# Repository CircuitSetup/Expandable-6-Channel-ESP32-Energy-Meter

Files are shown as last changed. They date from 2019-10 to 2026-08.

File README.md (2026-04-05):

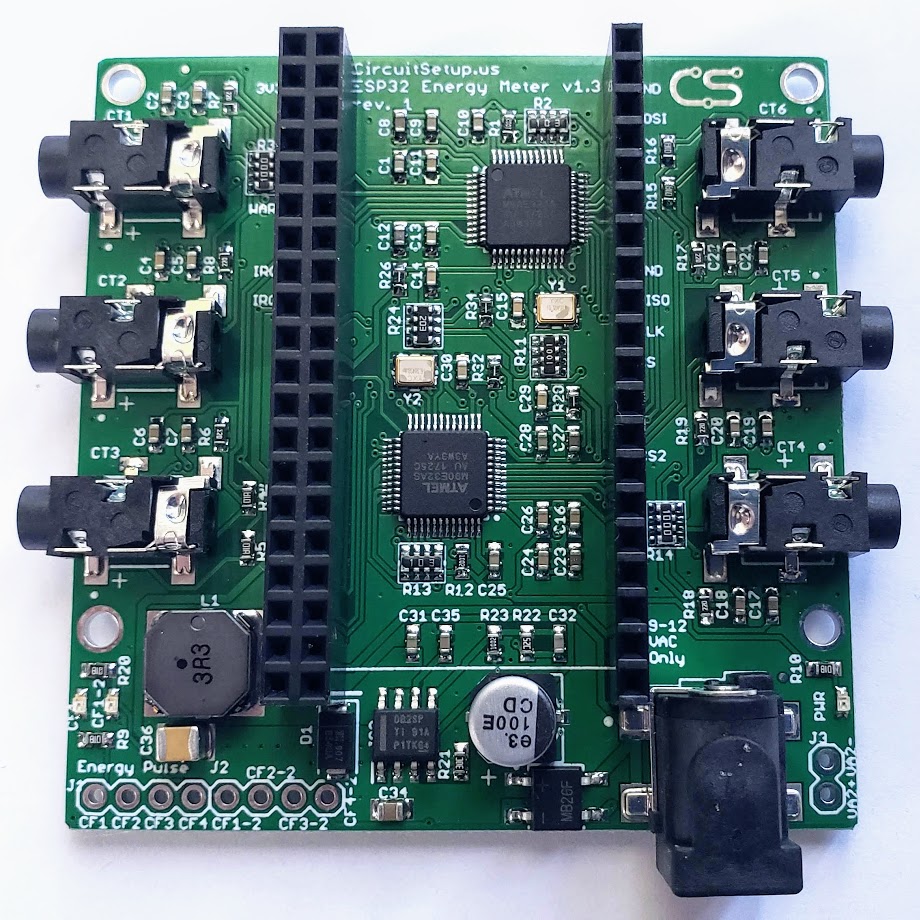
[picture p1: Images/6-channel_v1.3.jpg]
Expandable 6 Channel ESP32 Energy Meter v1.3 Main Board


# CircuitSetup Expandable 6 Channel ESP32 Energy Meter

The CircuitSetup Expandable 6 Channel ESP32 Energy Meter is a real-time power and energy monitor built around two ATM90E32AS metering ICs. The main board measures six current transformer channels and one voltage reference by default, and you can stack up to six add-on boards for a total of 42 current channels. It is a good fit for whole-home monitoring, subpanels, solar, large branch circuits, and multi-voltage or 3-phase projects.

The first AC-AC adapter powers the main board and provides the primary voltage reference. A second voltage can be measured on the main board, and stacked systems can monitor additional voltage references when the hardware is configured for it.

## Table of Contents

- [Quick Start: ESPHome via ESP Web Installer](#quick-start-esphome-via-esp-web-installer)
- [What You Will Need](#what-you-will-need)
- [Setting Up the Meter](#setting-up-the-meter)
- [Software Options](#software-options)
- [FAQ](#faq)
- [More Resources](#more-resources)

## Typical Uses

- North American split-phase 120V/240V 60Hz service: mains, solar, subpanels, and individual circuits
- Single-phase 230V/240V 50Hz or 60Hz systems with a suitable 9VAC or 12VAC AC-AC adapter
- 3-phase systems when each measured phase has the correct voltage reference

## Features

- 6 current channels on the main board
- Expandable to 42 current channels and up to 8 voltage references with add-on boards
- Built around two ATM90E32AS energy metering ICs
- Calculates active power, reactive power, apparent power, power factor, frequency, and temperature
- 16-bit measurement resolution
- 22 ohm burden resistors on each current channel
- Built-in buck converter to power the board and supported ESP32 dev boards
- SPI interface to the ESP32
- Energy pulse outputs, IRQ outputs, warning output, and zero-crossing signals are available on the board
- Typical metering IC accuracy is 0.1 percent with a 6000:1 dynamic range
- Current gain selection is available up to 4x

## Quick Start: ESPHome via ESP Web Installer

The fastest way to get the meter running is to flash ESPHome directly from the [CircuitSetup ESP Web Installer](https://circuitsetup.github.io/ESPWebInstaller/), connect it to your network, then adopt the device into Home Assistant.

### Flash Now With the Web Installer

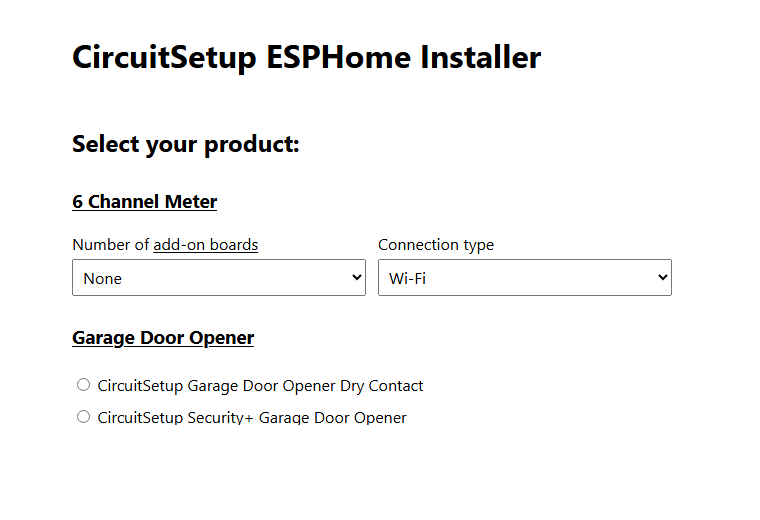
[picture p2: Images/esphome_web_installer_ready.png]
CircuitSetup ESPHome Installer options


1. Open the [CircuitSetup ESP Web Installer](https://circuitsetup.github.io/ESPWebInstaller/)
2. Under `6 Channel Meter`, choose:
   - the number of add-on boards
   - the connection type: `Wi-Fi`, `Ethernet (Lilygo)`, or `Ethernet (Waveshare)`
3. Choose the firmware version
4. Connect the ESP32 to your computer with a USB data cable
5. Click `Connect`, choose the correct serial port, and start the flash
6. If the board does not enter the bootloader automatically, hold the right or `IO0` button while the installer starts
7. If you flashed a Wi-Fi build, provision Wi-Fi after the flash
8. Once the device is online, adjust names, calibration values, and extra sensors as needed

The current Wi-Fi configs in this repo already include `captive_portal`, `esp32_improv`, and `improv_serial`, so the device can be provisioned before it is ever adopted into Home Assistant.

### Adopt Into Home Assistant/ESPHome Device Builder

If you want UI-based management, dashboard imports, OTA updates from Home Assistant, to change default meter/CT names, and do any other YAML editing, install ESPHome Device Builder after the first flash.

1. Open `Settings > Add-ons > Add-on Store`
2. Search for `ESPHome Device Builder`
3. Install it, then click `Start`
4. Click `Open Web UI`

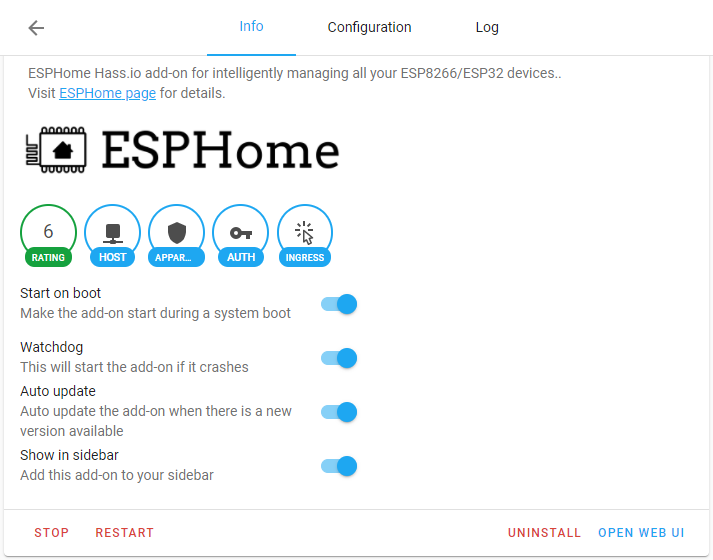
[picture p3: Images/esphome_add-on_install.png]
ESPHome add-on install


The device should then appear in ESPHome Device Builder and in Home Assistant under `Settings > Devices & services`.

For package layout, local copies, calibration files, CS-pin changes, and advanced YAML examples, see [Software/ESPHome/](Software/ESPHome/).

## What You Will Need

### Current Transformers

You can use any mix of supported CTs as long as the secondary output does not exceed 720mV RMS or 33mA. CircuitSetup CTs with mA output work directly with the board and do not require cutting the burden resistor jumpers on the back.

- [SCT-006 20A/25mA Micro CT](https://circuitsetup.us/product/20a-25ma-micro-current-transformer-yhdc-sct-006-6mm/) - 6mm opening, 3.5mm plug
- [SCT-010 80A/26.6mA Mini CT](https://circuitsetup.us/product/80a-26-6ma-mini-current-transformer-yhdc-sct-010-10mm/) - 10mm opening, 3.5mm plug
- [SCT-013-000 100A/50mA CT](https://circuitsetup.us/product/100a-50ma-current-transformer-yhdc-sct-013/) - 13mm opening, 3.5mm plug
- [SCT-016 120A/40mA CT](https://circuitsetup.us/product/120a-40ma-current-transformer-yhdc-sct-016-with-3-5mm-jack-16mm-opening/) - 16mm opening, 3.5mm plug
- [SCT-024 200A/50mA CT](https://circuitsetup.us/product/200a-50ma-current-transformer-yhdc-sct-024-24mm/) - 24mm opening, 3.5mm plug
- Magnelab SCT-0750-100 and similar voltage-output CTs can also be used, but channels using CTs with built-in burden resistors require the matching jumper trace on the back of the board to be cut

### AC-AC Transformer

The meter requires an AC output transformer, not a DC wall adapter.

- North America: [Jameco Reliapro 120V to 9VAC](https://circuitsetup.us/product/jameco-ac-to-ac-wall-adapter-transformer-9-volt-1000ma-black-straight-2-5mm-female-plug/) or a similar 9VAC or 12VAC adapter with a 2.5mm center pin
- Europe and other 230V regions: use a native 230V to 9VAC or 12VAC AC-AC adapter rated for at least 500mA. [OpenEnergyMonitor keeps a useful list here](https://learn.openenergymonitor.org/electricity-monitoring/voltage-sensing/different-acac-power-adapters)

### ESP32

Supported and documented controller options:

- [NodeMCU 32s](https://circuitsetup.us/product/nodemcu-32s-esp32-esp-wroom-32-development-board/)
- Espressif ESP32-DevKitC-32E
- Espressif ESP32-DevKitC-VIE
- Boards with the same 19-pin-per-side pinout as the boards above
- Ethernet options for ESPHome only: [CircuitSetup ESP32-S3 Ethernet Adapter](https://circuitsetup.us/product/6-channel-energy-meter-ethernet-adapter/), [LilyGO T-ETH-Lite ESP32-S3](https://www.lilygo.cc/products/t-eth-lite?variant=43120880779445), or [Waveshare ESP32-S3 ETH](https://www.waveshare.com/esp32-s3-eth.htm?sku=28972)

Boards with different pin maps are not drop-in compatible just because they are "ESP32" boards. For example, ESP32-C6 dev boards use different pins and are not part of the documented support path for this repo.
If you are comparing boards visually, the documented dev boards are usually 19 pins per side, with `3V3` at the upper-left corner and `CLK` at the lower-right corner when installed correctly.

### Software

- [ESPHome](https://esphome.io/components/sensor/atm90e32/) and [Home Assistant](https://www.home-assistant.io/integrations/esphome/) - recommended for most new installs
- [EmonESP](Software/EmonESP/readme.md) and [EmonCMS](https://emoncms.org/) - good if you want EmonCMS or MQTT without Home Assistant
- [CircuitPython library](https://github.com/BitKnitting/CircuitSetup_CircuitPython)
- [MicroPython library](https://github.com/BitKnitting/CircuitSetup_micropython)

## Setting Up the Meter

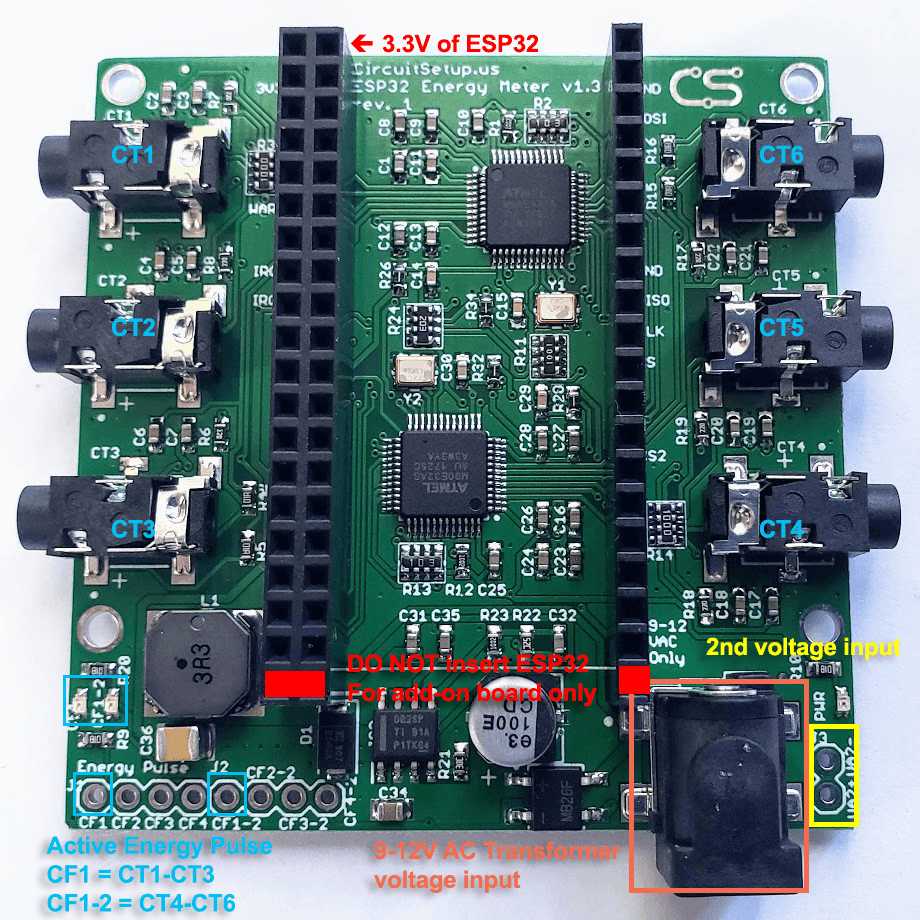
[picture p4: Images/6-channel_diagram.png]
Expandable 6 Channel ESP32 Energy Meter Diagram

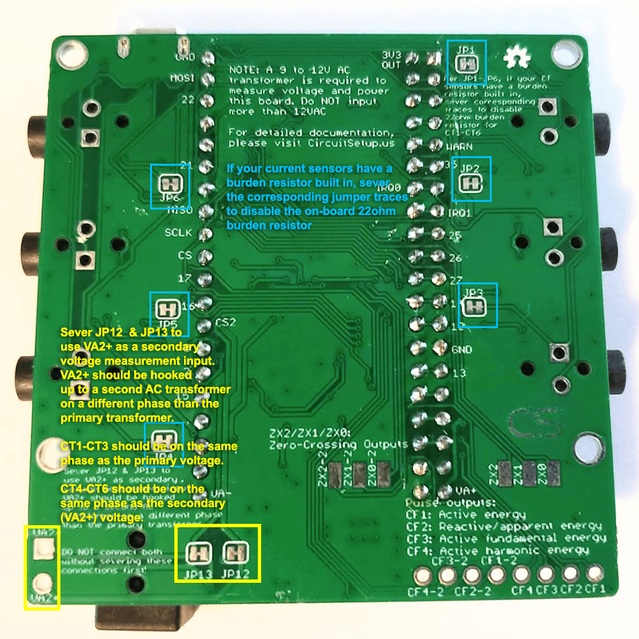
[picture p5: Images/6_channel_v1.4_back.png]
Expandable 6 Channel ESP32 Energy Meter Back Diagram


### Plugging In the ESP32

The board is designed so the ESP32 dev board plugs directly into the meter.

Always insert the ESP32 with `3V3` in the upper-left corner of the meter. The lower pins are used to pass the voltage reference to add-on boards. Plugging the ESP32 into the lower row will likely short the board.

### Main Board SPI and Chip-Select Pins

The meter communicates with the ESP32 over SPI.

Main board SPI pins:

- `CLK` - GPIO18
- `MISO` - GPIO19
- `MOSI` - GPIO23
- `CS1` - GPIO5 for CT1-CT3 and Voltage 1
- `CS2` - GPIO4 for CT4-CT6 and Voltage 2

The 6-channel version of EmonESP in this repo is already set up with the main board pin defaults. Current ESPHome configs for the main board and add-on boards are in [Software/ESPHome](Software/ESPHome).

### Add-On Boards

Each add-on board adds six more CT channels. Up to six add-on boards can be stacked on the main board.

Each add-on board has two CS jumper banks:

- `CS` for CT1-CT3 on that add-on board
- `CS2` for CT4-CT6 on that add-on board

Only choose one pin per bank. The default jumper positions used by the installer and repo configs are:

| Add-on board | `CS` for CT1-CT3 | `CS2` for CT4-CT6 |
| --- | --- | --- |
| 1st add-on | GPIO0 | GPIO16 |
| 2nd add-on | GPIO27 | GPIO17 |
| 3rd add-on | GPIO2 | GPIO21 |
| 4th add-on | GPIO13 | GPIO22 |
| 5th add-on | GPIO14 | GPIO25 |
| 6th add-on | GPIO15 | GPIO26 |

GPIO2 can interfere with programming on some ESP32 boards. If you temporarily cannot flash the ESP32 while that jumper is connected, disconnect that add-on board or move the jumper while programming, then restore the expected setting.

If you change jumper positions from the defaults, update the matching `cs_pin` values in your ESPHome config. See [Software/ESPHome/README.md](Software/ESPHome/README.md) for examples.

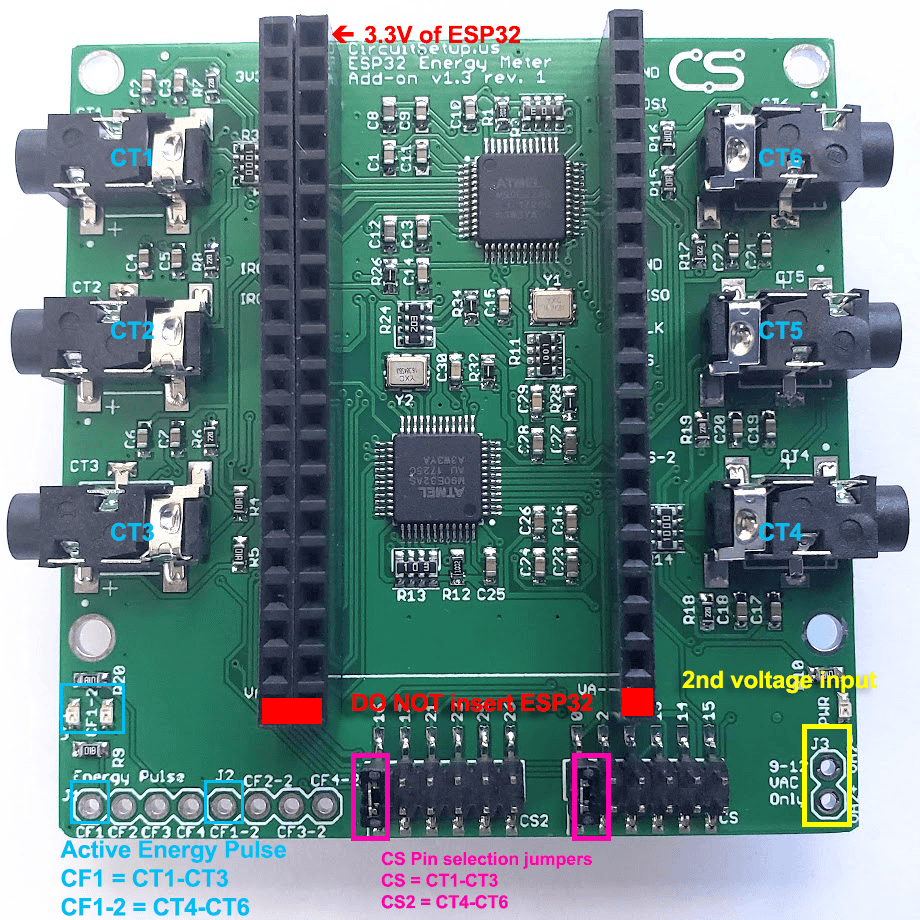
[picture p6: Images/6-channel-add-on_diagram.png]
Expandable 6 Channel ESP32 Energy Meter Add-on Diagram


### CT Compatibility, Burden Resistors, and `JP1-JP6`

Each current channel on the board has an onboard burden resistor. That is correct for CircuitSetup CTs with mA output.

Only cut the matching rear jumper trace for a CT channel if that CT already has its own burden resistor, which is usually the case for voltage-output CTs such as 1V-output models.

In practice:

- CircuitSetup SCT-006, SCT-010, SCT-013-000, SCT-016, and SCT-024 CTs do not require cutting `JP1-JP6`
- 1V-output CTs such as SCT-013-030 or SCT-013-050 do require cutting the matching jumper trace for the channel they are connected to
- If you are mixing CT types, only cut the jumper traces for the specific channels using CTs with built-in burden resistors

### Common Calibration Starting Values

Each current channel can use its own calibration value. In the current ESPHome configs that means setting `current_cal_ct1`, `current_cal_ct2`, and so on for the main board, plus the add-on board calibration variables where needed.

Common starting values:

| Sensor | Calibration value |
| --- | --- |
| SCT-006 20A/25mA | `11143` |
| SCT-013-030 30A/1V | `8650` |
| SCT-013-050 50A/1V | `15420` |
| SCT-010 50A/16.6mA | `41334` |
| SCT-010 80A/26.6mA | `41660` |
| SCT-013-000 100A/50mA | `27518` |
| SCT-016 120A/40mA | `41787` |
| SCT-024 200A/100mA | `27518` |
| SCT-024 200A/50mA | `55036` |
| Jameco 9VAC transformer | `7305` |

These are good starting points, not guaranteed final values. If you want tighter accuracy, use the ESPHome semi-automatic calibration workflow described below.

### Measuring More Than 65A on One Channel

The ATM90E32 current register tops out at `65.535A` before scaling. If you expect to measure more than that on one channel, divide the CT calibration value and multiply the reported current and power in software. Current examples are already documented in [Software/ESPHome/README.md](Software/ESPHome/README.md) and shown in [Software/ESPHome/6chan_energy_meter_main_board.yaml](Software/ESPHome/6chan_energy_meter_main_board.yaml).

For 200A service this usually means you are monitoring a larger CT but scaling it in software so the meter stays within range.

### Power Calculations and Board Revisions

The board uses voltage references to calculate power, power factor, and the other metering values.

- v1.1 used one voltage channel per ATM90E32 by default, so some power calculations had to be done in software unless registers were remapped
- v1.2 and v1.3 added `JP8-JP11` so voltage channels could be tied together. Most v1.3 boards shipped with those connections already joined
- v1.4 and later removed `JP8-JP11` and route those voltage channels internally on the PCB

### Measuring Dual-Pole 240V Circuits on Split-Phase Service

For split-phase systems, a 240V load has two hot legs. There are three practical ways to measure it:

1. Measure one hot leg with one CT and double the current and power in software. This uses the fewest channels but is the least accurate.
2. Measure each hot leg with its own CT. This is the most flexible option.
3. If the wiring layout allows it and the CT opening is large enough, pass both hot legs through a single CT in opposite directions.

If a CT is not in phase with its voltage reference, current and power will read negative. On split-phase systems that usually means the CT is flipped around the wrong conductor.

### Measuring a Second Voltage

The `VA2` pads next to the power jack on the main board, and the `VA2` pads on add-on boards, let you measure a second voltage reference.

To do that:

1. Cut `JP12` and `JP13` on v1.3 and newer boards, or `JP7` on older revisions
2. Use a second AC-AC transformer, ideally the same model as the primary one
3. Connect that second transformer to the opposite phase you want to reference
4. Add a suitable connector or pigtail to the `VA2+` and `VA2-` pads

When those voltage jumpers are cut:

- CT1-CT3 stay referenced to the primary voltage
- CT4-CT6 use the `VA2` voltage reference

That means CT4-CT6 should measure circuits on the same phase as `VA2`, or the CT direction must be reversed so the current is in phase with the voltage reference.

On add-on boards, the primary voltage normally comes from the main board. If you wire a separate `VA2` voltage reference on an add-on board, that secondary voltage is used for CT4-CT6 on that add-on board.

### Measuring 3-Phase Power

For accurate 3-phase power metering you need a matching voltage reference for each measured phase.

The cleanest 3-phase setup is:

- one main board, v1.4 or newer
- one add-on board
- three AC-AC transformers, one per phase
- headers or connectors installed on the `VA2` pads as needed
- `JP12` and `JP13` cut on the boards where separate voltage references are being used

The first transformer connected to the main board also powers the electronics and ESP32, so it should provide at least 500mA.

With that hardware:

- main board CT1-CT3 can reference phase 1
- main board CT4-CT6 can reference phase 2
- add-on board CT1-CT6 can reference phase 3, depending on how you feed voltage to that board

An alternate 3-phase approach is to use two add-on boards and feed a separate transformer into each add-on board. In that setup, the bottom `VA-` and `VA+` feed from the main board is no longer used for those add-ons, and you wire the new transformer to the `VA2` pads on each add-on instead.

If a CT is tied to a different phase than its voltage reference, active power and power factor will be wrong even if current itself looks reasonable.

## Software Options

### ESPHome and Home Assistant

ESPHome is still the recommended software path. If you just want to get firmware onto the meter, use the quick-start section above. The rest of this section covers what the maintained ESPHome configs already include after the device is flashed.

Useful references:

- [Getting Started with ESPHome and Home Assistant](https://esphome.io/guides/getting_started_hassio/)
- [ESPHome ATM90E32 docs](https://esphome.io/components/sensor/atm90e32/)

### What the Default ESPHome Config Already Includes

The current repo configs are built for the current ESPHome workflow, not the older legacy setup:

- `dashboard_import` so the device can be adopted into ESPHome Device Builder
- `name_add_mac_suffix: true` so multiple identical meters do not collide on the network
- `ota: - platform: esphome` for current OTA updates
- `captive_portal`, `esp32_improv`, and `improv_serial` on Wi-Fi builds for provisioning
- `time: - platform: homeassistant` in the shared packages used by the standard configs

After the first flash:

- Wi-Fi builds can be provisioned from the browser, via Improv, or through the fallback captive portal if the device is not yet on your network
- Ethernet builds come up on your wired network once flashed and connected
- The device should appear in ESPHome Device Builder and in Home Assistant under `Settings > Devices & services`
- You can edit the imported YAML inside ESPHome Device Builder, or copy the files locally from [Software/ESPHome](Software/ESPHome) if you prefer to manage everything yourself

If you want the maintained package-based configs, start from the files in [Software/ESPHome](Software/ESPHome). If you want more control, use [Software/ESPHome/README.md](Software/ESPHome/README.md) as the advanced reference for package layout, calibration files, CS-pin changes, and example configs.

### ESPHome Calibration

Default calibration values are usually good enough to get started, but calibration is strongly recommended if you are using custom CTs, a different AC-AC transformer, longer CT leads, or if you want especially accurate readings.

On the main board, calibration is done through two separate ATM90E32 chips, not one 6-channel block. `main_meter_id1` / `Meter 1-3` handles CTs `1-3`, and `main_meter_id2` / `Meter 4-6` handles CTs `4-6`. Each `Run ... Calibration` button in Home Assistant acts on only one of those chips, so calibrate CTs `1-3` and CTs `4-6` separately.

In the CircuitSetup YAML, the normal starting points are `current_cal_ct1` through `current_cal_ct6`, plus `voltage_cal1` and `voltage_cal2` in the top-level config file you flashed or imported from [Software/ESPHome](Software/ESPHome). Under the hood, those map to ESPHome's `gain_ct` and `gain_voltage` values for each ATM90E32 phase. [Software/ESPHome/calibration/6chan_main_calibration.yaml](Software/ESPHome/calibration/6chan_main_calibration.yaml) adds the Home Assistant calibration buttons and the runtime reference number entities. [Software/ESPHome/calibration/6chan_main_offset_calibrations.yaml](Software/ESPHome/calibration/6chan_main_offset_calibrations.yaml) is where copied offset values can be persisted in YAML.

To use the semi-automatic calibration workflow, make sure `offset_calibration` and `gain_calibration` are set to `"true"` and that the calibration package is included. After the meter is adopted into Home Assistant, open the meter device page. There you will see:

- `${main_meter_name1} Ref V 1` and `CT1 Ref Current` through `CT3 Ref Current` for the first ATM90E32
- `${main_meter_name2} Ref V 2` and `CT4 Ref Current` through `CT6 Ref Current` for the second ATM90E32
- `Run ... Offset Cal`, `Run ... Power Offset Cal`, `Run ... Gain Cal`, and matching `Clear ...` buttons for each chip

If you renamed the meter groups in YAML, the button labels will follow those names instead of the default `Meter 1-3` and `Meter 4-6`.

In practice:

- gain calibration fixes scaling when the meter reads high or low under a known load
- offset calibration fixes false zero-level readings when current or voltage should be at or very near zero
- power-offset calibration fixes false power readings when voltage is present but CT current is zero

Recommended workflow:

1. Start with the closest known values for your CTs and AC transformer by setting `current_cal_ct1` through `current_cal_ct6` and `voltage_cal1`/`voltage_cal2` to the nearest matching starting values.
2. Open the meter device page in Home Assistant and choose which ATM90E32 you are calibrating: `Meter 1-3` for CTs `1-3`, or `Meter 4-6` for CTs `4-6`. For that chip, phase A/B/C in the ESPHome logs correspond to CT1/CT2/CT3 or CT4/CT5/CT6 respectively.
3. For gain calibration, restore the meter to normal wiring, apply a stable known load, and use a trusted reference meter or clamp meter to get the real voltage and current. Enter that chip's real voltage into its `Ref V` field. For the CircuitSetup 6-channel meter, that reference voltage is used across that chip's phases. Then enter the real current into the matching `CTx Ref Current` field for each CT you want to calibrate.
4. Press that chip's `Run ... Gain Cal` button. ESPHome then logs a calibration table showing phase A/B/C, measured voltage, measured current, reference voltage, reference current, and the old-to-new `V_gain` and `I_gain` values for that chip. If a reference voltage or reference current is left at `0`, ESPHome skips recalculating that part and logs a warning instead.
5. Open the ESPHome logs and copy the reported values back into YAML. In the standard workflow that means opening `LOGS` in ESPHome Device Builder for the device, but serial logs or `esphome logs` work too. For `Meter 1-3`, map the logged gain results back to `voltage_cal1` and `current_cal_ct1` through `current_cal_ct3`. For `Meter 4-6`, map them back to `voltage_cal2` and `current_cal_ct4` through `current_cal_ct6`.
6. Only run offset calibration if idle baselines are not clean. For this step, the ATM90E32 button code and docs both expect current and voltage inputs to be at `0`, so the practical approach is USB power only with the AC transformer and CTs disconnected. Press the matching `Run ... Offset Cal` button for the chip you want to clean up. The logs will show a table of `offset_voltage` and `offset_current` for phases A/B/C on that chip.
7. Only run power-offset calibration if power still shows a small non-zero value with voltage present but CT current at zero. For this step, the voltage reference should be connected but CT current should be `0`. Press that chip's `Run ... Power Offset Cal` button. The logs will show `offset_active_power` and `offset_reactive_power` for phases A/B/C on that chip.
8. If you want offset values persisted in config, copy them into [Software/ESPHome/calibration/6chan_main_offset_calibrations.yaml](Software/ESPHome/calibration/6chan_main_offset_calibrations.yaml). ESPHome's button logs refer to `gain_ct`, `gain_voltage`, `offset_voltage`, `offset_current`, `offset_active_power`, and `offset_reactive_power` under each `phase_x`; in this repo those results map back to the `current_cal_ctX` and `voltage_cal1/2` substitutions plus the offset include file.
9. After those values are saved in YAML, press the matching `Clear ...` buttons for that same chip so the temporary calibration values stored in flash no longer override your YAML. The component stores gain, offset, and power-offset calibration values in memory and applies them immediately, so clearing them is the step that hands control back to the YAML values.

What the logs will show:

- gain calibration logs a table with `V_meas (V)`, `I_meas (A)`, `V_ref`, `I_ref`, `V_gain (old→new)`, and `I_gain (old→new)` for phases A/B/C of the selected chip
- offset calibration logs a table of `offset_voltage` and `offset_current` for phases A/B/C of the selected chip
- power-offset calibration logs a table of `offset_active_power` and `offset_reactive_power` for phases A/B/C of the selected chip
- the button press itself also logs guidance such as `Use gain_ct: & gain_voltage:` or `Use offset_voltage: & offset_current:` and reminds you about the required wiring conditions for offset and power-offset calibration

The key output from semi-automatic calibration is written to the ESPHome logs through `logger`, not into the Home Assistant entity state itself. The normal CircuitSetup workflow is: run the correct chip's calibration button from the Home Assistant device page, watch the output in ESPHome Device Builder `LOGS`, copy the values into YAML, clear the stored chip calibration for that same button group, then reboot or reload and verify against your reference meter.

Useful references:

- [ESPHome ATM90E32 calibration docs](https://esphome.io/components/sensor/atm90e32/#calibration)
- [Software/ESPHome/README.md](Software/ESPHome/README.md)

### Home Assistant Energy Dashboard

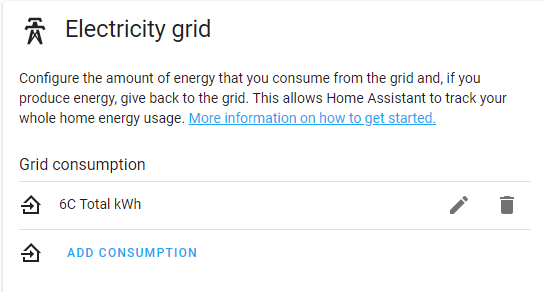
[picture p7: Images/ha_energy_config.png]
Home Assistant Energy Config


The current repo configs already use the right Home Assistant time source and current energy-sensor metadata. If you are building your own sensors, use the same pattern as the current configs:

```yaml
sensor:
  - platform: total_daily_energy
    name: ${friendly_name} Total kWh
    power_id: totalWattsMain
    filters:
      - multiply: 0.001
    unit_of_measurement: kWh
    device_class: energy
    state_class: total_increasing
```

If you are using the standard package configs in this repo, `time: - platform: homeassistant` is already included and does not need to be added again.

Helpful example configs:

- Main board only: [Software/ESPHome/6chan_energy_meter_main_board.yaml](Software/ESPHome/6chan_energy_meter_main_board.yaml)
- Solar plus house example: [Software/ESPHome/examples/6chan_energy_meter_house_solar_ha_kwh.yaml](Software/ESPHome/examples/6chan_energy_meter_house_solar_ha_kwh.yaml)
- 3-phase example: [Software/ESPHome/examples/6chan_energy_meter_3-phase_ethernet.yaml](Software/ESPHome/examples/6chan_energy_meter_3-phase_ethernet.yaml)

In Home Assistant:

1. Open `Settings > Energy`
2. Add your total import sensor under the electricity grid section
3. Add return-to-grid and solar production sensors if you are tracking export or generation
4. Add per-circuit energy sensors if you want individual device or branch circuit tracking

### Optional: InfluxDB and Grafana

If you want long-term storage outside the default Home Assistant recorder, the easiest path is to expose the meter data to Home Assistant first and then use the Home Assistant InfluxDB integration.

- [Home Assistant InfluxDB integration](https://www.home-assistant.io/integrations/influxdb/)

### EmonESP and EmonCMS

EmonESP is still a good option if your main goal is sending data to a local EmonCMS install, [emoncms.org](https://emoncms.org/), or MQTT without making Home Assistant the center of the system.

The 6-channel EmonESP files in this repo already include the correct pin defaults for the main board and support calibration changes from the web UI.

Key points:

- You must use an ESP32
- You can build it with Arduino IDE or PlatformIO
- It requires the [CircuitSetup ATM90E32 Arduino library](https://github.com/CircuitSetup/ATM90E32)
- The 6-channel-specific notes are in [Software/EmonESP/readme.md](Software/EmonESP/readme.md)
- The broader EmonESP setup flow is documented here: [Split Single Phase EmonESP setup](https://github.com/CircuitSetup/Split-Single-Phase-Energy-Meter/tree/master/Software/EmonESP)

If you need separate voltage calibration for a specific add-on-board voltage channel in EmonESP, note the local EmonESP readme: by default the add-on voltage channel uses the main board calibration unless you define a separate variable in `energy_meter.cpp`.

### CircuitPython and MicroPython

If you want to build your own application stack instead of using ESPHome or EmonESP, these community libraries are available:

- [CircuitSetup CircuitPython library](https://github.com/BitKnitting/CircuitSetup_CircuitPython)
- [CircuitSetup MicroPython library](https://github.com/BitKnitting/CircuitSetup_micropython)

## FAQ

**Q: One CT is reading low, or not reading at all. What should I check first?**

**A:** First make sure the CT plug is fully seated. The jacks can be tight, and the connector often needs to be pushed in until it clicks. If one channel still reads low after that, swap CTs between channels to find out whether the issue follows the CT or stays with the board jack.

**Q: Does the 6-channel meter work outside North America?**

**A:** Yes. Set the line frequency for your system and use the correct AC-AC transformer for your mains voltage. For 230V or 240V systems, use a native 230V to 9VAC or 12VAC adapter when possible instead of a step-down transformer plus a US wall adapter.

**Q: Can I use a 230V to 120V step-down transformer with a US 9VAC adapter?**

**A:** It can work, but it is not the preferred setup. A native 230V to 9VAC or 12VAC AC-AC adapter is simpler, cleaner, and usually the better long-term choice. If you do use a different adapter, plan to calibrate the voltage.

**Q: I am getting a negative value on one current channel. What is happening?**

**A:** The CT is usually backwards on the conductor. Turn the CT around. If every CT is negative, the AC transformer phase is probably reversed.

**Q: I see a small negative value at no load, but positive values under load. Is that normal?**

**A:** That is usually offset error, not a wiring failure. Run the voltage and current offset calibration in ESPHome if you want the cleanest fix. If you just need to clamp small negative values to zero in a template, that is also possible, but offset calibration is the better solution.

**Q: Can I extend the CT wires?**

**A:** Yes. A short 3.5mm extension cable or a clean custom extension usually works fine. After adding a longer run, recalibrate if you want the best accuracy.

**Q: Can I use other CTs with this meter?**

**A:** Usually yes, as long as the CT secondary output stays within the supported range. The important limits are the CT output, not the brand name. If the CT has a built-in burden resistor or a voltage output such as 1V, cut the matching jumper trace on the board for that channel.

**Q: Can I use SCT-024 200A CTs on the 6-channel meter?**

**A:** Yes, but you still need to respect the meter input range. With the newer 200A/50mA SCT-024, the practical maximum current you should measure directly without additional scaling is about 132A on one channel. If you need to monitor more than that, use the software scaling approach described above.

**Q: How do I know whether to cut `JP1-JP6`?**

**A:** Leave the jumper trace intact for mA-output CTs such as CircuitSetup SCT-006, SCT-010, SCT-013-000, SCT-016, and SCT-024. Cut the matching jumper trace only for channels using CTs with built-in burden resistors, which usually means voltage-output CTs such as 1V models.

**Q: Do CTs need mono 3.5mm plugs, or will stereo plugs work?**

**A:** The board uses the CT signal on the tip and sleeve. A CT with a stereo 3.5mm plug usually works fine as long as the CT output is wired correctly and the electrical output itself is compatible. The plug style matters less than the CT secondary type and wiring.

**Q: Can I mix different CT types on one meter?**

**A:** Yes. That is a common setup. Give each current channel the correct calibration value for the CT on that channel. Do not assume the same calibration applies to every CT just because they are on the same board.

**Q: My add-on board shows `NA`, or I see `connection to ATM90E32 failed`. What should I check?**

**A:** Start with the basics:

- confirm you flashed the firmware for the correct add-on count
- confirm the add-on board jumper positions match the expected CS pair for that stack position
- confirm the add-on board is fully seated
- if you changed jumper positions, confirm the matching `cs_pin` values were also changed in ESPHome

If the main board works by itself and both boards stop reporting as soon as the add-on is installed, the jumper selection or physical seating is usually the first thing to verify.

**Q: Which ESP32 dev boards are supported?**

**A:** Use a NodeMCU 32s, an ESP32-DevKitC-32E, an ESP32-DevKitC-VIE, or another board with the same pinout. Ethernet is supported with the documented LilyGO or Waveshare ESP32-S3 options plus the proper adapter and matching YAML. Boards with different pin maps, including ESP32-C6 dev boards, are not documented drop-in replacements for this repo.

**Q: Can I connect the meter to Ethernet?**

**A:** Yes, with the documented ESPHome Ethernet options. Start with:

- [Software/ESPHome/6chan_energy_meter_main_ethernet.yaml](Software/ESPHome/6chan_energy_meter_main_ethernet.yaml)
- [Software/ESPHome/6chan_energy_meter_main_ethernet_waveshare.yaml](Software/ESPHome/6chan_energy_meter_main_ethernet_waveshare.yaml)

Use the matching firmware in the web installer for `Ethernet (Lilygo)` or `Ethernet (Waveshare)`.

**Q: How do I set up solar and return-to-grid tracking?**

**A:** Use separate power calculations for house import, solar generation, and return-to-grid export. The best starting point is the maintained example here:

- [Software/ESPHome/examples/6chan_energy_meter_house_solar_ha_kwh.yaml](Software/ESPHome/examples/6chan_energy_meter_house_solar_ha_kwh.yaml)

**Q: How can I do calculations across two different meters in Home Assistant?**

**A:** Create a template helper or template sensor in Home Assistant and do the math there. Use each meter's total power or energy sensor as inputs, then expose the calculated sensor back to the Energy dashboard if needed.

**Q: My older ESPHome config no longer compiles after updating ESPHome. What is the easiest fix?**

**A:** The repo has moved forward with the current ESPHome workflow, including `esp-idf`, `dashboard_import`, current OTA syntax, and the maintained package structure in [Software/ESPHome](Software/ESPHome). The fastest path is usually to start from the current repo config or reflash with the [CircuitSetup ESP Web Installer](https://circuitsetup.github.io/ESPWebInstaller/) and then merge your custom names and calibration values back in.

## More Resources

- [CircuitSetup ESP Web Installer](https://circuitsetup.github.io/ESPWebInstaller/)
- [ESPHome ATM90E32 docs](https://esphome.io/components/sensor/atm90e32/)
- [Getting Started with ESPHome and Home Assistant](https://esphome.io/guides/getting_started_hassio/)
- [Home Assistant ESPHome integration](https://www.home-assistant.io/integrations/esphome/)
- [Home Assistant Energy docs](https://www.home-assistant.io/docs/energy/)
- [Software/ESPHome/README.md](Software/ESPHome/README.md)
- [Software/EmonESP/readme.md](Software/EmonESP/readme.md)
- [Digiblur video on calibration and ESPHome setup](https://www.youtube.com/watch?v=BOgy6QbfeZk)
- [DIY Home Power and Solar Energy Dashboard with Home Assistant and ESPHome](https://www.youtube.com/watch?v=n2XZzciz0s4)
- [TH3D video with add-on board setup](https://www.youtube.com/watch?v=zfB4znO6_Z0)

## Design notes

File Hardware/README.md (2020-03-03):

## Expandable 6 Channel Energy Meter Change Log
**3/2/2020 - v1.4 rev1**
- Changed micro-hdmi connector to through-hole
- Changed spacing on VA2+/VA2- (voltage 2 connection) to 3.5mm to allow for standard screw connectors

**12/16/2019 – v1.4**
- Added optional micro-hdmi connection to connect the current transformer remote board. This allows for all 6 current transformer connections to connect to a remote pcb, which then connects to the main board via 1 micro-hdmi cable. Instead of 6 wires coming out of the meter, there can now be 1.
- Added current transformer remote pcb
- Removed JP8-JP11 and connected all voltage channels together for each ATM90E32

**10/15/2019 – v1.3 rev1**
- Added voltage divider on ground for voltage channel 2
- Added JP12 & JP13 to disconnect voltage channel 1 from 2

**10/1/2019 – v1.3**
- Added voltage divider on ground for voltage channel 1
- Added 20k pullup for voltage channel 1
- Changed all voltage dividers to 20k and 1k so voltage input from a 12v AC transformer is around 650mV - this allows more voltage in than previous versions, lowering the voltage calibration
- Removed C37

**8/1/2019 – v1.2**
- Added C37 to connect neutral and DC ground
- Added solder jumpers JP8JP12 to connect all voltage channel inputs together

**6/1/2019 – v1.1**
- Initial public release

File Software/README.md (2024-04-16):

### Software
The following are various implementations that can be used with the 6 Channel Energy Meter. Instructions for [setting up software for the meter is located here](https://github.com/CircuitSetup/Expandable-6-Channel-ESP32-Energy-Meter#setting-up-software).
- ESPHome - Example configuration files
- EmonCMS - Device config files (these are now included with the device module for EmonCMS)
- EmonESP - ESP software that runs on the meter's ESP32, and sends data to EmonCMS or via MQTT
- Grafana - Dashboard examples

### Libraries
These are used to communicate directly with the ATM90E32 IC's used with the 6 channel meter. If you want to build your own software, you will need one of these.
- [Arduino/ESP32](https://github.com/CircuitSetup/ATM90E32)
- [CircuitPython](https://github.com/BitKnitting/CircuitSetup_CircuitPython)
- [MicroPython](https://github.com/BitKnitting/CircuitSetup_micropython)

### User Created Projects
- [CS/ESPHome](https://github.com/sillygoose/cs_esphome) - Python data collection utility. Sensor data is sourced using the ESPHome API and stored in an InfluxDB database. Grafana dashboard included.
- [ESPSense](https://github.com/cbpowell/ESPSense) - Can be used to send 6 Channel Energy Meter data via ESPHome to your Sense Home Energy Monitor software
- [Raspberry Pi to MQTT](https://github.com/tsaitsai/circuitsetup_energy_to_mqtt) - Hook up a 6 channel meter to a Raspberry Pi (in place of an ESP32) and send data over MQTT
- [6 Channel Energy Meter with a wired ethernet connection (WT32-ETH01)](https://community.home-assistant.io/t/wt32-eth01-with-esphome-driving-circuitsetup-expandable-6-channel-esp32-energy-meter-main-board/709027) - Wiring and ESPHome config for using the 6 channel meter with ethernet instead of WiFi.

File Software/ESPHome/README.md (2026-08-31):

# ESPHome Configuration for Expandable 6-Channel ESP32 Energy Meter

This folder contains [ESPHome](https://esphome.io) configuration files used to monitor power and energy via the CircuitSetup Expandable 6-Channel Energy Meter. These configurations support flexible deployments - with or without add-on boards - as well as Wi-Fi or Ethernet connections. Many files use `!include` statements to modularize calibration, sensor definitions, power quality metrics, and device status.

---

## Compiled Firmware

[See here to flash your ESP32](https://circuitsetup.github.io/ESPWebInstaller/)

---

## 📁 Base Config Files

| File | Description |
|---|---|
| `6chan_common.yaml` | Base shared configuration: sets platform (`esp32`), SPI, includes time and API components. Meant to be included in Wi-Fi-based setups. |
| `6chan_common_ethernet.yaml` | Same as `6chan_common.yaml`, but for the [Lilygo T-ETH-Lite ESP32S3](https://lilygo.cc/products/t-eth-lite) and the [CircuitSetup 6 Channel Energy Meter Ethernet Adapter](https://circuitsetup.us/product/6-channel-energy-meter-to-lilygo-t-eth-lite-esp32s3-ethernet-adapter/) . |
| `6chan_common_ethernet_waveshare.yaml` | Ethernet base config for the Waveshare ESP32-S3-ETH and CircuitSetup Ethernet WS adapter. |
| `6chan_energy_meter_main_board.yaml` | Full configuration for monitoring only the main board's 6 channels via Wi-Fi. |
| `6chan_energy_meter_main_ethernet.yaml` | Ethernet-based variant of `6chan_energy_meter_main_board.yaml` (Lilygo adapter). |
| `6chan_energy_meter_main_ethernet_waveshare.yaml` | Ethernet-based variant of `6chan_energy_meter_main_board.yaml` (Waveshare adapter). |
| `6chan_energy_meter_1-addon.yaml` | Main board + 1 add-on board (12 channels) over Wi-Fi. |
| `6chan_energy_meter_1-addon_ethernet.yaml` | Main board + 1 add-on board (12 channels) over Ethernet (Lilygo adapter). |
| `6chan_energy_meter_1-addon_ethernet_waveshare.yaml` | Main board + 1 add-on board (12 channels) over Ethernet (Waveshare adapter). |
| `6chan_energy_meter_2-addons.yaml` | Main board + 2 add-on boards (18 channels) over Wi-Fi. |
| `6chan_energy_meter_2-addons_ethernet.yaml` | Main board + 2 add-on boards (18 channels) over Ethernet (Lilygo adapter). |
| `6chan_energy_meter_2-addons_ethernet_waveshare.yaml` | Main board + 2 add-on boards (18 channels) over Ethernet (Waveshare adapter). |
| `6chan_energy_meter_3-addons.yaml` | Main board + 3 add-on boards (24 channels) over Wi-Fi. |
| `6chan_energy_meter_3-addons_2-voltages.yaml` | Main board + 3 add-on boards (24 channels) with second-voltage monitoring enabled. |
| `6chan_energy_meter_3-addons_ethernet.yaml` | Main board + 3 add-on boards (24 channels) over Ethernet (Lilygo adapter). |
| `6chan_energy_meter_3-addons_ethernet_waveshare.yaml` | Main board + 3 add-on boards (24 channels) over Ethernet (Waveshare adapter). |
| `6chan_energy_meter_4-addons.yaml` | Main board + 4 add-on boards (30 channels) over Wi-Fi. |
| `6chan_energy_meter_4-addons_ethernet.yaml` | Main board + 4 add-on boards (30 channels) over Ethernet (Lilygo adapter). |
| `6chan_energy_meter_4-addons_ethernet_waveshare.yaml` | Main board + 4 add-on boards (30 channels) over Ethernet (Waveshare adapter). |
| `6chan_energy_meter_5-addons.yaml` | Main board + 5 add-on boards (36 channels) over Wi-Fi. |
| `6chan_energy_meter_5-addons_ethernet.yaml` | Main board + 5 add-on boards (36 channels) over Ethernet (Lilygo adapter). |
| `6chan_energy_meter_5-addons_ethernet_waveshare.yaml` | Main board + 5 add-on boards (36 channels) over Ethernet (Waveshare adapter). |
| `6chan_energy_meter_6-addons.yaml` | Main board + 6 add-on boards (42 channels) over Wi-Fi. |
| `6chan_energy_meter_6-addons_ethernet.yaml` | Main board + 6 add-on boards (42 channels) over Ethernet (Lilygo adapter). |
| `6chan_energy_meter_6-addons_ethernet_waveshare.yaml` | Main board + 6 add-on boards (42 channels) over Ethernet (Waveshare adapter). |

---

## Helper configuration contract

Official top-level meter configurations publish `csemh_config_contract: "2"`.
Generic add-on totals use stable IDs `totalAmps`, `totalWatts`, and
`totalEnergyDaily`. Main-only configurations retain `totalAmpsMain` and
`totalWattsMain`, plus `totalEnergyDaily`. Status text entities are
diagnostic and disabled by default so the helper can manage their visibility
consistently.

Manually composed ESPHome configurations may retain or include the full
power-quality set, including harmonic power and peak current. CircuitSetup
Energy Meter Helper intentionally omits harmonic power and peak current from
its managed configuration.

---

## 📂 calibration/

When these files are included, and calibration is enabled, semi-automatic calibration can be done for each current and voltage channel by providing a current and voltage reference. Calculated values for offset and gain stored in memory take priority over config values.
To save calculated calibration values, copy them from the ESPHome logs to your config then use the clear buttons to clear the calibration values from memory

[See details on semi-automatic calibrations here](https://esphome.io/components/sensor/atm90e32.html#calibration)

| File | Description |
|---|---|
| `6chan_xxxx_calibration.yaml` | Enables calibration buttons for gain, power offset, current/voltage offset, and clear buttons for each |
| `6chan_xxxx_offset_calibrations.yaml` | Offset calibration values fine tuned via the output of the semi-automatic calibrations. Values should be copied in from the meter's ESPHome log |

---

## 📂 meter_sensors/

Default current, power (watts), and voltage sensor entities per meter board
[More details on each sensor here](https://esphome.io/components/sensor/atm90e32.html#configuration-variables)

---

## 📂 status_fields/

These fields display the status of each CT, or phase, with a short text description. [See more details here](https://esphome.io/components/sensor/atm90e32.html#text-sensor)

---

## 📂 power_quality/

Contains power quality values that are available for each phase, and can be enabled per meter board. Enabling these on every current channel is possible, but will produce a lot of data and sensors that are likely not needed. They include reactive_power, apparent_power, harmonic_power, power_factor, phase_angle, peak_current
[More details on each sensor here](https://esphome.io/components/sensor/atm90e32.html#configuration-variables)

---

## 📂 examples/

Pre-configured use cases to jumpstart your setup.

| File | Description |
|---|---|
| `6chan_energy_meter_3-phase_ethernet.yaml` | Configuration for 3-phase measurement with Ethernet. Uses main board + 1 add-on. |
| `6chan_energy_meter_6-addons_ethernet.yaml` | Max configuration: main board + 6 add-ons over Ethernet (42 channels). |
| `6chan_energy_meter_house_solar_ha_kwh.yaml` | Real-world example measuring house + solar circuits. |
| `6chan_main_calibration_beta.yaml` | Beta calibration test — for experimentation only, not recommended for production. |

---

## Measuring More Than 65A on a Current Channel
The max value for current that the meter can output is 65.535. If you expect to measure current over 65A, divide `current_cal_ctx` by 2 (120A CT) or 4 (200A CT) and multiply the current and power values by 2 or 4, uncommenting the below and changing the `id` and `phase_x` accordingly.

Under `sensor:` add:
```
- id: !extend ${main_meter_id1} # CTs 1-3 
  phase_a: # CT1
    current:
      filters:
        - multiply: 2
    power:
      filters:
        - multiply: 2
```
---

## Measuring Solar Return to Grid Power
The meter reads negative watts on mains as power that is being sent back to the grid. In other words, this is excess power that you are not using. To read this properly you can add templates to your config that look like this. These sensors can then be mapped to Home Assistant's Energy Dashboard. This assumes 2 CTs measuring mains are on CT1 (`ct1Watts`) and CT2 (`ct2Watts`)

```
#Total House Watts
- platform: template
  name: Total House Watts
  id: totalHouseWatts
  lambda: return id(ct1Watts).state + id(ct2Watts).state ;
  accuracy_decimals: 2
  unit_of_measurement: W
  device_class: power
  state_class: measurement
  update_interval: ${update_time}

#Total House Return to Grid Watts
  - platform: template
    name: Total House Return To Grid Watts
    id: returnToGridWatts
    lambda: |-
      if (id(totalHouseWatts).state > 0) {
        return 0;
      } else {
        return abs(id(totalHouseWatts).state) ;
      }
    accuracy_decimals: 2
    unit_of_measurement: W
    device_class: power
    state_class: measurement
    update_interval: ${update_time}
    
#House kWh Return to Grid
  - platform: total_daily_energy
    name: House Return To Grid kWh
    power_id: returnToGridWatts
    filters:
      - multiply: 0.001
    unit_of_measurement: kWh
    device_class: energy
    state_class: total_increasing
    
 #Total House Watts Usage
  - platform: template
    name: Total House Positive Watts
    id: totalHousePositiveWatts
    lambda: |-
      if (id(totalHouseWatts).state < 0) {
        return 0;
      } else {
        return id(totalHouseWatts).state ;
      }
    accuracy_decimals: 2
    unit_of_measurement: W
    device_class: power
    state_class: measurement
    update_interval: ${update_time}
    
#House positive kWh
  - platform: total_daily_energy
    name: House kWh
    power_id: totalHousePositiveWatts
    filters:
      - multiply: 0.001
    unit_of_measurement: kWh
    device_class: energy
    state_class: total_increasing
```
---

## Monitoring More Than 1 Voltage
By default, all voltage channels are connected, and set up to monitor a single phase. [See here on what needs to be done with hardware if monitoring more than 1 voltage.](https://github.com/CircuitSetup/Expandable-6-Channel-ESP32-Energy-Meter/tree/master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)

In the config, under `sensor:` add:
```
- id: !extend ${main_meter_id2}
  phase_a:
    voltage:
       name: Voltage 2
       id: ic2Volts
       accuracy_decimals: 1
  frequency:
    name: Frequency 2
```
---

## Excluding/Removing Sensors
If you, for example, want to see power quality sensors on only 2 out of the 4 CT channels of the main board, you could add something like this in your base config file. This is assuming you are including `Software/ESPHome/power_quality/6chan_main_power_quality.yaml` and you want to exclude power quality sensors for the last 4 CTs:

Under `sensor:` add:
```
- id: !extend ${main_meter_id1}
  phase_c: # CT3
    reactive_power: !remove
    apparent_power: !remove
    harmonic_power: !remove
    power_factor: !remove
    phase_angle: !remove
    peak_current: !remove

- id: !extend ${main_meter_id2}
  phase_a: # CT4
    reactive_power: !remove
    apparent_power: !remove
    harmonic_power: !remove
    power_factor: !remove
    phase_angle: !remove
    peak_current: !remove
  phase_b: #CT5
    reactive_power: !remove
    apparent_power: !remove
    harmonic_power: !remove
    power_factor: !remove
    phase_angle: !remove
    peak_current: !remove
  phase_c: #CT6
    reactive_power: !remove
    apparent_power: !remove
    harmonic_power: !remove
    power_factor: !remove
    phase_angle: !remove
    peak_current: !remove
```
---

## Changing Default CS Pins
If you've changed the jumpers on add-on board(s) from the default, they can be changed by adding the following to your main config under ```sensor:```:
```
- id: !extend ${addon1_id1} #1st add-on, CTs 1-3
  cs_pin: 16 #change to match physical jumper position

- id: !extend ${addon2_id2} #2nd add-on, CTs 4-6
  cs_pin: 27
```
---

## Including Files Locally
You can copy config files to your local directories and change the `packages:` part of your config to something like this:
```
packages:
  common: !include Software/ESPHome/6chan_common.yaml
  main: !include Software/ESPHome/meter_sensors/6chan_main_sensor.yaml
  main_status: !include Software/ESPHome/status_fields/6chan_main_status.yaml
  main_cal: !include Software/ESPHome/calibration/6chan_main_calibration.yaml
```
---

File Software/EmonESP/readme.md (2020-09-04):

### EmonESP

EmonESP sends energy meter data to [EmonCMS](https://emoncms.org/), or MQTT. This version has configuration settings for the 6 channel meter, and includes calibration settings that are able to be changed via the web interface. 

Some notes: 
- You must use an ESP32
- To compile, you must have the [ATM90E32 Arduino library](https://github.com/CircuitSetup/Split-Single-Phase-Energy-Meter/tree/master/Software/libraries/ATM90E32) in your Arduino libraries folder.
- If you need to calibrate a specific voltage channel on an add-on board, by default the values from the main board calibration are used, so they would need to have a seperate variable defined, and set manually in energy_meter.cpp

For details on setup, please see the [readme under the Split Single Phase Energy Meter.](https://github.com/CircuitSetup/Split-Single-Phase-Energy-Meter/tree/master/Software/EmonESP)

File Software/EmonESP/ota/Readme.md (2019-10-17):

This php script has been lifted from [@squix78's project](https://github.com/squix78/esp8266-ci-ota), see [blog post](http://blog.squix.org/2016/06/esp8266-continuous-delivery-pipeline-push-to-production.html). Thanks a lot to Daniel Eichhorn for developing the ESP OTA CONTINUOUS DELIVERY workflow.

From @squi78's blog:

> ## The PHP script

> It would have been nice if the production ESPs could have contacted the Github API directly. But there are two issues that made be use the intermediate PHP script:

> - The ESPhttpUpdate currently cannot follow redirects. This is important since github hosts the release artefacts on Amazon AWS. But in the API JSON > object the address points to github, so the http client has to follow a redirect to download the artefact.
> - Github uses https for its API and will redirect you to it if you are trying plain HTTP. This means that you would have to know the SSL fingerprints > of the github API server and the AWS hosting instance since this is required by the ESPs secure client interface. After all the ESPs don’t have a chain > of trusted certificates stored somewhere. While the fingerprint of the github API might be stable, the redirection on Amazon AWS might not always use > the same certificate.
>
> So what does the script do?
>
> It connects to the github API and fetches a JSON object describing the latest release. I’m currently only interested in the tag name and the firmware > download URL. The ESPs will send their firmware tag version with the update request and if the latest tag on Github and the one from the request are > identical nothing will happen. But if they are different the script will fetch the binary from github (with a hidden redirection to Amazon) and proxy > it to the ESP’s requesting it.

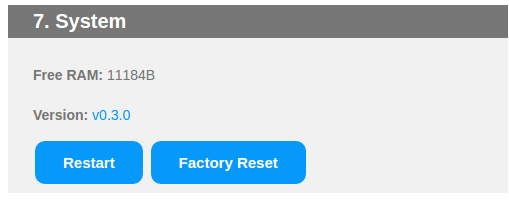
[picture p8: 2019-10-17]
Software/EmonESP/docs/system.png

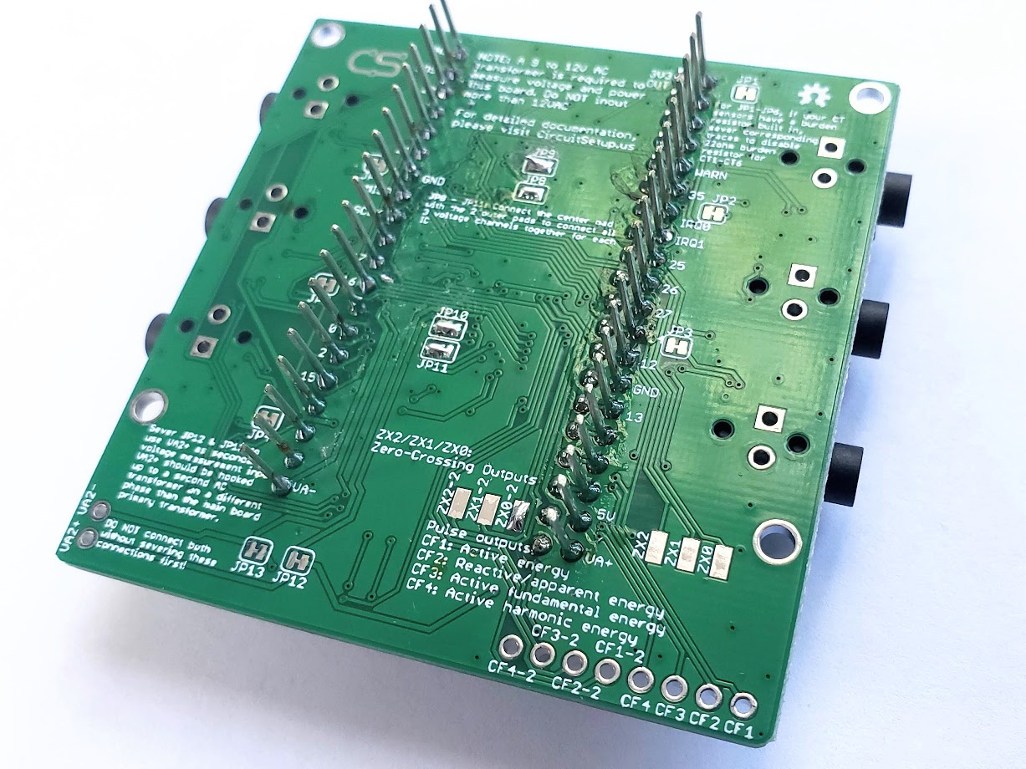
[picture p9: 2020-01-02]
Images/6-channel-add-on_v1.3_back.jpg

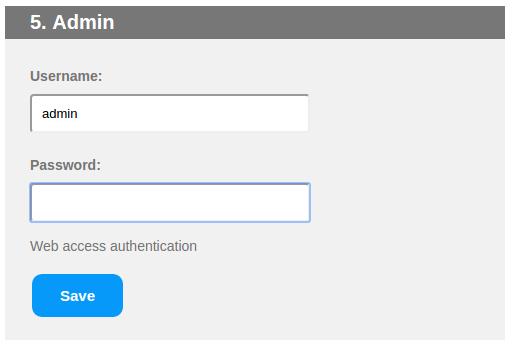
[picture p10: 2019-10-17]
Software/EmonESP/docs/admin.png

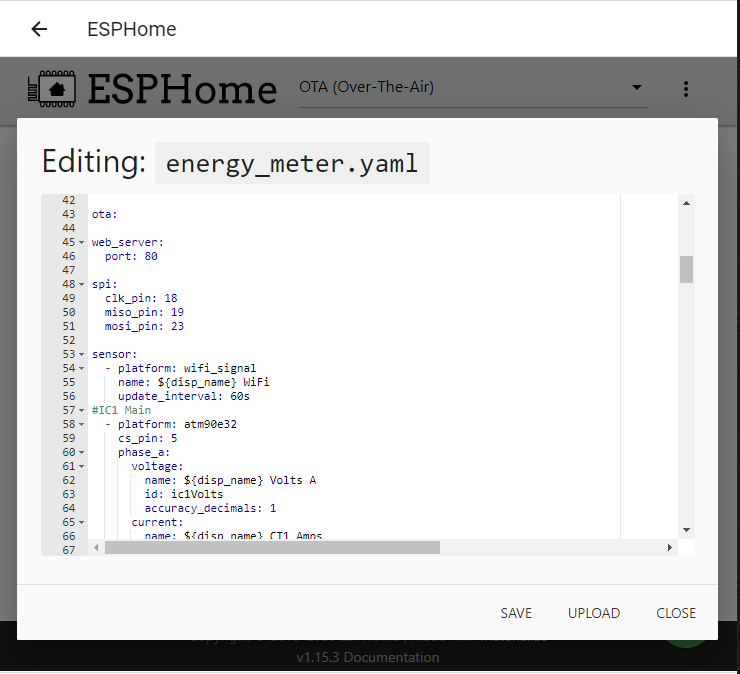
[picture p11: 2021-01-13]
Images/esphome_yaml_edit.PNG

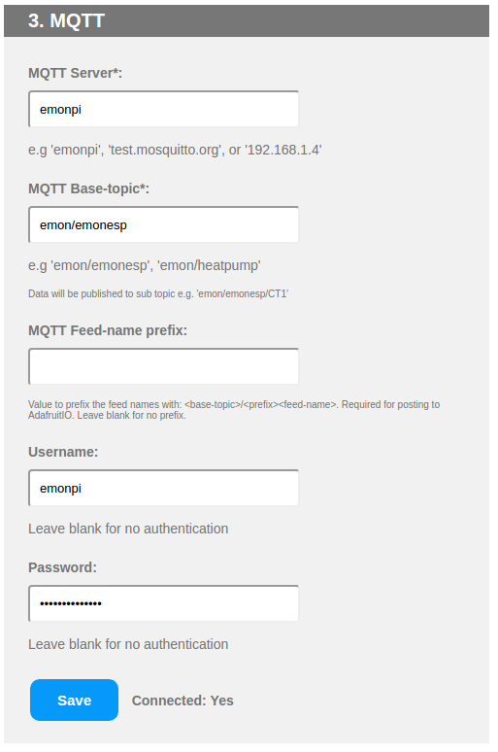
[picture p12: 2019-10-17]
Software/EmonESP/docs/mqtt.png

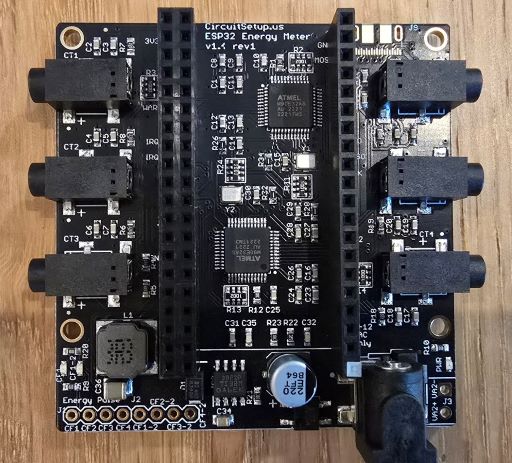
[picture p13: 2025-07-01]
Images/atm90e32-cs-6chan-full.jpg

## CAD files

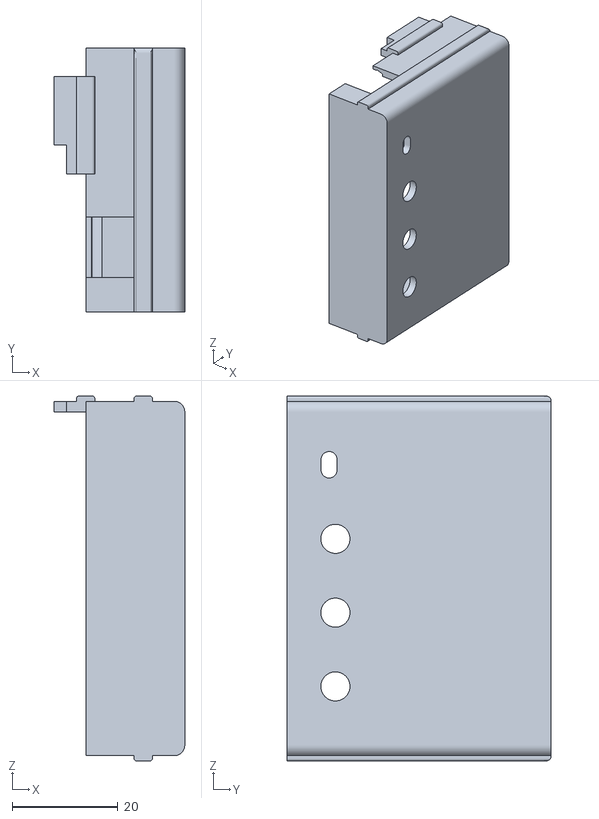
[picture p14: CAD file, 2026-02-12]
Hardware/Ethernet Adapter Cases/6channel_energy_meter_2piece_case_main_ethernet_ws_small_half.stl
24.7 x 50.0 x 69.0

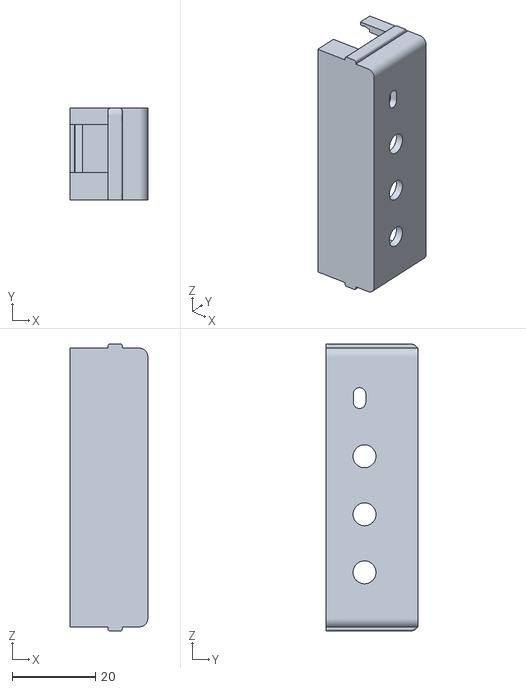
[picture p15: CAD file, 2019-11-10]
Hardware/6channel_energy_meter_2piece_case_main_board_small_half.stl
18.6 x 22.0 x 69.0

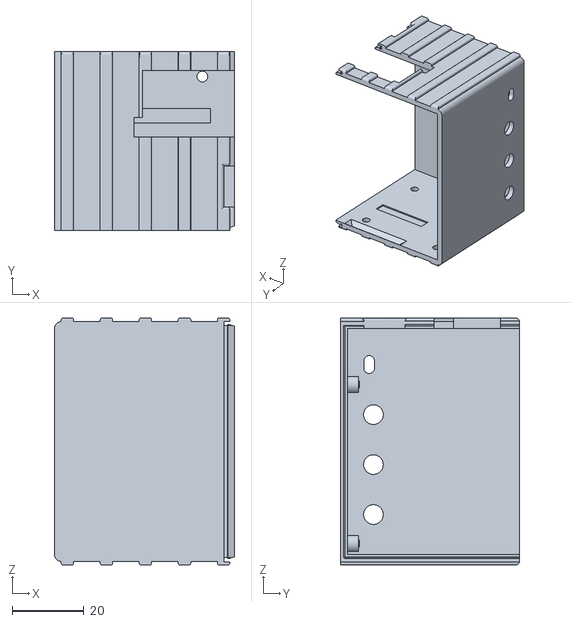
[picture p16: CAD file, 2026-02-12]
Hardware/Ethernet Adapter Cases/6channel_energy_meter_2piece_case_main_ethernet_ws_large_half.stl
50.3 x 50.0 x 69.0

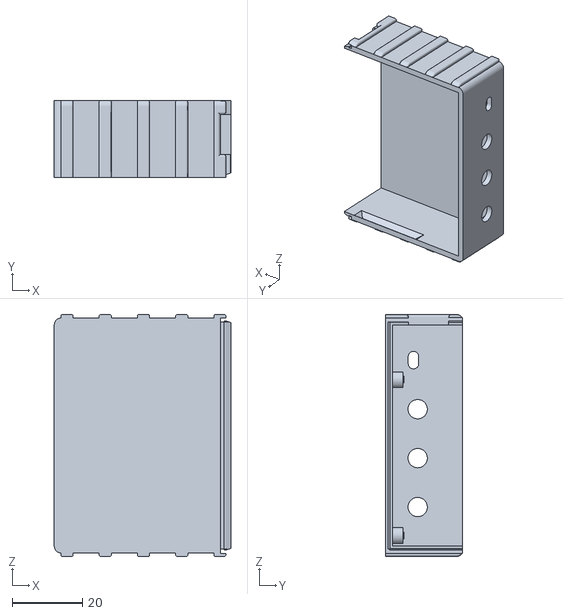
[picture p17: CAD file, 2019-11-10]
Hardware/6channel_energy_meter_2piece_case_main_board_large_half.stl
50.3 x 22.0 x 69.0

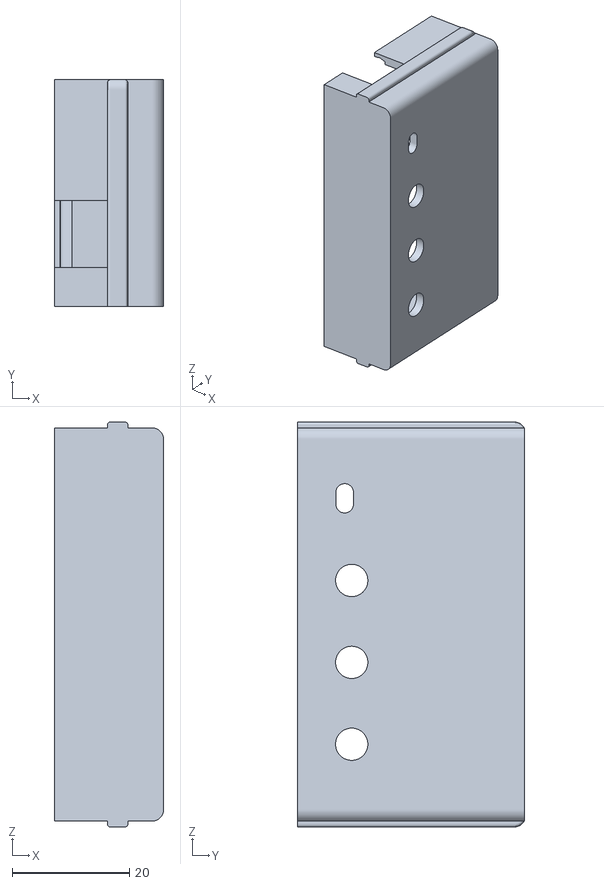
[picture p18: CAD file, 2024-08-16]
Hardware/Ethernet Adapter Cases/6channel_energy_meter_2piece_case_main_ethernet_small_half.stl
18.7 x 38.6 x 69.0

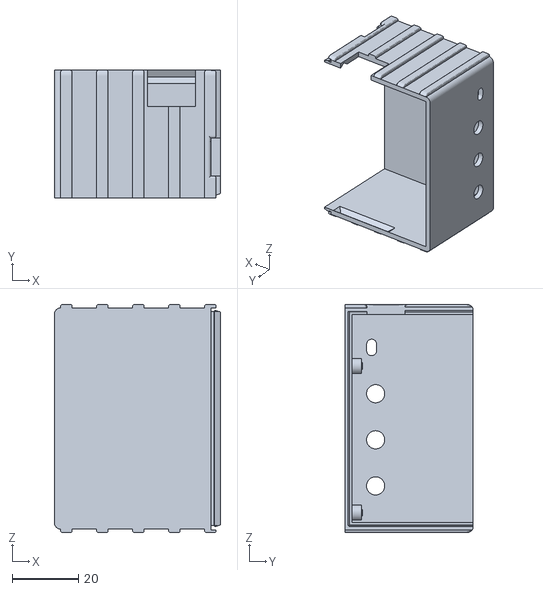
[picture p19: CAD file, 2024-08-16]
Hardware/Ethernet Adapter Cases/6channel_energy_meter_2piece_case_main_ethernet_large_half.stl
50.3 x 38.6 x 69.0

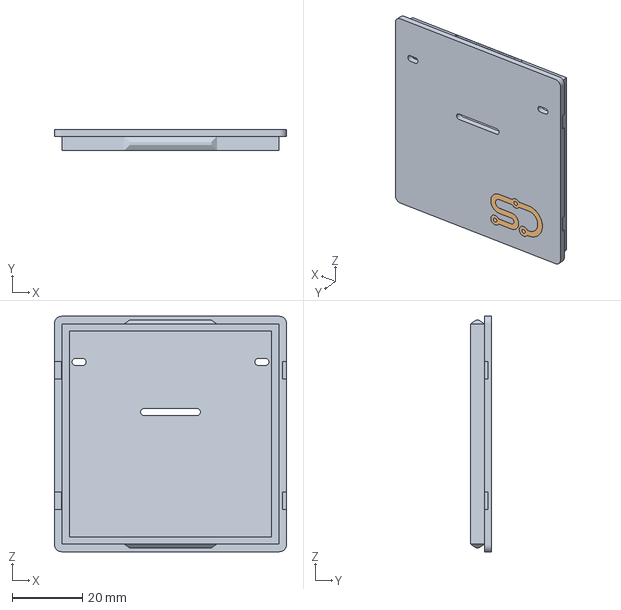
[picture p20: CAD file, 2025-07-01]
Hardware/Cover_solid_logo.3mf
66.0 x 6.00 x 67.0 mm

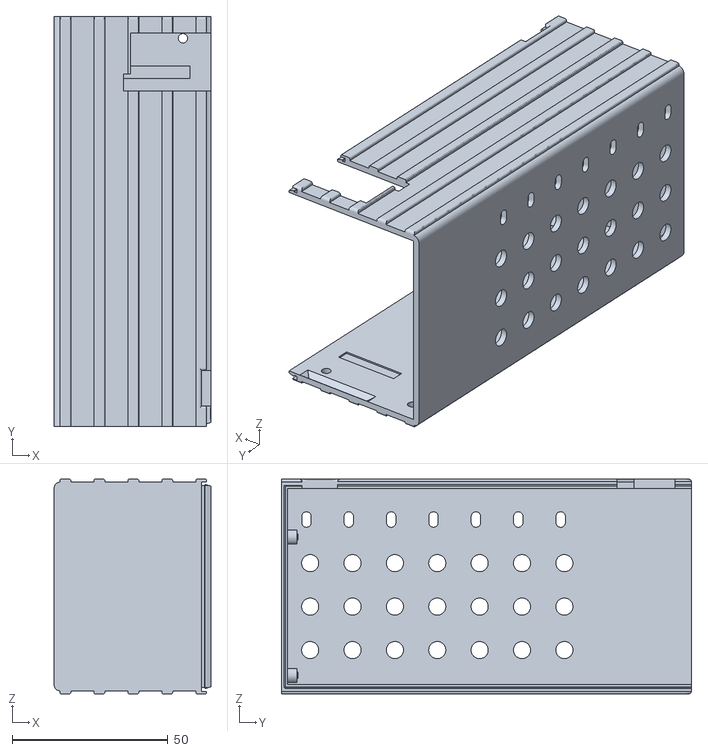
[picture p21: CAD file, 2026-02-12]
Hardware/Ethernet Adapter Cases/6channel_energy_meter_2piece_case_6-addon_ethernet_ws_large_half.stl
50.3 x 131.6 x 69.0

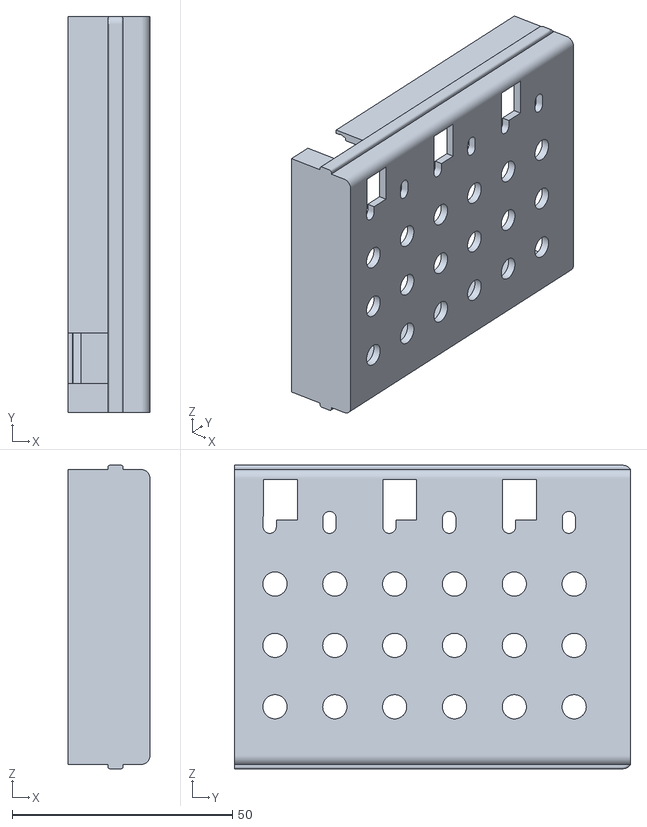
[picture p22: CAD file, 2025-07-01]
Hardware/6channel_energy_meter_2piece_case_5-addon_small_half_3-phase_voltage.stl
18.6 x 90.0 x 69.0

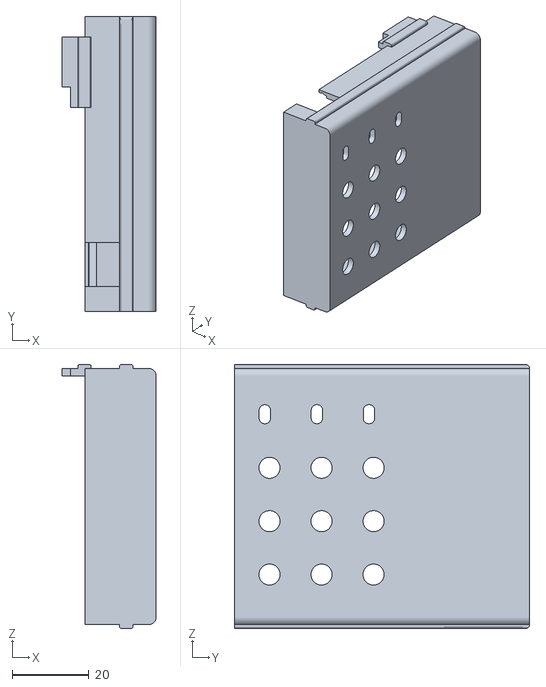
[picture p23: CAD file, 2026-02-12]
Hardware/Ethernet Adapter Cases/6channel_energy_meter_2piece_case_2-addon_ethernet_ws_small_half.stl
24.7 x 77.2 x 69.0

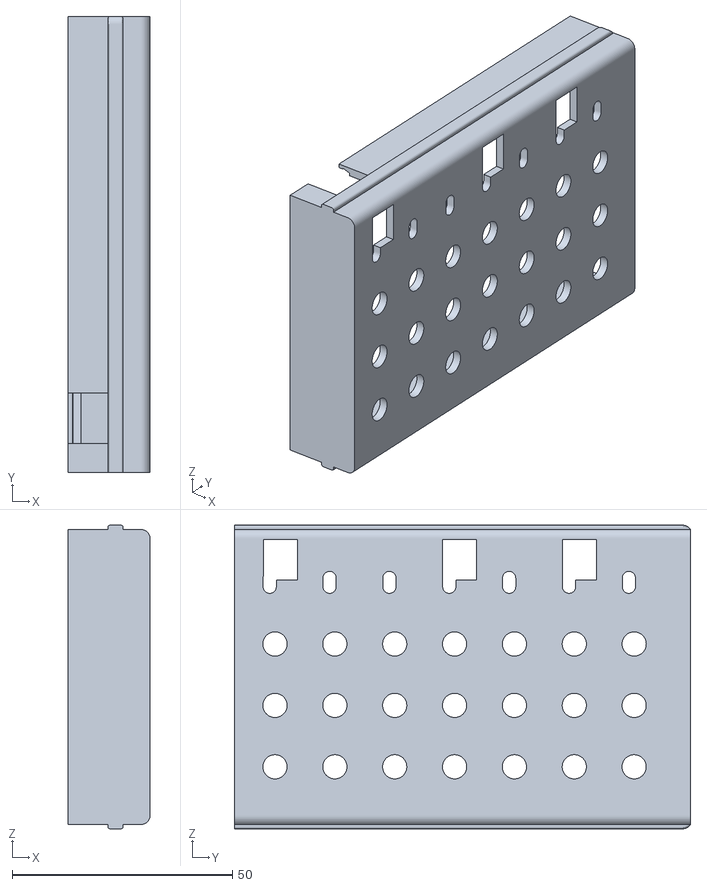
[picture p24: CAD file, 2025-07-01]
Hardware/6channel_energy_meter_2piece_case_6-addon_small_half_3-phase_voltage.stl
18.6 x 103.6 x 69.0

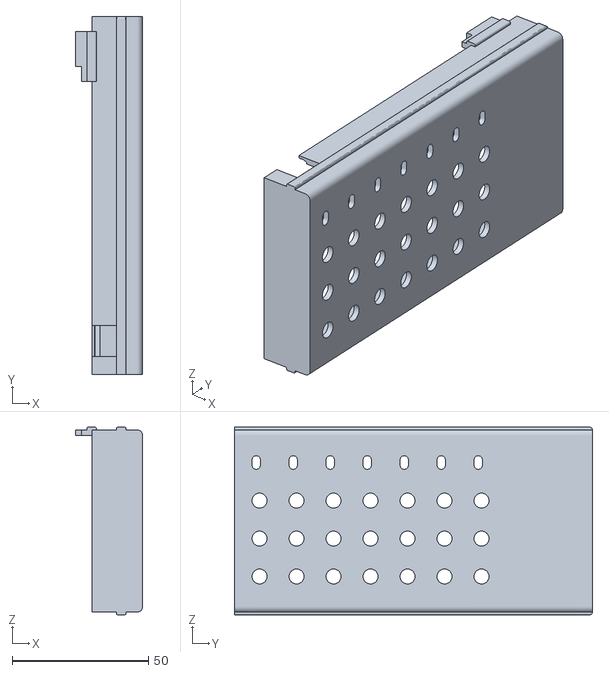
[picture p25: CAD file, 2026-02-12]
Hardware/Ethernet Adapter Cases/6channel_energy_meter_2piece_case_6-addon_ethernet_ws_small_half.stl
24.7 x 131.6 x 69.0

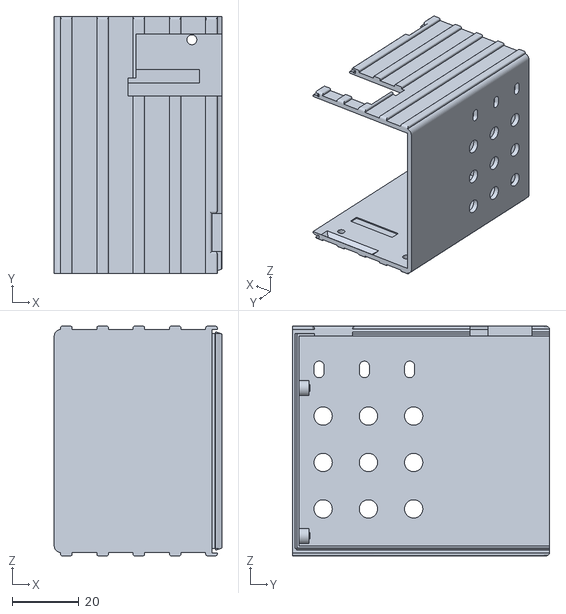
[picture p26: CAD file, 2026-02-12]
Hardware/Ethernet Adapter Cases/6channel_energy_meter_2piece_case_2-addon_ethernet_ws_large_half.stl
50.3 x 77.2 x 69.0

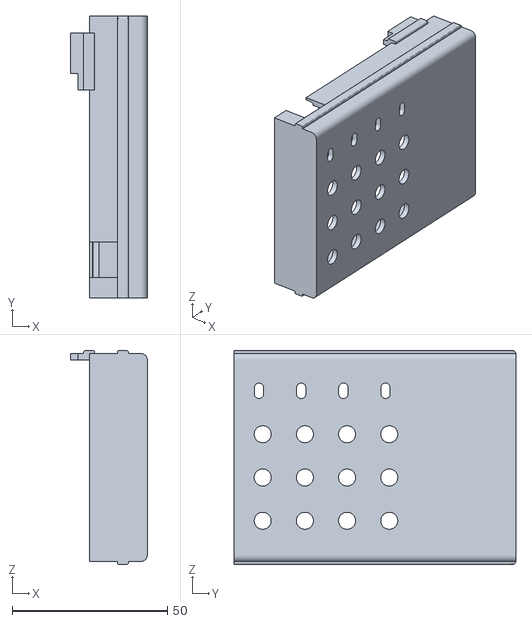
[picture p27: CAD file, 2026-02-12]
Hardware/Ethernet Adapter Cases/6channel_energy_meter_2piece_case_3-addon_ethernet_ws_small_half.stl
24.7 x 90.8 x 69.0

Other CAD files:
Hardware/6channel_energy_meter_2piece_case_4-addon_small_half.stl
Hardware/Ethernet Adapter Cases/6channel_energy_meter_2piece_case_4-addon_ethernet_ws_small_half.stl
Hardware/6channel_energy_meter_2piece_case_cover.stl
Hardware/Ethernet Adapter Cases/6channel_energy_meter_2piece_case_4-addon_ethernet_ws_large_half.stl
Hardware/6channel_case.stl
Hardware/6channel_case_lid.stl
Hardware/6channel_energy_meter_2piece_case_1-addon_small_half.stl
Hardware/6channel_energy_meter_2piece_case_2-addon_small_half.stl
Hardware/6channel_energy_meter_2piece_case_3-addon_small_half.stl
Hardware/6channel_energy_meter_2piece_case_5-addon_small_half.stl
Hardware/6channel_energy_meter_2piece_case_6-addon_small_half.stl
Hardware/6channel_energy_meter_2piece_case_6-addon_small_half_screw-connector.stl
Hardware/6channel_energy_meter_2piece_case_main_large_half_screw-connector.stl
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

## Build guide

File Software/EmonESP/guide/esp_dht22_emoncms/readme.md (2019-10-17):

# ESP DHT22 to Emoncms Example

An example made using the [Adafruit Huzzah](https://www.adafruit.com/product/2471) board with ESP-12 module and the DHT22 temperature humidity sensor.

This code example, when loaded onto the ESP will continuously upload temperature and humidity data onto [emoncms.org](https://emoncms.org)

[CP2102 USB to UART adapter](https://shop.openenergymonitor.com/programmers) was used as power supply and to program the ESP. 
PlatformIO or Arduino IDE can be used to compile and upload code. See [PlatformIO compile and upload guide](https://guide.openenergymonitor.org/technical/compiling)

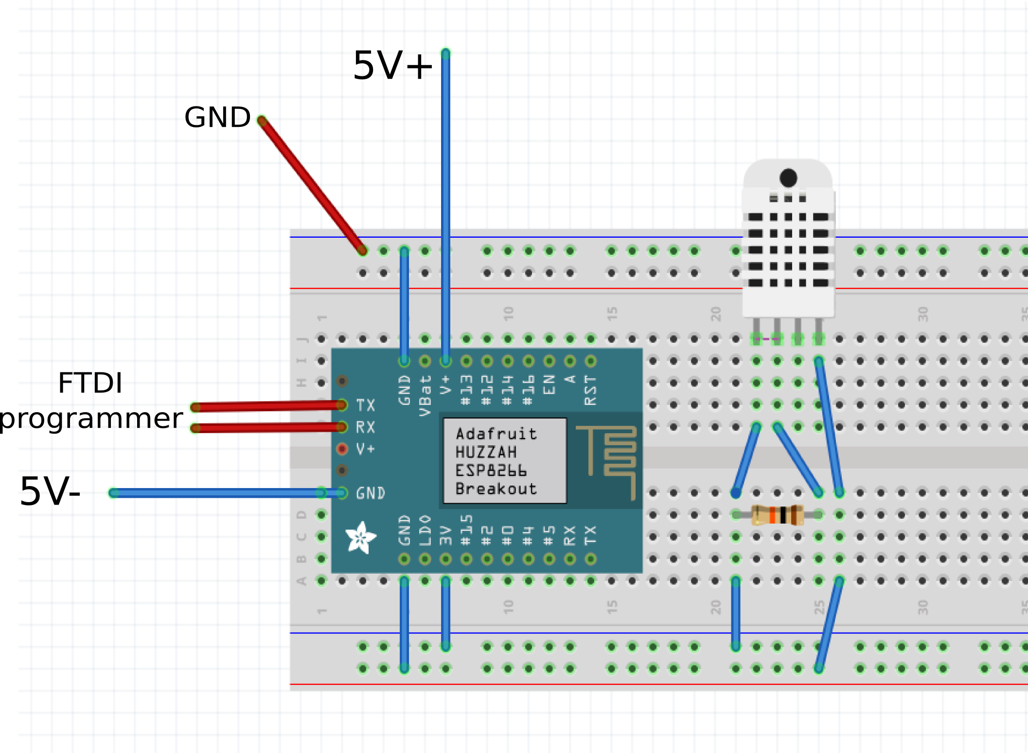
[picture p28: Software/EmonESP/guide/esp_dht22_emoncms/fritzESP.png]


Thanks to @myrddinmuse for puting together this example.

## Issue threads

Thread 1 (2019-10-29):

Missing a ;

TundraAP, 2019-10-29:
I just compiled the 6 channel and in the Energy_Meter.cpp, line 347 is missing a semicolon.  Line 347 should be like this:

totalCurrent += AddOn1_totalCurrent;

CircuitSetup, 2019-10-29:
Fixed, thanks!

Closed 2019-10-29.

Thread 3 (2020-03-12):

Can't calibrate - won't read 0 amps

BarrettLowe, 2020-03-12:
I'm either missing something in the documentation or something is going on with my board. After I get my calibration tuned in on a 60w light bulb, the amperage is wrong when turning the bulb off. With no current flowing, it reads about 0.2 amps. Turning the light on again yields (accurately) 0.44(ish) amps. Completely unplugging the CT clamp from the board yields 0.2 amps as well.

 I have v1.3 of the 6 channel hardware and haven't altered it in any way. Looks like JP8-11 are not connected. I'm using esphome like so:
```
- platform: atm90e32
    cs_pin: 5
    phase_a:
      voltage:
        name: "Volts A"
        id: "ic1Volts"
        accuracy_decimals: 1
      current:
        name: "CT1 Amps"
        id: "ct1Amps"
        accuracy_decimals: 3
# Voltage using a 12VAC power transformer
      gain_voltage: 7063
# Current calibration using a 100A/50ma SCT-013-000
      gain_ct: 18874
    phase_b:
      current:
        name: "CT2 Amps"
        id: "ct2Amps"
# If the wattage is backwards due to the phase 180 degrees from the clamp direction
#        filters:
#          - multiply: -1.0
      gain_ct: 18874
    frequency:
      name: "Freq"
    line_frequency: 60Hz
    gain_pga: 1X
    update_interval: ${update_time}
```

Any idea what I'm doing wrong here?

CircuitSetup, 2020-03-12:
One thing I see wrong is that phase_b needs a "gain_voltage: 7063", like with phase_a. But that shouldn't affect the current reading, only the power calculation.

Can you confirm the same thing happens on other current channels or is it just one? If only one check the solder joints for that connector and surrounding caps/resistors. It's possible there is a cold joint. I usually only see this when the gain is turned up.

BarrettLowe, 2020-03-13:
Looks like 1 of the power monitoring ICs is working fine. CT1-3 all have this issue while 4-6 do not. Didn't see any cold joints but I ran around both ICs just cleaning things up and putting a little pressure down. Seems to have fixed it for now!

Closed 2020-03-13.

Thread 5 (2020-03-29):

Feature requests: EmonESP

presslab-us, 2020-03-29:
Not sure the best place to document this so I put it here.

I'd like to request a few features for the EmonESP software.  I have been using the ESPHome software because I require the configuration options but I have these issues:
* I am quickly running into stack overflow issues and I already need to limit the number of things I report.
* I don't like the necessity of recompiling for every change.
* It's very cumbersome handling the data in Home Assistant.  With Emoncms it is easier to manage this kind of data.

Mainly I would like more flexibility in the configuration of EmonESP:
* Allow for setting the calibration constant individually for each input on each add-on board
* Allow for configuring an arbitrary multiplier for each current and power report
* Allow for easily setting the ADC PGA for each input (split the bits of the register for ease of use)
* Report power and power factor (in addition to current) for each input

Thanks for reading!

presslab-us, 2020-04-06:
I have implemented these features here:
https://github.com/presslab-us/Expandable-6-Channel-ESP32-Energy-Meter/tree/config

CircuitSetup, 2020-04-06:
@presslab-us thanks so much for doing this. If you want, you can put together a pull request so I can merge the changes/features.

presslab-us, 2020-04-06:
Thanks.  Yes I can do a pull request once I get some time on it.
I have this new code installed on two units.  One of them has been working fine and the other crashes after some time.  I'd like to figure out this issue first.

CircuitSetup, 2020-04-07:
Humm, is the esp32 different between the 2 or is one using MQTT where the other is not? You may want to monitor the available memory as well.

presslab-us, 2020-04-07:
They both connect to Emoncms and MQTT.  The one that is failing has 3 add-on boards, the working one only has the main board.  The free memory is pretty much the same on both and does not look to decrease over time.

I think I saw this same problem with ESPHome as sometimes the values would not update for a bit.  Perhaps the difference with EmonESP is that it does not enable the watchdog timer.  ESPHome would just mask the problem by rebooting.  I'm not sure the validity of that theory yet.

presslab-us, 2020-04-07:
Before going to bed I plugged in a USB power adapter (in combination with the AC wall transformer).  It was still working this morning.  I then unplugged the USB power adapter and it crashed within 20 minutes.

I will keep looking at it to see what I can figure out.

CircuitSetup, 2020-04-07:
To rule out some things, are you using the latest versions of the async libraries to compile? There was a bug that was recently fixed that would cause connections to not be properly closed. This would happen after visiting the web interface or if it was left open.

Also, do you have the latest esp32-arduino?

CircuitSetup, 2020-04-07:
Also, thanks so much for refactoring all of the redundant code! My approach that lacked arrays was a bit rushed.

presslab-us, 2020-04-07:
My AsyncTCP library is version 1.1.1, the latest from GitHub.
My esp32-arduino is version 1.0.4, it looks like that is the latest released version.  It came from here: https://dl.espressif.com/dl/package_esp32_index.json

I have made a few changes to the power supply.  I am going to run it overnight to see how it goes.

presslab-us, 2020-04-08:
It didn't lock up last night, so that is good.  But the `psent` value is resetting to zero, I assume that's because the unit has reset.  If you can think of anything in the software that would reset the unit (or reset `psent`) let me know.
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

CircuitSetup, 2020-04-08:
Humm, that line will only execute if it fails to send data to emoncms >30 times while connected to wifi. Maybe it is connected to wifi, but is being blocked, or for some reason emoncms is becoming unavailable to the esp32. Is there any reason that would happen? Firewall?

presslab-us, 2020-04-08:
With that line disabled it's not rebooted (or locked up) once so far, but we'll see.  It's currently at `Successful messages: 13543/13584 99.69817432273263%`.  I don't know if all the lost ones happened at once or what.  There is no firewall between the units and the server.

Honestly I don't mind so much if that causes a reboot.  I just want to be sure the locking up is fixed, and that the reboots aren't related to the locking up problem, or a software bug.

I believe the locking up problem was caused by insufficient capacitance on the supply input.  Would you like me to create a separate issue for that?

CircuitSetup, 2020-04-08:
I'll have to take a closer look at that line, and why it may be executing.

Can you take note whether you visited the web interface or not after a reboot, and if that correlates to it locking up again or not.

Also, there may be something I haven't discovered yet with the async libraries and the MQTT library. Previously there was a bug where it would block everything for 14 min if it lost a connection to MQTT. That was fixed, but it could still block wifi functionality for 5 seconds at a time if MQTT is lost. It should really be changed to an async MQTT library to prevent this.

Yes, put anything you found with capacitance in a new issue, since that's hardware related.

presslab-us, 2020-04-08:
In my plot above when the unit reset `psent` went to zero.  You can see it had rebooted a couple times during the night and I did not access the web page between reboots (I was sleeping).

I have not seen any lock ups since modifying the power supply, only reboots now.

It sounds like reboots might have been a problem before my modifications?  Do you think what I am seeing may not be related to the changes I have made?  If so maybe another issue should be created for the reboots.

presslab-us, 2020-04-12:
I have captured a serial log when the reboot happened.  Looks like it is crashing in `get_http()`.  I've put in additional logging to try and narrow it down.
```
.
Plain old HTTP
Guru Meditation Error: Core  1 panic'ed (InstrFetchProhibited). Exception was unhandled.
Core 1 register dump:
PC      : 0xc000610e  PS      : 0x00060d30  A0      : 0x800e6e3a  A1      : 0x3ffb1dd0
A2      : 0x3ffc1c48  A3      : 0xc000610e  A4      : 0x000004c0  A5      : 0x0e6350da
A6      : 0x07fd6bdc  A7      : 0x07fd6bdc  A8      : 0x8018617a  A9      : 0x3ffd9f2b
A10     : 0x3ffd7d9c  A11     : 0x0e6350da  A12     : 0x3ffc2758  A13     : 0x0e6350da
A14     : 0x3ffb88d0  A15     : 0x3ffb88d0  SAR     : 0x00000008  EXCCAUSE: 0x00000014
EXCVADDR: 0xc000610c  LBEG    : 0x4000c46c  LEND    : 0x4000c477  LCOUNT  : 0x00000000

Backtrace: 0x4000610e:0x3ffb1dd0 0x400e6e37:0x3ffb1df0 0x400e6ea9:0x3ffb1e10 0x400e7ff1:0x3ffb1e30 0x400d4141:0x3ffb1e70 0x400d34a5:0x3ffb1ed0 0x400d4b86:0x3ffb1f60 0x400ea895:0x3ffb1fb0 0x40088$

Rebooting...
ets Jun  8 2016 00:22:57

rst:0xc (SW_CPU_RESET),boot:0x17 (SPI_FAST_FLASH_BOOT)
```

CircuitSetup, 2020-04-12:
Humm, I'm not sure what would be causing a panic related to http_get. Definitely let me know what you find.

Previously I had assumed that the memory leaks were causing all the issues, but they may have only been a part of it.

presslab-us, 2020-04-12:
I'm getting closer as I narrow it down.  Right now I suspect it is an issue of memory fragmentation with the use of `String`.
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
CircuitSetup, 2020-04-17:
Thanks for the update! That's interesting! I didn't realize that use of HTTPClient was deprecated.  Any idea why that would cause a crash here but not in the meter with less current channels? Maybe because of the amount of data being transferred?

presslab-us, 2020-04-17:
The way that `begin()` was being called was deprecated, and this seemed to contribute to the crash.  The code in the backtrace would only be reached if there was some conflict running in the deprecated mode.  Not all of `HTTPClient` was deprecated, I could have just used the new `begin()` call (which actually uses `WifiClient`).  But to keep the code common with the HTTPS code I just switched everything to `WiFiClient`.

I don't know what the exact problem with deprecated `HTTPClient` is, but it was always crashing in that same place.  I suspect if I let the 6 channel meter run for longer it too would eventually crash.

The 24 channel meter is still working (with the updated code), over 22 hours so far.
`Successful messages: 79867/79868 99.99874793409124%`

presslab-us, 2020-04-27:
There have been no crashes at all using `WiFiClient` instead of `HTTPClient`.

I've been working on the task watchdog timer.  Since I have enabled it, I have found numerous places where the default timeouts violate the 5 second watchdog.  This 5 second timeout is in the IDF sdkconfig, so it's pretty hard to change especially when using the Arduino toolchain.

It's obvious that most of the Arduino libraries are not designed to work with a watchdog.  But I feel a watchdog is really a necessity with any embedded product, and also if the watchdog were enabled I feel the unit would not have locked up with the power glitch.  Not that a watchdog is a proper solution, but rebooting is better than locking up.

CircuitSetup, 2020-04-27:
That's great! Thanks so much for testing and figuring this out. I never would have seen that wificlient should have been used there.

What have you found that is triggering the watchdog? It definitely makes sense to use, but I also want to prevent it from getting triggered when something else can be changed or fall back to another state.

If you feel like this is stable enough, create a PR and I'll merge it in.

CircuitSetup, 2020-04-27:
Nevermind, I see you made some changes to the http timeout and MQTT timeout/error handling.

Btw, I was looking into changing the MQTT library to something that supports async. Otherwise if it cant connect to MQTT, everything else is blocked while it tries to reconnect.

presslab-us, 2020-04-27:
It seems stable so far, I was thinking to let it run for a week to see how it goes.

There are still some watchdog "boobytraps", like in WiFiClient (which is used by both the HTTP get and MQTT) it has a transmit timeout of 10 seconds.  So that will trip the watchdog if it happens to connect but later cannot transmit.  This timeout can be changed by editing `WiFiClient.cpp` but that's hacky, there really should be a method to configure this.  But for the time being I guess a reboot due to a timeout is better than a potential lock up.

Async MQTT would be good.  I've been playing around with another branch that encodes the MQTT as JSON for sending to Telegraf, InfluxDB, and Grafana.  It might make more sense to send directly to InfluxDB, not sure.

CircuitSetup, 2020-04-30:
Thanks for explaining - that makes sense. It's strange that there isn't a function to change the watchdog timeout.

The method for sending to InfluxDB and others probably depends more on how the user has things set up. I've seen a couple users modify the existing or write their own code to send directly to mySQL too. It may actually be better as a separate option from MQTT in the config.

presslab-us, 2020-05-01:
I tried changing the timeout to no avail.  I read about, and can see, the hard coded timeout in the `sdkconfig` file.  My guess is that it's hard coded so some runaway code can't accidentally change it while running.

I needed to do some preprocessing of the sensors (summing phases) before sending to InfluxDB.  While I did get math operations to work in InfluxDB, it slowed it to a crawl.  I have a small Python script that does this instead, so MQTT is actually better for that.

That's one area Iotawatt does pretty well.

CircuitSetup, 2020-05-06:
This was all merged in PR #10 Thanks for contributing - awesome work!

Closed 2020-05-06.

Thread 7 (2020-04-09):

Power supply glitch

presslab-us, 2020-04-09:
I have two energy meters, one with no add-on boards and one with 3 add-on boards.  On the unit with 3 add-on boards the unit has been locking up and would require a power cycle to work again.  The other unit has not locked up.  I suspected the difference was the current draw from one vs the other.

In diagnosing this issue I have been looking at the power supplies as a source of the problem.  I have captured the signals with my scope as shown below.  Yellow is the 3.3V at C36 (AC coupled).  Red is the rectified incoming voltage at C33.  Blue is the un-rectified voltage at J4.  The lower yellow trace is a zoom of the glitch event.

It can be seen that the 3.3V supply has a glitch due to the voltage at C33 dropping too far.  This seems to happen during a period of high current draw (likely WiFi transmission).  The incoming voltage in blue seems fine so I don't believe it is a line voltage problem.

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

I have added an additional 100uF to C33 and I have not observed a lock up after that.  To be clear the captured waveforms are with an unmodified unit.

I know board space is limited but I'm actually not even sure an additional 100uF is sufficient.  The industry accepted standard for hold up time is one cycle, or 16.7 ms at 60 Hz (even worse at 50 Hz).  If the input power lost a cycle (e.g. switching to battery backup) while the WiFi were transmitting, I would guess 200uF is not sufficient for this scenario.  In addition, it is possible to add 3 more add-on boards, further increasing the current draw and the need for more capacitance.

I hope my comments do not come across as overly critical.  Thanks for your time!

CircuitSetup, 2020-04-09:
Thanks so much for detailing this. I had observed a dip in my own testing, but it wasnt causing a problem. I may have overlooked testing with as many add-ons as you have while transmitting data over wifi.

Have you tried putting the cap in parallel with C36? It may be more efficient this way (and you wouldnt need a higher voltage cap like C33).

presslab-us, 2020-04-09:
I have not tried that, but in terms of energy content I think it would be a wash.  The higher voltage cap would have less capacitance but it would be offset by the lower current drawn from it because of the buck converter.  The disadvantage of putting more capacitance in parallel with C36 is that the 3.3V supply would still fall out of regulation, whereas with C33 the 3.3V would remain stable.

CircuitSetup, 2020-04-09:
Right, that makes sense. I'll have to do some more testing of this.

Just thinking about it a bit - it would be a lot easier to add an additional cap on the 3.3v line on each add-on board. This way total capacitance would increase as more add-ons/load is added.

I'll also test using a 220uf or 300uf cap in place of the 100uf c33. 2 seperate caps may perform better as you have it though.

CircuitSetup, 2020-04-30:
Is this still causing your esp32 to reset, or was that resolved with the other code changes?

presslab-us, 2020-05-01:
This problem was causing a lock up and not a reset.  I have not seen one lock up since adding additional capacitance.  Before, it would usually lock up after only a few hours.

CircuitSetup, 2020-05-04:
Sorry, I meant to say lock up. Did you happen to capture the interval at which the glitch was happening? I'm trying to figure out if this was the wifi transmitting (or maybe even SPI communicating), and if the brownout detector was triggered or not. I can't seem to reproduce the same conditions.

I've previously observed that the esp32 will eat more power in AP mode (if it doesn't connect to the main AP after so many tries, it'll go into AP mode), which is another factor in power consumption.

presslab-us, 2020-05-04:
The interval wasn't necessarily consistent.  I think it happened when a few things lined up.  I could see my scope trigger (at the minimum) maybe every 30 minutes or so.

Looking at the voltage noise on the 3.3V supply and the rate that the bus capacitor is falling, it looks like this occurs during high current demand.  The thing I can think of that draws the highest current is the WiFi transmitter.

Maybe you have a bit higher line voltage, or lower transformer ratio?

CircuitSetup, 2020-09-03:
FYI, I believe this issue is solved with the addition of a 100uf cap on the 3.3V line going into the add-on boards.

Closed 2020-09-03.

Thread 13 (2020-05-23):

Case mounting tabs and CT numbers

presslab-us, 2020-05-23:
I wanted to use the Orbit 57095 Timer Cabinet to house the energy meter: https://www.orbitonline.com/product/gray-outdoor-timer-cabinet/

The provided 3D printed case didn't really have mounting like I wanted it, so I have modified the STL files to add mounting tabs that line up with existing holes in that cabinet.  This cabinet will fit up to the 24-input (3 addon board) energy meter.

The second change was adding numbers to the sides of the case so it can be quickly seen what the CT input number is.

Ideally these changes would be in the source CAD file, and not just the STLs, so if this improvement is desired that would be the proper place to make these changes.  I didn't see the CAD files available on GitHub.

Here's the OpenSCAD remix and STLs for a 6-input and 24-input version: [case_mod.zip](https://github.com/CircuitSetup/Expandable-6-Channel-ESP32-Energy-Meter/files/4672481/case_mod.zip)

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

CircuitSetup, 2020-05-27:
Thanks for sharing your case! I'll have the tabs in the master. Also, very clean install!

Closed 2021-03-22.

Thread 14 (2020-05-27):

How to properly connect current transformers to each input

manutenfruits, 2020-05-27:
Hi, I want to use the 6 channel meter to measure the following:

 - Input of the house, split phase (2x clamps)
 - Washer/Dryer breaker, split phase (2x clamps)
 - breaker #3 (1 clamp)
 - breaker #4 (1 clamp)

I started by connecting it as follows:

- Chip 1:
    - Phase A: whole house phase 1
    - Phase B: whole house phase 2 (inverted clamp).
    - Phase C: breaker #3
- Chip 2:
    - Phase A: washer/dryer phase 1
    - Phase B: washer/dryer phase 2 (inverted clamp).
    - Phase C: breaker #4

I get proper readings for the whole house and for the washer/dryer, but I get 0A for the two separate breakers. I want to understand what I'm doing wrong before I open the electric panel again.

Is the third measurement on each chip supposed to be in the same phase as the other two? I took it off the panel and tried each input separately with a resistive load and it reads correctly on every port/input, and power is always a positive number.

CircuitSetup, 2020-05-27:
What software are you using? If ESPHome, can you post your config?

manutenfruits, 2020-05-27:
For more context, I ended up opening the panel again and reversed those CT clamps that read negative, even if it didn't make much sense to me. I started pointing the arrow towards the load on those clamps that were on the same phase, and reversed in those that were on the other phase, but I think I had to make some adjustments. When I was done, I was getting readings on the last two breakers (both on phase C of their respective chips), but after less than an hour they went to zero (and I had already closed the panel).

Here's the relevant part of the config:
```

spi:
  clk_pin: 18
  miso_pin: 19
  mosi_pin: 23
sensor:
  - platform: atm90e32
    cs_pin: 5
    phase_a: # Black Input
      voltage:
        name: "Voltage A"
        id: voltage_a
      current:
        name: "Current A"
        id: current_a
      power:
        name: "Active Power A"
        id: active_power_phase_a
      reactive_power:
        name: "Reactive Power A"
      power_factor:
        name: "Power Factor A"
      gain_voltage: 7314
      gain_ct: 21111
    phase_b: # Washer/Dryer black
      voltage:
        name: "Voltage Washer/Dryer A"
      current:
        name: "Current Washer/Dryer A"
        id: active_power_washer_a
      power:
        name: "Active Power Washer/Dryer A"
      gain_voltage: 7362
    phase_c: # NID
      voltage:
        name: "Voltage NID"
      current:
        name: "Current NID"
      power:
        name: "Active Power NID"
      gain_voltage: 7314
      gain_ct: 21111
    frequency:
      name: "Line 1 Frequency"
    line_frequency: 60Hz
    gain_pga: 2X
    chip_temperature:
      name: "Temperature"
    update_interval: 5s
  - platform: atm90e32
    cs_pin: 4
    phase_a: # Red Input
      voltage:
        name: "Voltage B"
        id: voltage_b
      current:
        name: "Current B"
        id: current_b
      power:
        name: "Active Power B"
        id: active_power_phase_b
      reactive_power:
        name: "Reactive Power B"
      power_factor:
        name: "Power Factor B"
      gain_voltage: 7314
      gain_ct: 21111
    phase_b: # Washer/Dryer red
      voltage:
        name: "Voltage Washer/Dryer B"
      current:
        name: "Current Washer/Dryer B"
        id: active_power_washer_b
      power:
        name: "Active Power Washer/Dryer B"
      gain_voltage: 7362
    phase_c: # Aux/Kitchen GFCI
      voltage:
        name: "Voltage Kitchen GFCI"
      current:
        name: "Current Kitchen GFCI"
      power:
        name: "Active Power Kitchen GFCI"
      gain_voltage: 7362
    frequency:
      name: "Line 2 Frequency"
    line_frequency: 60Hz
    gain_pga: 2X
    update_interval: 5s
```

CircuitSetup, 2020-05-27:
Your config looks okay (btw, you probably only need one voltage reported - otherwise you're just reporting the same number over and over, and using up ESP32 memory)

It sounds like the physical connection isn't being made very well with the CTs on 3 and 4 (phase c IC1, and phase a IC2). Can you take a close look at the 2 pins on the 3.5mm jacks on the same side as the "+" symbol on the pcb? The opposite pins are not used, other than to hold the jacks on the board. They may be a cold solder joints that I missed in QA.

manutenfruits, 2020-05-28:
I did a pass on the 3.5mm joints when I first got the board because one of them almost came off when I put the jack in, and I checked again and they seem fine. I think it must be something making a weak contact somewhere else, I swapped the phase c jacks for testing and seemed to work so I left it that way.

Closed 2020-05-28.

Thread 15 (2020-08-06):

[power_factor] is an invalid option for [phase_b]. Please check the indentation

elyorkhakimov, 2020-08-06:
I have ran into indentation issue and can't seem to resolve it.
Here is a portion of YAML file I'm trying to run:

```
root@tuyaconvert:/home/user# cat 6chan_energy_meter-add-on_jp8-jp11.yaml
# Example config for when jp8-jp11 are all bridged - this connects all the voltage channels and allows for power to be calculated by the meter directly.
# Boards >= v1.4 jp8-jp11 are removed and have all voltage channels connected
# 1 add-on board

substitutions:
# Change the disp_name to something you want
  disp_name: cs_nrg_mtr
# Interval of how often the power is updated
  update_time: 10s
# Current Transformers:
#  20A/25mA SCT-006: 11143
#  30A/1V SCT-013-030: 8650
#  50A/1V SCT-013-050: 15420
#  80A/26.6mA SCT-010: 41660
#  100A/50ma SCT-013-000: 27518
#  120A/40mA: SCT-016: 41787
#  200A/100mA SCT-024: 27518
  current_cal: '27518'
# Jameco 9VAC Transformer:
#  For meter versions:
#  >= v1.3: 7305
#  <= v1.2: 42620
  voltage_cal: '7305'

esphome:
  name: cs_nrg_mtr
  platform: ESP32
  board: nodemcu-32s

wifi:
  ssid: XXX
  password: XXX
  manual_ip:
    static_ip: 192.168.17.110
    gateway: 192.168.17.1
    subnet: 255.255.255.0
    dns1: 192.168.17.1

mqtt:
  broker: XXX
  username: XXX
  password: XXX

# Enable logging
logger:
  level: INFO
# Enable Home Assistant API
#api:

ota:

web_server:
  port: 80

spi:
  clk_pin: 18
  miso_pin: 19
  mosi_pin: 23

sensor:
  - platform: wifi_signal
    name: ${disp_name} WiFi
    update_interval: 60s
#IC1 Main
  - platform: atm90e32
    cs_pin: 5
    phase_a:
      voltage:
        name: ${disp_name} Volts A
        id: ic1Volts
        accuracy_decimals: 2
      current:
        name: ${disp_name} CT1 Amps
        id: ct1Amps
# The max value for current that the meter can output is 65.535. If you expect to measure current over 65A,
# divide the gain_ct by 2 (120A CT) or 4 (200A CT) and multiply the current and power values by 2 or 4 by uncommenting the filter below
#        filters:
#          - multiply: 2
      power:
        name: ${disp_name} CT1 Watts
        id: ct1Watts
#        filters:
#          - multiply: 2
      gain_voltage: ${voltage_cal}
      gain_ct: ${current_cal}
    phase_b:
      current:
        name: ${disp_name} CT2 Amps
        id: ct2Amps
      power_factor:
        name: somename
      power:
        name: ${disp_name} CT2 Watts
        id: ct2Watts
      gain_voltage: ${voltage_cal}
      gain_ct: ${current_cal}
    phase_c:
      current:
        name: ${disp_name} CT3 Amps
        id: ct3Amps
      power:
        name: ${disp_name} CT3 Watts
        id: ct3Watts
      gain_voltage: ${voltage_cal}
      gain_ct: ${current_cal}
    frequency:
      name: ${disp_name} Freq A
    line_frequency: 60Hz
    gain_pga: 1X
    update_interval: ${update_time}
#IC2 Main
  - platform: atm90e32
    cs_pin: 4
    phase_a:
      voltage:
        name: ${disp_name} Volts B
        id: ic2Volts
        accuracy_decimals: 2
      current:
        name: ${disp_name} CT4 Amps
        id: ct4Amps
      power:
        name: ${disp_name} CT4 Watts
        id: ct4Watts
      gain_voltage: ${voltage_cal}
      gain_ct: ${current_cal}
    phase_b:
      current:
        name: ${disp_name} CT5 Amps
        id: ct5Amps
      power:
        name: ${disp_name} CT5 Watts
        id: ct5Watts
      gain_voltage: ${voltage_cal}
      gain_ct: ${current_cal}
    phase_c:
      current:
        name: ${disp_name} CT6 Amps
        id: ct6Amps
      power:
        name: ${disp_name} CT6 Watts
        id: ct6Watts
      gain_voltage: ${voltage_cal}
      gain_ct: ${current_cal}
    line_frequency: 60Hz
    gain_pga: 1X
    update_interval: ${update_time}

#Total Amps Main
  - platform: template
    name: ${disp_name} Total Amps Main
    id: totalAmpsMain
    lambda: return id(ct1Amps).state + id(ct2Amps).state + id(ct3Amps).state + id(ct4Amps).state + id(ct5Amps).state + id(ct6Amps).state ;
    accuracy_decimals: 2
    unit_of_measurement: A
#    icon: "mdi:flash"
    update_interval: ${update_time}
#Total Amps
  - platform: template
    name: ${disp_name} Total Amps
    id: totalAmps
    lambda: return id(totalAmpsMain).state;
    accuracy_decimals: 2
    unit_of_measurement: A
#    icon: "mdi:flash"
    update_interval: ${update_time}

#Total Watts Main
  - platform: template
    name: ${disp_name} Total Watts Main
    id: totalWattsMain
    lambda: return id(ct1Watts).state + id(ct2Watts).state + id(ct3Watts).state + id(ct4Watts).state + id(ct5Watts).state + id(ct6Watts).state ;
    accuracy_decimals: 1
    unit_of_measurement: W
#    icon: "mdi:flash-circle"
    update_interval: ${update_time}

switch:
  - platform: restart
    name: ${disp_name} Restart
time:
  - platform: sntp
    id: sntp_time
root@tuyaconvert:/home/user#
```

I'm getting this output when trying to run it:

```
root@tuyaconvert:/home/user# esphome 6chan_energy_meter-add-on_jp8-jp11.yaml run
INFO Reading configuration 6chan_energy_meter-add-on_jp8-jp11.yaml...
INFO Detected timezone 'UTC' with UTC offset 0
Failed config

sensor.atm90e32: [source 6chan_energy_meter-add-on_jp8-jp11.yaml:65]
  platform: atm90e32
  cs_pin: 5
  phase_a:
    voltage:
      name: cs_nrg_mtr Volts A
      id: ic1Volts
      accuracy_decimals: 2
    current:
      name: cs_nrg_mtr CT1 Amps
      id: ct1Amps
    power:
      name: cs_nrg_mtr CT1 Watts
      id: ct1Watts
    gain_voltage: 7305
    gain_ct: 27518
  phase_b:  [source 6chan_energy_meter-add-on_jp8-jp11.yaml:87]
    current:
      name: cs_nrg_mtr CT2 Amps
      id: ct2Amps

    [power_factor] is an invalid option for [phase_b]. Please check the indentation.
    power_factor:  [source 6chan_energy_meter-add-on_jp8-jp11.yaml:91]
      name: somename
    power:
      name: cs_nrg_mtr CT2 Watts
      id: ct2Watts
    gain_voltage: 7305
    gain_ct: 27518
  phase_c:
    current:
      name: cs_nrg_mtr CT3 Amps
      id: ct3Amps
    power:
      name: cs_nrg_mtr CT3 Watts
      id: ct3Watts
    gain_voltage: 7305
    gain_ct: 27518
  frequency:
    name: cs_nrg_mtr Freq A
  line_frequency: 60Hz
  gain_pga: 1X
  update_interval: 10s
root@tuyaconvert:/home/user#
```

What am I doing wrong?

elyorkhakimov, 2020-08-06:
Never mind, turns out I needed to run ESPhome dev branch

CircuitSetup, 2020-08-06:
@elyorkhakimov yes, power factor and a couple others are still in the dev build.

Closed 2020-08-06.

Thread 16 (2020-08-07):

Question about data sampling

elyorkhakimov, 2020-08-07:
Hi, I read through Microchip ATM90E32AS datasheet and the respective ESPHome page, but can't seem to understand how this energy meter is sampling data. I am currently running 6 channel meter (v1.4 rev1) with only 4 channels in use (waiting for more CT Clamps for the remaining 2 channels).

Question is really about the values that are send via MQTT.
In yaml file update_interval is set to 10 seconds. Does this mean that meter reports instant value of Voltage, Wattage, Current, Power factor, etc, at a given instant "t", and then after 10 seconds reports the instant value at "t+10sec" ? What about Wh readings?

Or, rather, does the meter sample with a specific sampling rate (what is it?) values for each of the sensors and takes an average of all values over the configured 10 seconds?

If there is a better place to ask these questions, please let me know and I will move this discussion there.

CircuitSetup, 2020-08-08:
That's a good question! The ATM90E32AS can write to registers several times a second. But from what I understand this can only happen if the register is read first. I have to double check this for the energy registers. I know this is the case for the cumulative energy registers (which aren't used in ESPHome anyway).

Either way, with a 10 second interval it would either be taking the energy reading at that moment or it would be reading the value from 10 seconds prior, then allowing a new value to be written. There is probably a way to configure an average in ESPHome if you wanted to do that, but I haven't looked into this yet.

If you want to calculate watt hours, this can be done in ESPHome as well.

elyorkhakimov, 2020-08-08:
Thanks for response! I just did a non-scientific experiment:
- set "update_interval" to 20 seconds
- subscribed to MQTT messages for "totalmain/power" and "totalmain/dailyenergy".

Now the idea is to check each of the values at time t1, then right after the value is reported and within 20 seconds interval turn power up something really power hungry (how about 1.3KW kettle?), and then turn it right off. That means there will be no current going through monitored CT clamp at time t1+20sec.

So, my thought process is - if the reported values average the array of all data points gathered within that 20 second time interval, I should see some non zero values in MQTT messages at time t1+20sec.

And I am glad to report that indeed, daily_energy value appears to show correct data. But power does shows what seems to be the max value in the interval.

elyorkhakimov, 2020-08-08:
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

elyorkhakimov, 2020-08-08:
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

elyorkhakimov, 2020-08-08:
However, after some more experiments, I see that 30 seconds update interval changes the abovementioned behavior. No reported values show any changes. As if nothing happened within that 30 seconds interval

elyorkhakimov, 2020-08-08:
ok, scratch all of the above. After I changed the interval to 30 seconds and then back to 20 seconds or even 10 seconds, the "cumulative" behavior stopped and now all values report immediate values.
This means that if any power load comes one for brief moment during the interval, it will not be accounted for. This is a problem.

elyorkhakimov, 2020-08-08:
Did some more tinkering. Sorry for spamming here.
I don't know why esphome was sending MQTT messages with what seemed to be cumulative Wh reading, but since now that's gone, I set the update interval to 5 seconds, and with the kettle "turned on" can see that the total_daily_energy sensor in ESPHome takes the power sensor reading in watts and integrates this instant reading value over the specified "update_interval" time value (10 seconds in my case). That's good, and I think it provides a reliable energy metering with known error margin.
The source of this error is that in this case we are relying on ESPHome to calculate the Wh energy values based on instant power readings at specified interval.
Rough error margin calculation could be:
 - at 10 seconds update interval, the Wh reading can produce error by as much as 0.2778%  (10s/3600s*100=0.2778)
 - for a 6 channel board with fully loaded 2x100Amp +4x20Amp CT clamps, this could translate to ~5.6KWh of unaccounted energy. (280Amp*120V*0.2778/100 *60min= 5600Wh)
I think this is a good level of precision, especially accounting that most households won't be consuming this much energy. And I also can't think of loads that consume high amounts of energy in such short <10sec bursts.

But I think the used  M90E32AS chip could yield really high precision results.

Based on the section 3.5 in datasheet for M90E32AS (http://ww1.microchip.com/downloads/en/DeviceDoc/Atmel-46003-SE-M90E32AS-Datasheet.pdf), this chip samples values at 1µs, and "accumulates" them. Even on the board itself there are contacts for pulses for each phase and also the blue LED blinks every so often (I actually don't know if it counts only Active energy or total sum of Active+Reactive+Apparent).

```
The energy accumulation runs at 1 MHz clock rate by accumulating the power value calculated by the DSP processor.
The power accumulation process is equivalent to digitally integrating the instantaneous power with a delta-time of about
1us. The accumulated energy is used to calculate the CF pulses and the corresponding internal energy registers.
```

Anyways, I am looking forward to see if it is possible to add per-phase energy sensors exposed in ESPHome, which pull data directly from chip registers at a fixed interval (in my opinion once every 30 or even 60 seconds should be sufficient). This way we won't have to rely on "approximated" math in ESPHome.

elyorkhakimov, 2020-08-09:
After more research, I came to conclusion that the ESPHome reports instantaneous sensor values via MQTT messages.

I see there are registers in esphome/components/atm90e32/atm90e32_reg.h that is forked here: https://github.com/esphome/esphome/compare/dev...CircuitSetup:dev ; but the energy sensors do not seem to be implemented in ESPHome.

```
/* ENERGY REGISTERS */
static const uint16_t ATM90E32_REGISTER_APENERGYT = 0x80;  // Total Forward Active
static const uint16_t ATM90E32_REGISTER_APENERGYA = 0x81;  // A Forward Active
static const uint16_t ATM90E32_REGISTER_APENERGYB = 0x82;  // B Forward Active
static const uint16_t ATM90E32_REGISTER_APENERGYC = 0x83;  // C Forward Active
static const uint16_t ATM90E32_REGISTER_ANENERGYT = 0x84;  // Total Reverse Active
static const uint16_t ATM90E32_REGISTER_ANENERGYA = 0x85;  // A Reverse Active
static const uint16_t ATM90E32_REGISTER_ANENERGYB = 0x86;  // B Reverse Active
static const uint16_t ATM90E32_REGISTER_ANENERGYC = 0x87;  // C Reverse Active
```

@CircuitSetup , how feasible it is to implement the reading from these registers into individual ESPHome sensors we could use in yaml? I recognize the ESP32 might run out of memory, but I wonder if we could sacrifice web server component and only keep `ota` and `mqtt`. Might even sacrifice `ota` in favor of getting energy sensor data from chip, rather than relying on ESPHome to calculate approximated values.

CircuitSetup, 2020-08-09:
Wow, you've done a lot of tinkering! I'm glad you're getting to know the IC!
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
CircuitSetup, 2020-08-11:
Yes, that commit is exactly what I did to add other registers.

For development I would recommend Atom with the platformio plugin installed. You'll want the dev build of ESPHome. Getting it to compile is a bit tricky at first because all of the dependencies have to be loaded.

elyorkhakimov, 2020-08-12:
Thanks!
I tried installing platformio plugin for atom, but that did not seem to work. Then tried VSCode, but when compiling getting lots of errors. Did not spend time troubleshooting it.
In the meantime, forked dev branch and made several changes, but then don't seem to figure out how to upload it with "esphome xx.yaml run" command.  I will troubleshoot more, but in the meantime thought I'd ask if you could try to run it and see if it works for you.
https://github.com/esphome/esphome/compare/dev...elyorkhakimov:energy-add

elyorkhakimov, 2020-08-13:
OK, I think I'm more or less done with the implementation. Folks over at ESPHome Discord helped me ascertain where I made mistakes.

I don't have a bench or some type of high-precision Wh-meter/Joule meter to estimate a Wh reading error, and therefore can't calibrate; but comparing to Kill-A-Watt (only measures to hundredth's of kWh) the reading is spot on. I tested by boiling a whole electric kettle of water several times.
I initially thought to create new unit UNIT_KWATT_HOURS, but then decided to just keep base Wh unit.

What's next? How can I get this into dev branch?
Would someone want to test this code some more?

This is an excerpt from the YAML:

```    phase_c:
      power_factor:
        name: ${disp_name} CT3 Power Factor
        state_topic: ${disp_name}/ct3/power_factor
      current:
        name: ${disp_name} CT3 Amps
        id: ct3Amps
        state_topic: ${disp_name}/ct3/current
      power:
        name: ${disp_name} CT3 Watts
        id: ct3Watts
        state_topic: ${disp_name}/ct3/power
      forward_active_energy:
        name: ${disp_name} CT3 WattHours
        id: ct3FAWatts
        state_topic: ${disp_name}/ct3/forward_active_energy
      reverse_active_energy:
        name: ${disp_name} CT3 WattHours
        id: ct3RAWatts
        state_topic: ${disp_name}/ct3/reverse_active_energy
      gain_voltage: ${voltage_cal}
      gain_ct: ${current_cal}```

Code is in `energy-add` branch: https://github.com/elyorkhakimov/esphome/tree/energy-add

CircuitSetup, 2020-08-16:
Excellent work! From here you can open a pull request with the dev branch of esphome. You'll have to do the same for the documents page, being sure to add examples of the new parameters and how they're used.

elyorkhakimov, 2020-08-29:
I had a chance to run my setup for few weeks now, and without any calibration of CT sensors (YHDC SCT-013 100A/50mA) spliced/extended with DIY unshielded twisted copper wire extension are giving about 1.51% error. For example, Solar inverter says it generated 22.48kWh, and my setup says 22.14, and from few days ago - 24.37 from sensor vs 24.74 from solar inverter. The only adjustment I made was of the `voltage_cal:`, set it to 7280 vs stock 7305, as it seemed that reported voltage was off. Should I do any type of calibration for CTs ?
By the way, IC1 and IC2 are reporting slightly different voltages. What could be a cause of that ?

The DIY cable extensions are made using 2x 16AWG for first CT, and 2x 18AWG for the second CT, both stranded copper TFFN wires from HomeDepot. I locked two wires of 30ft length in drill chuck and then spun it. Really, eyeballed the number of twists. Then wires untwisted a bit, and I believe the effective extension length is about 28ft. I solder-spliced in this extension cable into existing 24AWG cable that was already attached to CT sensor.
I thought the noise would be unacceptable, but, it seems that there are no issues.

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

CircuitSetup, 2020-08-29:
Glad to hear you're getting fairly accurate results, and that the extensions worked!

For the differences in IC1 and IC2, this is likely because of  variance in the resistors. They are 1%. If you need to, you can calibrate each voltage input diffetently.

For the CTs you can also adjust the calibration for a more accurate result. It may be easier to do all of the CTs at once, clamped around the same wire, with the same load.

smurfix, 2021-03-16:
@elyorkhakimov I assume you're no longer working on this?

I'd really like to log "real" energy use instead of instantaneous loads.

Closed 2021-03-22.

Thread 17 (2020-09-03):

Expandable 6 Channel ESP32 Energy Meter Add-on Board

timwing, 2020-09-03:
I got my Expandable 6 Channel ESP32 Energy Meter Main Board up and running well then realized I needed more channels :>) I added the Expandable 6 Channel ESP32 Energy Meter Add-on Board that is providing data on channels 10, 11 & 12 but not giving data on on channels 7, 8 & 9. I am using the supplied "6chan_energy_meter-add-on_jp8-jp11.yaml" and have tried moving my CT's around but still unable to get anything on 7, 8 & 9. What could I be doing wrong?

I am using ESPHome and viewing data via HomeAssistant. Any feedback would be much appreciated.

timwing, 2020-09-03:
@CircuitSetup, That was it! Looks like 5 of the 6 CS (outboard side) pins were not connected at the board. All fixed and working now. Thank you!

Tim

timwing, 2020-09-06:
@CircuitSetup So I am having some additional issues with the boards. I have had two of the 3.5mm jacks come off the board...got all those soldered back on to the main & add-on boards. Then everything was working until a day later when I had the 9-12vac come off the main board. Now that is soldered back on but now I am unable to maintain power to the unit. Works then it shuts off.

CircuitSetup, 2020-09-06:
Hum, this definitely shouldn't have happened. Are both of your boards green?

timwing, 2020-09-06:
Are you referring to the LED or the color of the printed circuit board?

Both of my printed circuit boards are green.

CircuitSetup, 2020-09-06:
Yes, the circuit board. I ask because there is a new batch of black boards that were manufactured out of house.

For the green ones, these were in house. I'm wondering if I overlooked your board in QA. When it shuts off does the green led turn off too, or just the esp32?

timwing, 2020-09-06:
Well now I get no lights on either board or esp32. I do have 11.05vac in the transformer plug.

CircuitSetup, 2020-09-06:
When the transformer plug came off, did it take any trace with it?

If you measure the output (there is a + and - over the output pins) of the black component next to the plug you should get a DC voltage.

Either way, if its dead, ill gladly send you a new main board. Let me know your order number if thats the case.

timwing, 2020-09-06:
I am a little discouraged by the parts connections coming loose. At this point I think replacement would be the best option. Order #200054

CircuitSetup, 2020-09-06:
You got it. I'll send a new main board asap. It'll be black, but is exactly the same as the green.

CircuitSetup, 2020-09-08:
This is in the mail!

Closed 2020-09-08.

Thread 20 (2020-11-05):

Chip selects in the 36 channel example

sillygoose, 2020-11-05:
These don't appear to be right, i get an error on the 35 as
```    ESP32: GPIO35 (34-39) can only be used as an input pin.```

and 27 doesn't appear in the expansion board J4 and J7 schematics pinouts.

```
...
#IC1 AddOn 2
  - platform: atm90e32
    cs_pin: 27  <==== perhaps 2?
...
#IC1 AddOn 3
  - platform: atm90e32
    cs_pin: 35  <==== perhaps 12?
...
```

I ran into some other quirks, not sure if I don't understand something or if my hardware is acting up.  Main board and 3 expansion boards and new ESP32.

First configured with the chip selects for the three boards you sent:
0/16    2/17    12/21

Result:
IO12 did not respond (blank states displayed for the 3 CT inputs on the third expansion board, first atm90e32)

Changed chip selects to:
0/16   2/17    13/21

Result:
IO13 responded but problem moved to IO2 (blank states displayed for the 3 CT inputs on the second expansion board, first atm90e32) -- weird?

Changed chip selects to
0/16   2/17   15/21

Result:
IO15 responded but IO2 did not respond (blank states for the 3 CT inputs on the second expansion board, first atm90e32)

Changed chip selects to
0/16   14/17   15/21

Result:
This set of chip selects works and all states are reported by ESPHome.  I'll live with this for now but sure would like to know if this a software or hardware issue.

CircuitSetup, 2020-11-06:
What version of the add-on boards do you have? The pin assignments changed a bit over time because, like GPIO 35, you can't use it as a CS pin. That was my mistake.

For the current pin assignments, take a look here: https://github.com/CircuitSetup/Expandable-6-Channel-ESP32-Energy-Meter#add-on-boards

sillygoose, 2020-11-07:
I have v1.4 rev 1 boards, at least the ones I have access to.  The last order I got from you is packed away in a case and I prefer not to mess with it.

Looking at the silkscreen for CS chip selects I see, 0, 27, 2? (hidden under header), 13, 14, and 15.  Since the schematic is v1.3 rev 1 perhaps they have changed?  I started with the chip selects in your example before digging into the schematic and trying those values.

CircuitSetup, 2021-02-04:
Sorry I didn't see your last question sooner. Yes, the CS pins changed a bit between 1.3 and 1.4 rev1. See the link above. Let me know if you have any other questions!

Closed 2021-02-04.

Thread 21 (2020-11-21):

Information flipping back and forth for live data

errolsancaktar, 2020-11-21:
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

i'm getting data flapping back and forth for some reason.  The voltage also seems to be way off.  i have it configured for
ct1: Input
CT2: Input
CT3: Solar input
CT4: Solar input
CT5: AC
CT6: Dryer

errolsancaktar, 2020-11-21:
strangely my mqtt is only showing the topic with connected, no sub data.

CircuitSetup, 2020-11-21:
Is this with the latest version available here? If so, can you confirm the calibration values?

errolsancaktar, 2020-11-22:
I pulled from the master branch.  so i should turn the ones that show negative amps around?  also have you seen any other instances of the CT calibration selector not showing up?  (sometimes i see a jquery error in console)
CT1/2 - 120A - 41880
CT3/4 - 100A - 27961
CT5/6 - 50A - 15420

CircuitSetup, 2020-12-08:
Sorry, I overlooked your last response!

Yes, anything showing as negative should be turned around.

It's possible that sometimes the files aren't loading properly for the interface due to connection or memory issues, or there is a bug somewhere. I haven't seen anything, nor have I seen anything reported.

errolsancaktar, 2020-12-08:
i'll swap out the esp32 and flash new to it.  also CT3 and 4 are for the solar panels, should those show negative or positive?

errolsancaktar, 2020-12-09:
Tried new board and also flipped the cts, no change.  Is it possible it's the board?

CircuitSetup, 2020-12-09:
You're still getting negative values even though the CTs were flipped? This would only happen on solar when you are exporting energy that you aren't using. For individual circuits it should never be negative, because either way that circuit is consuming power, whether it be from the grid or from solar.

The only way it could be the board is if the readings are 0 or 65.535. It sounds like the issue is in the software somewhere.  However, I've never seen temp and frequency off like they are in the first post.

Are you able to switch to ESPHome to see if you get similar readings?

errolsancaktar, 2020-12-09:
i'm not sure what you mean by switching to esphome sorry

CircuitSetup, 2020-12-09:
ESPHome is another set of software that will work with the meter. If you don't have Home Assistant running, it is a bit of a pain to set up.

However, I see that the readings for one side of the meter are all 65535, This indicates that something isn't communicating with the ESP32 properly or something is wrong with the meter.  It may be easier to send you a new one to test. Do you have your original order number handy?

errolsancaktar, 2020-12-09:
Is this it? 188072

CircuitSetup, 2020-12-10:
No, but I found your order. I'll get you a new one (v1.4 rev1, black pcb) mailed out today.

CircuitSetup, 2021-02-04:
Closing this since a new meter solved the issue.

Closed 2021-02-04.

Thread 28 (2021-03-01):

Question about Split Phase 220v

blacktirion, 2021-03-01:
Hello,

I didn't see this explicitly spelled out in the Readme.MD / Wiki:

Do I need two clamps to measure a US based 220v circuit? Is there logic in ESPhome to deal with that? I seem to be getting mixed answers on this. If I need two clamps, do I need to do the severing operation to measure two voltages?

presslab-us, 2021-03-07:
If your 240V circuit is single phase (no current on neutral) you can use one sensor.  If it's a split phase circuit (with a neutral) then you will need two sensors.

Some devices (like dryers) can look like single phase but are really split phase.  On older homes the ground connection is used as the neutral.

I believe with ESPHome you can use a multiply filter to multiply the power results by 2 to get the correct result with one sensor.
https://esphome.io/components/sensor/index.html#offset-multiply

Usually the voltages in split phase are close enough that you don't need two voltage measurements.  That's how IoTaWatt works by default.

CaptClaude, 2021-03-08:
95% of all residential distribution in the US & Canada is split-phase 240Vac. From the neutral to each phase, the voltage _should_ be 120V, but that will depend on a lot of factors, most of which you have no control over. For example, I measured my voltages at my panel last week and they were 110-130. For the purposes of monitoring energy usage, most home monitoring systems you can buy simply assume that the line-to-neutral voltage is 120V and don't bother to measure it.  If you want to be super accurate, measure both phases, but the 120V assumption is pretty accurate.
Keeping an eye on your line voltages is only important if you are suspecting that sags or transients are causing problems. And the effort required to do that is beyond what most of us are going to build.
[This is a pretty good introduction to the 120/240v residential distribution at your breaker panel.](https://theengineeringmindset.com/120-240v-split-phase-us-can/)

CircuitSetup, 2021-03-08:
> One more thing: You cannot measure the current flowing to a 240V load (dryer, stovetop, over, A/C, etc) with one current transformer (CT) clamped around both hot wires. You'll read zero because the two phase currents cancel each other magnetically. You do need two clamps (properly called CTs), one for each phase for correct measurements. However, since the voltage is the same on each phase (more or less) then the current flowing in each phase should be the same (if it's not, you have a problem) so it seems to me that measuring one phase and doubling the value would work just fine.

This is true, but if there is enough wire available, and the CT is large enough, you can pass both wires through 1 CT in opposite directions. Do not attempt this if the wire is a heavy gauge. Also, in most cases the load is balanced between both phases from the appliance, but some run electronics on 1 phase only. This likely wouldn't be an issue though since these electronics only use mA at a time.

I [updated the readme to include a section on this.](https://github.com/CircuitSetup/Expandable-6-Channel-ESP32-Energy-Meter#measuring-dual-pole-240v-circuits)

presslab-us, 2021-03-08:
A couple observations from my installation, regarding 240V appliances:

My dryer pulls about 150 watts from one phase only for the drum motor.  Because my home is older this current flows through the ground wire.  I needed to measure the current from both wires for this appliance.

My range, although it does have a dedicated neutral, only draw a few watts from this for the electronics so I ignored it and only measure one wire.

Because I couldn't route the two conductors through one cable clamp, I used an audio "Y" cable to combine two current sensors into one input.  As with two conductors in one clamp, care must be taken to ensure the measurement range of the input is not exceeded.
https://www.monoprice.com/product?p_id=30895

Closed 2021-03-22.

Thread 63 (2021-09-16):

Sensors reading with a very small negative value

profucius, 2021-09-16:
Hello, I am using your 6C main board to read the energy through four different lines in my power box. AC for upstairs, AC for downstairs, washing machine, and dryer. I've got everything configured and working well, except for one issue I cant seem to figure out.

When the appliances are currently "off", the 6C unit is sending a very small negative value in the watts sensor. I would ignore this except it gets amplified up to the kWh reading and therefore the energy cost reading in the Energy dashboard within Home Assistant.

I've triple checked my yaml within ESPHome and everything seems to be correct, it's mostly the same copied from your example file.

**What can I do to make this value absolute?**

I'm using all four "100A/50ma SCT-013-000" clamps. When the appliances turn on, I get a positive watt reading, so the issue is not that the clamps are on backwards (I've double checked that).

### What is interesting is that when one of my AC units is running, all the values are in the positive. Image below:
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

### But when no appliance is running, watt values are slightly negative.
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

CircuitSetup, 2021-09-19:
See this post in the discussion section: https://github.com/CircuitSetup/Expandable-6-Channel-ESP32-Energy-Meter/discussions/59

profucius, 2021-09-20:
Thanks for this link. I ended up resolving the issue using the advice. For anyone else who wants to know how I did it:

Editing the ESPhome yaml for the energy-meter, towards the bottom, below the last `phase_c` section" (specifically, below the last `update_interval` line), I added a new section. Here is a copy of what is in my yaml now, but of course this would need to be edited for your own purposes. The idea being that you rename the `name `and `id` fields to match your own sensor, and then rename the id within the `if (id(xxxxx).state` within `lamba` so that it references your original sensor id.

`
#===================================================================#
### Convert watts to positive numbers (since the meter sometimes reads negatives)

# Dryer Watts Positive
  - platform: template
    name: ${disp_name} Dryer - Watts Positive
    id: DryerWattsPositive
    lambda: |-
      if (id(ct1Watts).state < 0) {
        return 0;
      } else {
        return id(ct1Watts).state ;
      }
    accuracy_decimals: 1
    unit_of_measurement: W
    icon: "mdi:flash-circle"
    update_interval: ${update_time}

# Washer Watts Positive
  - platform: template
    name: ${disp_name} Washer - Watts Positive
    id: WasherWattsPositive
    lambda: |-
      if (id(ct2Watts).state < 0) {
        return 0;
      } else {
        return id(ct2Watts).state ;
      }
    accuracy_decimals: 1
    unit_of_measurement: W
    icon: "mdi:flash-circle"
    update_interval: ${update_time}

# BLANK3 Watts Positive
  - platform: template
    name: ${disp_name} BLANK3 - Watts Positive
    id: ct3WattsPositive
    lambda: |-
      if (id(ct3Watts).state < 0) {
        return 0;
      } else {
        return id(ct3Watts).state ;
      }
    accuracy_decimals: 1
    unit_of_measurement: W
    icon: "mdi:flash-circle"
    update_interval: ${update_time}

# BLANK4 Watts Positive
  - platform: template
    name: ${disp_name} BLANK4 - Watts Positive
    id: ct4WattsPositive
    lambda: |-
      if (id(ct4Watts).state < 0) {
        return 0;
      } else {
        return id(ct4Watts).state ;
      }
    accuracy_decimals: 1
    unit_of_measurement: W
    icon: "mdi:flash-circle"
    update_interval: ${update_time}

# AC Down Watts Positive
  - platform: template
    name: ${disp_name} AC Down - Watts Positive
    id: ACDownWattsPositive
    lambda: |-
      if (id(ct5Watts).state < 0) {
        return 0;
      } else {
        return id(ct5Watts).state ;
      }
    accuracy_decimals: 1
    unit_of_measurement: W
    icon: "mdi:flash-circle"
    update_interval: ${update_time}

# AC Up Watts Positive
  - platform: template
    name: ${disp_name} AC Up - Watts Positive
    id: ACUpWattsPositive
    lambda: |-
      if (id(ct6Watts).state < 0) {
        return 0;
      } else {
        return id(ct6Watts).state ;
      }
    accuracy_decimals: 1
    unit_of_measurement: W
    icon: "mdi:flash-circle"
    update_interval: ${update_time}
`

Closed 2021-09-20.

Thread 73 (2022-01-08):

Can I monitor voltage on both phases of a split-phase 240v residential feed at <= 5s intervals?

CaptClaude, 2022-01-08:
Maybe this answer is buried in the documentation somewhere but I haven't found it (yet).
I am led to this project by my need to monitor my incoming voltage for sags & swells.  I need to accumulate incoming voltage data to present to my utility to demonstrate that there is a loose neutral somewhere upstream of my meter (neighbor sees the same issue).  Once I get that solved, I will be like the rest of your users and monitor my power consumption.
I currently have borrowed Siemens 9630 power meter and record the RMS L-N voltage every 5 sec.  To determine if the issue is load-dependent, I need CTs for the meter but there are no (affordable) split-core ones that can be used with the 9630 and I am not willing to pull the meter & disconnect the mains so I can install (affordable) CTs.
This project looks like what I need (current and future) as long as I can sample/monitor line voltage and log min and max and potentially pull that data with Node-Red or push to InfluxDB and use Grafana. I'd like at least 5s reporting intervals, perhaps faster and I can average those samples elsewhere.
I considered making a voltage monitor with an ESP32 and a bunch of AC-to-RMS chips but you've already done the heavy lifting and I should support that before re-inventing the wheel.
The attached graphic is what I am seeing and it is not healthy for my appliances.
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

CaptClaude, 2022-02-20:
Excellent, thanks.  I will dig deeper into this. It looks like what I want.

Closed 2022-02-20.

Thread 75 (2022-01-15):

Components/Hardware Details

kimza90, 2022-01-15:
hi there,

I need your help!
Which hardware do you have select?
Do you have details or maybe a datasheet/shopping link?
The BOM list is missing up to several components.

best regards
kim

missmah, 2022-01-16:
Indeed, is there slack proper BOM for this project? The Eagle files seem to be missing a lot of important information. Thanks!

CircuitSetup, 2022-01-16:
There is a BOM located here: https://octopart.com/bom-tool/EwHlAzfY

There are some parts that are out of date, however and can be substituted. The burden resistors used lately are 0.1% tolerance.

missmah, 2022-01-16:
Thanks!!!

kimza90, 2022-01-16:
Thank you very much.
do you have BOM for the adon board ??

CircuitSetup, 2022-02-17:
> Thank you very much. do you have BOM for the adon board ??

Sorry I overlooked your reply. The add-on board is the same, but has 2 long 20pin headers, 1 short header, 2 12pin 2 row 2mm connectors w/ 2mm shunts, and no power supply parts (C31-C35, R22, R23, L1, D1, BR1, IC3, DC connector)

kimza90, 2022-02-18:
Thank you for your feedback. can I only use add on board if I do not need volt measurement? add power via usb power to ESP32

CircuitSetup, 2022-02-18:
The add-on board can be powered by the ESP32 usb port, yes. However, the meter's power calculations will not be correct without a voltage reference. This is okay if you only need the current measurement, or you want to calculate power in code.

kimza90, 2022-02-18:
I see that ATM90E32AS-AU-R (IC1 - IC2) has a very long delivery time have you found a replacement that works?

CircuitSetup, 2022-02-18:
> I see that ATM90E32AS-AU-R (IC1 - IC2) has a very long delivery time have you found a replacement that works?
I've run into problems recently getting them. Unfortunately the ATM90E32AS and ATM90E36 are the only ones that can be used. I believe the 36 needs one of the unconnected pins grounded though.

Closed 2022-06-01.

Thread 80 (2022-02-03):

Home Assistant Energy Page

iannecj, 2022-02-03:
This had been reporting on Energy Page completely however now while bars in individual devices are still reporting, the total grid energy graph is not.  When I go to Energy configuration in home assistant I see its complaining:

Last reset missing
The following entities have state class 'measurement' but 'last_reset' is missing:
sensor.pm_main_total_daily_kwh_farmbell

Is there new configuration in ESPhome YAML file?  I don't see this last reset aspect in the docs.

Here is my current YAML for these sensors:

`#kWh Farmbell Daily
  - platform: total_daily_energy
    name: ${disp_name} Total Daily kWh Farmbell
    power_id: totalWatts
    filters:
      - multiply: 0.001
    unit_of_measurement: kWh
    device_class: "energy"
    state_class: "measurement"

#kWh Pool
  - platform: total_daily_energy
    name: ${disp_name} Total Daily kWh Pool
    power_id: totalWattsPool
    filters:
      - multiply: 0.001
    unit_of_measurement: kWh

#kWh Upstairs AC
  - platform: total_daily_energy
    name: ${disp_name} Total Daily kWh Upstairs AC
    power_id: totalWattsUpAC
    filters:
      - multiply: 0.001
    unit_of_measurement: kWh

#kWh Downstairs AC
  - platform: total_daily_energy
    name: ${disp_name} Total Daily kWh Downstairs AC
    power_id: totalWattsDownAC
    filters:
      - multiply: 0.001
    unit_of_measurement: kWh

switch:
  - platform: restart
    name: ${disp_name} Restart
time:
  - platform: sntp
    id: sntp_time `

Meter has been flawless by the way thanks!

Thanks,

Chris

CircuitSetup, 2022-02-03:
[It looks like there was a fix to the default behavior of Total Daily Energy.](https://github.com/esphome/esphome/pull/2163)

Try changing _state_class: measurement_ to _state_class: total_increasing_

CircuitSetup, 2022-02-04:
Yes, I'll definitely change it in the examples. Thanks for bringing this to light!

CircuitSetup, 2022-02-04:
oh, I forgot to ask. Was state_class added automatically (as stated in the forum thread), or is that something you added? I'm trying to figure out if it explicitly needs to be in the config.

iannecj, 2022-02-04:
I had for the main total energy sensor in YAML and I had added it at some point.  I believe from an online example.
device_class: "energy"
state_class: "measurement"

That did not work and it complained of no last reset parameter as we said.

Based on your suggestion I changed to:
    device_class: "energy"
    state_class: "total_increasing"

And it works but it may have also worked if I had just deleted  state_class: "measurement".  Didn't try that.

CircuitSetup, 2022-02-04:
got it! Thanks for your help!

Closed 2022-02-04.

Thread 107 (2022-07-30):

Isn't reading Voltage at all, Frequency varies wildly

peely, 2022-07-30:
EDIT: Answer likely found (Thanks to [digiblurs discord](https://discord.com/channels/530777070435827722/530777070435827724/1002932133549068298)), my power adaptor was AC to DC, I had no idea AC to AC was a thing! After some searching i've found one online and have ordered. Once it arrives, and works, i'll close this issue.

Hi there, my Expandable 6 Channel has just arrived and i'm struggling to get it setup correctly, i'm hoping you can be of help :)

ESPHome flashed, reading coming back into Home Assistant via MQTT, all working. But the readings are wrong. I've used the https://github.com/CircuitSetup/Expandable-6-Channel-ESP32-Energy-Meter/blob/master/Software/ESPHome/6chan_energy_meter_main_board.yaml as my base, and modified with my local values (In the UK, so voltage and frequency are different). Please see this PR for my diff https://github.com/peely/Expandable-6-Channel-ESP32-Energy-Meter/pull/1/files

This is resulting in readings sent over MQTT that have a wildly varing Frequency,
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

And the Voltage reading of near 0 always
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

I'm well aware that this will be a PEBCAK issue, i'm just not sure what config value I can change to fix this :sweat_smile:

I've got a [50A CT Clamp](https://www.amazon.co.uk/gp/product/B07MY3NNFR) on CT1, and I also have a [30A clamp](https://www.amazon.co.uk/gp/product/B07MY361ZW) on CT2, both on the same live test wire at the moment (I wanted to see the effect clamp size had on readings, my screenshots are only of the 50A clamp). I'm not using the power supply suggested, just another 9V power supply I already had, which my volt meter tells me is outputting 9.12V

Is there anymore information I can provide to help the troubleshooting? I was following [this guide](https://www.youtube.com/watch?v=n2XZzciz0s4) linked to by the [Home Assistant Energy page](https://www.home-assistant.io/docs/energy/electricity-grid/). Thank you in advanced.

CircuitSetup, 2022-08-03:
I was going to ask if the transformer was AC/AC, and not AC/DC :)  Common mistake - glad you figured it out!

peely, 2022-08-04:
Yes indeed I did, with help :) And now i've had time to re-test it with the new power transformer and it's working great! Thank you very much. I'll close this issue now.

Closed 2022-08-04.

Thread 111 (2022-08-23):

Communication with ATM90E32 failed

max-rousseau, 2022-08-23:
Hello - I recently picked up a v1.4 rev1 board (the black one). As I was trying, unsuccessfully so, to calculate the right calibration values on a small test circuit I have (just one light bulb) the board eventually started to say that the communication failed with the sensors. I did swap them out as I was trying to figure the right calibration between all 6 plugs, to see if the measurements were the same.

To simplify I now just power it with usb power and have only one sensor in CT1. Still no dice.

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

CircuitSetup, 2022-08-23:
Hi Max - can you provide your config file? Also, what ESP32 are you using?

max-rousseau, 2022-08-23:
Of course, sorry for not including initially. Pretty vanilla. The board I am using now is Esprsesif ESP32-WROOM-32D. I think this one's a bit older I could try with another one but didn't dig deeper on that front given at least initially it was working.

```
substitutions:
  disp_name: 6C
  update_time: 10s
  current_cal: '26275' # gain_ct # old 27961
  voltage_cal: '15970' # gain_voltage # old '15970'

esphome:
  name: Foo

esp32:
  board: esp32dev
  framework:
    type: arduino

logger:
  # level: VERY_VERBOSE

# Enable Home Assistant API
api:
  encryption:
    key: "[redacted]"

ota:
  password: "[redacted]"

wifi:
  ssid: !secret wifi_ssid
  password: !secret wifi_password

  manual_ip:
    static_ip: 192.168.[redacted]
    gateway: 192.168.[redacted]
    subnet: 255.255.255.0

spi:
  clk_pin: 18
  miso_pin: 19
  mosi_pin: 23

sensor:

  - platform: wifi_signal
    name: ${disp_name} WiFi
    update_interval: 60s

  - platform: atm90e32
    cs_pin: 5
    phase_a:
      voltage:
        name: ${disp_name} Volts A
        id: ic1Volts
        accuracy_decimals: 1
      current:
        name: ${disp_name} CT1 Amps
        id: ct1Amps
      power:
        name: ${disp_name} CT1 Watts
        id: ct1Watts
      gain_voltage: ${voltage_cal}
      gain_ct: ${current_cal}

    frequency:
      name: ${disp_name} Freq A
    line_frequency: 60Hz
    gain_pga: 1X
    update_interval: ${update_time}

```

CircuitSetup, 2022-08-23:
Your config looks okay. The only other thing I would check before trying a different ESP32, is trying to connect to the other IC on the meter. Just change `cs_pin: 4`. If that connects, but `cs_pin: 5` does not, then it's an issue with the meter, and I'll send you a new one.

max-rousseau, 2022-08-24:
So I tried another ESP32 (have alot), it was one of the older DEVKITv1 which fits the wider headers. I aligned the 3v headers to the top left corner but I'm pretty sure it ended up cooking the chip (smelled like it).

Surprisingly enough - I put the smaller 32D back in and it detected the one sensor in CT1 but with really funky readings. Upon rebooting it, now it does not show the communication failed error but there are no readings coming through. Only the wifi signal.

CircuitSetup, 2022-08-24:
Okay, that's strange that the ESP32 popped. As long as it has the same number of pins it should have worked. Maybe it was just on its way out?

Also very strange that it connected momentarily with the original. It does have 19 pins per side, correct? (should be 1 row empty on the bottom of the meter)

Did you try with `cs_pin: 4`?

max-rousseau, 2022-08-24:
The one that cooked up was the earlier devkit v1 model with 15 pins on each side, while the 3V pin was aligned with the board, perhaps something else downstream didn't line up great. The current one I have in there that works on and off is a 19 pin each side (32D model)

Tried pin 4 but no dice:
> [12:53:48][C][:129]: ATM90E32:
> [12:53:48][C][atm90e32:130]:   CS Pin: GPIO4
> [12:53:48][E][atm90e32:132]: Communication with ATM90E32 failed!

To be fair however, I did try go back to pin 5 this morning and now that is also communications failed. I literally didn't touch anything on the board besides turning off the power last night and turning the test bench back on today... flaky behavior definitely throwing me off.

max-rousseau, 2022-08-25:
After a few reboots there are some readings coming through but they are pretty wild. The load on the test bench is a standard incandescent 75W bulb

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

CircuitSetup, 2022-10-21:
Was the above without the AC transformer hooked up? When volts are left floating, it can show results like this for power and frequency.

max-rousseau, 2022-10-25:
Yes the device was powered by the AC transformer.

CircuitSetup, 2022-10-25:
Okay, is the ESP32 also being powered by micro USB?

Kt527, 2024-04-20:
I had same issue. Do you solve the problem and how? All the atm90 chip error fail to communicate. I did try usb power or from power adapter.

Closed 2025-01-27.

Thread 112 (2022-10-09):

Communication with ATM90E32 failed Error

haas844, 2022-10-09:
Hi,

I recently tried setting up the 6ch main board (v1.4, rev1) to work with Homeassistant through ESPHome, and keep getting the following error for both cs_pin: 4 and cs_pin: 5:

[E][atm90e32:132]: Communication with ATM90E32 failed!

I am currently using the Jameco 157041 power supply, with a HiLetgo ESP-WROOM-32 board (https://www.amazon.com/gp/product/B0718T232Z).

When I check the logs, I get regular updates on the WiFi status and nothing for the CT sensors. Homeassistant currently shows all the sensors as 'Unknown'.

### Config
```
substitutions:
  disp_name: 6C
  update_time: 10s
  current_cal: '27961'
  voltage_cal: '7305'

esphome:
  name: homeenergymeter

esp32:
  board: esp32dev
  framework:
    type: arduino

logger:

api:
  encryption:
    key: "redacted"

ota:
  password: "redacted"

wifi:
  ssid: !secret wifi_ssid
  password: !secret wifi_password

spi:
  clk_pin: 18
  miso_pin: 19
  mosi_pin: 23

sensor:
  - platform: wifi_signal
    name: ${disp_name} WiFi
    update_interval: 60s

  - platform: atm90e32
    cs_pin: 5
    phase_a:
      voltage:
        name: ${disp_name} Volts A
        id: ic1Volts
        accuracy_decimals: 1
      current:
        name: ${disp_name} CT1 Amps
        id: ct1Amps
      gain_voltage: ${voltage_cal}
      gain_ct: ${current_cal}
    phase_b:
      current:
        name: ${disp_name} CT2 Amps
        id: ct2Amps
      gain_ct: ${current_cal}
    phase_c:
      current:
        name: ${disp_name} CT3 Amps
        id: ct3Amps
      gain_ct: ${current_cal}
    frequency:
      name: ${disp_name} Freq A
    line_frequency: 60Hz
    gain_pga: 1X
    update_interval: ${update_time}

  - platform: atm90e32
    cs_pin: 4
    phase_a:
      voltage:
        name: ${disp_name} Volts B
        id: ic2Volts
        accuracy_decimals: 1
      current:
        name: ${disp_name} CT4 Amps
        id: ct4Amps
      gain_voltage: ${voltage_cal}
      gain_ct: ${current_cal}
    phase_b:
      current:
        name: ${disp_name} CT5 Amps
        id: ct5Amps
      gain_ct: ${current_cal}
    phase_c:
      current:
        name: ${disp_name} CT6 Amps
        id: ct6Amps
      gain_ct: ${current_cal}
    frequency:
      name: ${disp_name} Freq B
    line_frequency: 60Hz
    gain_pga: 1X
    update_interval: ${update_time}

switch:
  - platform: restart
    name: ${disp_name} Restart
```
### Logs
```
INFO Reading configuration /config/esphome/homeenergymeter.yaml...
WARNING GPIO4 is a Strapping PIN and should be avoided.
Attaching external pullup/down resistors to strapping pins can cause unexpected failures.
See https://esphome.io/guides/faq.html#why-am-i-getting-a-warning-about-strapping-pins
INFO Starting log output from homeenergymeter.local using esphome API
INFO Successfully connected to homeenergymeter.local
[13:55:04][I][app:102]: ESPHome version 2022.9.4 compiled on Oct  9 2022, 13:43:41
[13:55:04][C][wifi:502]: WiFi:
[13:55:04][C][wifi:360]:   Local MAC: [redacted]
[13:55:04][C][wifi:361]:   SSID: [redacted]
[13:55:04][C][wifi:362]:   IP Address: [redacted]
[13:55:04][C][wifi:364]:   BSSID: [redacted]
[13:55:04][C][wifi:365]:   Hostname: 'homeenergymeter'
[13:55:04][C][wifi:367]:   Signal strength: -62 dB ▂▄▆█
[13:55:04][C][wifi:371]:   Channel: 6
[13:55:04][C][wifi:372]:   Subnet: 255.255.255.0
[13:55:04][C][wifi:373]:   Gateway: 192.168.1.1
[13:55:04][C][wifi:374]:   DNS1: 8.8.8.8
[13:55:04][C][wifi:375]:   DNS2: 8.8.4.4
[13:55:04][C][logger:275]: Logger:
[13:55:04][C][logger:276]:   Level: DEBUG
[13:55:04][C][logger:277]:   Log Baud Rate: 115200
[13:55:04][C][logger:278]:   Hardware UART: UART0
[13:55:04][C][spi:101]: SPI bus:
[13:55:04][C][spi:102]:   CLK Pin: GPIO18
[13:55:04][C][spi:103]:   MISO Pin: GPIO19
[13:55:04][C][spi:104]:   MOSI Pin: GPIO23
[13:55:04][C][spi:106]:   Using HW SPI: YES
[13:55:04][C][:129]: ATM90E32:
[13:55:04][C][atm90e32:130]:   CS Pin: GPIO5
[13:55:04][E][atm90e32:132]: Communication with ATM90E32 failed!
[13:55:04][C][atm90e32:134]:   Update Interval: 10.0s
[13:55:04][C][atm90e32:135]:   Voltage A '6C Volts A'
[13:55:04][C][atm90e32:135]:     Device Class: 'voltage'
[13:55:04][C][atm90e32:135]:     State Class: 'measurement'
[13:55:04][C][atm90e32:135]:     Unit of Measurement: 'V'
[13:55:04][C][atm90e32:135]:     Accuracy Decimals: 1
[13:55:04][C][atm90e32:136]:   Current A '6C CT1 Amps'
[13:55:04][C][atm90e32:136]:     Device Class: 'current'
[13:55:04][C][atm90e32:136]:     State Class: 'measurement'
[13:55:04][C][atm90e32:136]:     Unit of Measurement: 'A'
[13:55:04][C][atm90e32:136]:     Accuracy Decimals: 2
[13:55:04][C][atm90e32:143]:   Current B '6C CT2 Amps'
[13:55:04][C][atm90e32:143]:     Device Class: 'current'
[13:55:04][C][atm90e32:143]:     State Class: 'measurement'
[13:55:04][C][atm90e32:143]:     Unit of Measurement: 'A'
[13:55:04][C][atm90e32:143]:     Accuracy Decimals: 2
[13:55:04][C][atm90e32:150]:   Current C '6C CT3 Amps'
[13:55:04][C][atm90e32:150]:     Device Class: 'current'
[13:55:04][C][atm90e32:150]:     State Class: 'measurement'
[13:55:04][C][atm90e32:150]:     Unit of Measurement: 'A'
[13:55:04][C][atm90e32:150]:     Accuracy Decimals: 2
[13:55:04][C][atm90e32:156]:   Frequency '6C Freq A'
[13:55:04][C][atm90e32:156]:     State Class: 'measurement'
[13:55:04][C][atm90e32:156]:     Unit of Measurement: 'Hz'
[13:55:04][C][atm90e32:156]:     Accuracy Decimals: 1
[13:55:04][C][atm90e32:156]:     Icon: 'mdi:current-ac'
[13:55:04][C][:129]: ATM90E32:
[13:55:04][C][atm90e32:130]:   CS Pin: GPIO4
[13:55:04][E][atm90e32:132]: Communication with ATM90E32 failed!
[13:55:04][C][atm90e32:134]:   Update Interval: 10.0s
[13:55:04][C][atm90e32:135]:   Voltage A '6C Volts B'
[13:55:04][C][atm90e32:135]:     Device Class: 'voltage'
[13:55:04][C][atm90e32:135]:     State Class: 'measurement'
[13:55:04][C][atm90e32:135]:     Unit of Measurement: 'V'
[13:55:05][C][atm90e32:135]:     Accuracy Decimals: 1
[13:55:05][C][atm90e32:136]:   Current A '6C CT4 Amps'
[13:55:05][C][atm90e32:136]:     Device Class: 'current'
[13:55:05][C][atm90e32:136]:     State Class: 'measurement'
[13:55:05][C][atm90e32:136]:     Unit of Measurement: 'A'
[13:55:05][C][atm90e32:136]:     Accuracy Decimals: 2
[13:55:05][C][atm90e32:143]:   Current B '6C CT5 Amps'
[13:55:05][C][atm90e32:143]:     Device Class: 'current'
[13:55:05][C][atm90e32:143]:     State Class: 'measurement'
[13:55:05][C][atm90e32:143]:     Unit of Measurement: 'A'
[13:55:05][C][atm90e32:143]:     Accuracy Decimals: 2
[13:55:05][C][atm90e32:150]:   Current C '6C CT6 Amps'
[13:55:05][C][atm90e32:150]:     Device Class: 'current'
[13:55:05][C][atm90e32:150]:     State Class: 'measurement'
[13:55:05][C][atm90e32:150]:     Unit of Measurement: 'A'
[13:55:05][C][atm90e32:150]:     Accuracy Decimals: 2
[13:55:05][C][atm90e32:156]:   Frequency '6C Freq B'
[13:55:05][C][atm90e32:156]:     State Class: 'measurement'
[13:55:05][C][atm90e32:156]:     Unit of Measurement: 'Hz'
[13:55:05][C][atm90e32:156]:     Accuracy Decimals: 1
[13:55:05][C][atm90e32:156]:     Icon: 'mdi:current-ac'
[13:55:05][C][restart:022]: Restart Switch '6C Restart'
[13:55:05][C][restart:022]:   Icon: 'mdi:restart'
[13:55:05][C][mdns:100]: mDNS:
[13:55:05][C][mdns:101]:   Hostname: homeenergymeter
[13:55:05][C][ota:089]: Over-The-Air Updates:
[13:55:05][C][ota:090]:   Address: homeenergymeter.local:3232
[13:55:05][C][ota:093]:   Using Password.
[13:55:05][C][api:138]: API Server:
[13:55:05][C][api:139]:   Address: homeenergymeter.local:6053
[13:55:05][C][api:141]:   Using noise encryption: YES
[13:55:05][C][wifi_signal.sensor:009]: WiFi Signal '6C WiFi'
[13:55:05][C][wifi_signal.sensor:009]:   Device Class: 'signal_strength'
[13:55:05][C][wifi_signal.sensor:009]:   State Class: 'measurement'
[13:55:05][C][wifi_signal.sensor:009]:   Unit of Measurement: 'dBm'
[13:55:05][C][wifi_signal.sensor:009]:   Accuracy Decimals: 0
[13:55:09][D][sensor:127]: '6C WiFi': Sending state -61.00000 dBm with 0 decimals of accuracy
[13:56:09][D][sensor:127]: '6C WiFi': Sending state -62.00000 dBm with 0 decimals of accuracy
[13:57:09][D][sensor:127]: '6C WiFi': Sending state -61.00000 dBm with 0 decimals of accuracy
[13:58:09][D][sensor:127]: '6C WiFi': Sending state -61.00000 dBm with 0 decimals of accuracy
[13:59:09][D][sensor:127]: '6C WiFi': Sending state -61.00000 dBm with 0 decimals of accuracy
[14:00:09][D][sensor:127]: '6C WiFi': Sending state -61.00000 dBm with 0 decimals of accuracy
[14:01:09][D][sensor:127]: '6C WiFi': Sending state -61.00000 dBm with 0 decimals of accuracy
[14:02:09][D][sensor:127]: '6C WiFi': Sending state -61.00000 dBm with 0 decimals of accuracy
[14:03:09][D][sensor:127]: '6C WiFi': Sending state -62.00000 dBm with 0 decimals of accuracy
```

CircuitSetup, 2022-10-21:
I"m sorry the meter is giving you issues. Everything looks okay in the logs.

Can you confirm that the ESP32 is being powered by the meter?

haas844, 2022-10-21:
Hi,

I believe it was an issue with the ESP32 I was using, I switched to the following board and everything started working as it should:

KeeYees ESP32S
https://www.amazon.com/gp/aw/d/B07QCP2451

Thanks!

Closed 2022-10-21.

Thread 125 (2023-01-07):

Off topic - estimate time for new stock

ray-matos-mpf, 2023-01-07:
Estimated time for boards to be back in stock?

Azylog, 2023-03-20:
Hello,
Are you still making/selling the 6C energy meter ? I sent an e-mail 2 weeks ago about getting it by myself and got no answer.
News about stock is also pretty old on the shop.
I understand perfectly you don't want/can start new batches as it takes some time to check highly variable stocks and so on.

My main question is : should we get it by our own so you can focus on software/anything else ?

I received 5 assembled PCB from JLCPCB last friday. Just missing the female headers which I soldered myself.
And I just ordered 20 add-ons cards, now JLCPCB is almost out of stock for ATM90E32AS ;-(.

You made a really nice open-hardware stuff, ordering it directly is making me a bit ashamed ...

I'm already thinking of some modifications that could be some fun : add ESP32 directly on the board, remove J16, check if BR1 should really be 2A (hard to find), try to get rid of those stackable headers, etc ...

Thanks,
Julien

CircuitSetup, 2023-03-20:
The 6 channel energy meters will be in stock this Thursday!

@Azylog feel free to make your own! I thought about putting the module directly on the pcb, but this would make everything larger, and would eliminate the stackable feature of the add-on boards. BR1 does not need to be 2A, also.

Azylog, 2023-03-21:
Hey ! Thanks for your answer ! Glad to hear you could had some stock.

You don't necessarily to put a MODULE on the board. As you already provide 3.3V, it could simply be an IC, an 40Mhz XTAL and a few 0603 condensators. The main concern here is probably the antenna.
Wemos have already done most of the work here with ESP32-S2FH4 : https://www.wemos.cc/en/latest/_static/files/sch_s2_mini_v1.0.0.pdf
But I wonder if that could still be routed on a 2 layers PCB ? I'll try in a few weeks and try to share the results. Off course, we should keep the stackable add-on feature by routing power, VA and all SPI pins (MOSI, MISO, CKL and 10xCS if I'm right).

For now, I'll focus on software. For example, I'm trying to define current_cal from a select in esphome.

And finally, about BR1 : LMR14020 is rated for 2A, that's probably why you defined it as 50V/2A. Any idea about the max current used by IC3 with 5 add-on boards ?
I could measure it when I receive my add-on boards but you probably already have done it ?

Thanks !

(and perhaps should I open a new thread, sorry)

holblin, 2023-08-12:
Stocks seems to be still an issue 😕 any way to get a two phases, 30 or 36 channels bundle 😶
I'm doing a panel change and wanted to throw it while the electrician is there!

Azylog, 2023-08-12:
I still have a few boards from my batch as I made more than used actually. I can sell them but only in EU and in euros, this is not my business and I won't struggle with customs. And provide an invoice, of course.

holblin, 2023-08-13:
I'm in US :-/

Closed 2024-07-25.

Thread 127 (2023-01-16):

Power (watts) not calculated for IC2 on addon board

is343, 2023-01-16:
Hello! I just setup my addon board and am running into an issue where the addon board's IC2 is picking up current values but is not calculating any power.
I am measuring 2 voltages with 2 adapters plugged into different phase outlets. I severed the JP13 and JP12 connections on both the mainboard and the addon board.

The instructions don't specifically mention also severing the addon boards so maybe this is where the issue is from? I was speculating to myself that maybe it's an issue of it not getting any voltage so it's calculating based on 0 volts, but I have no idea if that is the case or not.

Both boards are v1.4.

Everything is working fine for CT 1-10. It's only CT 11, 12, and 13 that are doing this.

Any idea what might be going on with this?

Here's a screenshot of what I'm seeing in Home Assistant:
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

I've checked over my yaml a few times now. I don't think I'm missing anything, but here is the the main sensor setup:

```
sensor:
  - platform: wifi_signal
    name: ${disp_name} WiFi
    update_interval: 60s
#IC1 Main
  - platform: atm90e32
    cs_pin: 5
    frequency:
      name: ${disp_name} Frequency
    line_frequency: 60Hz
    gain_pga: 1X
    update_interval: ${update_time}
    chip_temperature:
      name: ${disp_name} Port 1-3 Chip Temp
    # Port 1
    # MAINS INPUT A
    phase_a:
      voltage:
        name: ${disp_name} Volts A
        id: ic1Volts
        accuracy_decimals: 1
      current:
        name: ${disp_name} CT1 Amps
        id: ct1Amps
        accuracy_decimals: 3
# The max value for current that the meter can output is 65.535. If you expect to measure current over 65A,
# divide the gain_ct by 2 (120A CT) or 4 (200A CT) and multiply the current and power values by 2 or 4 by uncommenting the filter below
#        filters:
#          - multiply: 2
      power:
        name: ${disp_name} CT1 Watts
        id: ct1Watts
        accuracy_decimals: 2
#        filters:
#          - multiply: 2
      reactive_power:
        name: ${disp_name} CT1 Reactive Power
        id: ct1ReactivePower
      power_factor:
        name: ${disp_name} CT1 Power Factor
        id: ct1PowerFactor
      gain_voltage: ${voltage_cal}
      gain_ct: ${current_cal_120A}
    # Port 2
    # ELECTRIC RANGE A
    phase_b:
      current:
        name: ${disp_name} CT2 Amps
        id: ct2Amps
        accuracy_decimals: 3
      power:
        name: ${disp_name} CT2 Watts
        id: ct2Watts
        accuracy_decimals: 2
      reactive_power:
        name: ${disp_name} CT2 Reactive Power
        id: ct2ReactivePower
      power_factor:
        name: ${disp_name} CT2 Power Factor
        id: ct2PowerFactor
      gain_voltage: ${voltage_cal}
      gain_ct: ${current_cal_80A}
    # Port 3
    # WATER HEATER A
    phase_c:
      current:
        name: ${disp_name} CT3 Amps
        id: ct3Amps
        accuracy_decimals: 3
      power:
        name: ${disp_name} CT3 Watts
        id: ct3Watts
        accuracy_decimals: 2
      reactive_power:
        name: ${disp_name} CT3 Reactive Power
        id: ct3ReactivePower
      power_factor:
        name: ${disp_name} CT3 Power Factor
        id: ct3PowerFactor
      gain_voltage: ${voltage_cal}
      gain_ct: ${current_cal_80A}

# #IC2 Main
  - platform: atm90e32
    cs_pin: 4
    # frequency:
    #   name: ${disp_name} Port 4-6 Frequency
    line_frequency: 60Hz
    gain_pga: 1X
    update_interval: ${update_time}
    chip_temperature:
      name: ${disp_name} Port 4-6 Chip Temp
    # Port 4
    # MAINS INPUT B
    phase_a:
      voltage:
        name: ${disp_name} Volts B
        id: ic2Volts
        accuracy_decimals: 1
      current:
        name: ${disp_name} CT4 Amps
        id: ct4Amps
        accuracy_decimals: 3
      power:
        name: ${disp_name} CT4 Watts
        id: ct4Watts
      reactive_power:
       name: ${disp_name} CT4 Reactive Power
       id: ct4ReactivePower
      power_factor:
        name: ${disp_name} CT4 Power Factor
        id: ct4PowerFactor
      gain_voltage: ${voltage_cal}
      gain_ct: ${current_cal_120A}
    # Port 5
    # WASHER/DRYER
    phase_b:
      current:
        name: ${disp_name} CT5 Amps
        id: ct5Amps
        accuracy_decimals: 3
      power:
        name: ${disp_name} CT5 Watts
        id: ct5Watts
        accuracy_decimals: 2
      reactive_power:
        name: ${disp_name} CT5 Reactive Power
        id: ct5ReactivePower
      power_factor:
        name: ${disp_name} CT5 Power Factor
        id: ct5PowerFactor
      gain_voltage: ${voltage_cal}
      gain_ct: ${current_cal_80A}
    # Port 6
    # ELECTRIC RANGE B
    phase_c:
      current:
        name: ${disp_name} CT6 Amps
        id: ct6Amps
        accuracy_decimals: 3
      power:
        name: ${disp_name} CT6 Watts
        id: ct6Watts
      reactive_power:
       name: ${disp_name} CT6 Reactive Power
       id: ct6ReactivePower
      power_factor:
        name: ${disp_name} CT6 Power Factor
        id: ct6PowerFactor
      gain_voltage: ${voltage_cal}
      gain_ct: ${current_cal_80A}

#IC1 AddOn 1
  - platform: atm90e32
    cs_pin: 0
    line_frequency: 60Hz
    gain_pga: 1X
    update_interval: ${update_time}
    # frequency:
    #   name: ${disp_name} Port 7-9 Frequency
    chip_temperature:
      name: ${disp_name} Port 7-9 Chip Temp
    #Port 7
    # HVAC UNIT 1 A
    phase_a:
      current:
        name: ${disp_name} CT7 Amps
        id: ct7Amps
        accuracy_decimals: 3
      power:
        name: ${disp_name} CT7 Watts
        id: ct7Watts
        accuracy_decimals: 2
      reactive_power:
        name: ${disp_name} CT7 Reactive Power
        id: ct7ReactivePower
      power_factor:
        name: ${disp_name} CT7 Power Factor
        id: ct7PowerFactor
      gain_voltage: ${voltage_cal}
      gain_ct: ${current_cal_80A}
    # Port 8
    # HVAC UNIT 2 A
    phase_b:
      current:
        name: ${disp_name} CT8 Amps
        id: ct8Amps
        accuracy_decimals: 3
      power:
        name: ${disp_name} CT8 Watts
        id: ct8Watts
        accuracy_decimals: 2
      reactive_power:
        name: ${disp_name} CT8 Reactive Power
        id: ct8ReactivePower
      power_factor:
        name: ${disp_name} CT8 Power Factor
        id: ct8PowerFactor
      gain_voltage: ${voltage_cal}
      gain_ct: ${current_cal_80A}
    # Port 9
    # BEDROOM / OFFICE OUTLETS
    phase_c:
      current:
        name: ${disp_name} CT9 Amps
        id: ct9Amps
        accuracy_decimals: 3
      power:
        name: ${disp_name} CT9 Watts
        id: ct9Watts
      reactive_power:
       name: ${disp_name} CT9 Reactive Power
       id: ct9ReactivePower
      power_factor:
        name: ${disp_name} CT9 Power Factor
        id: ct9PowerFactor
      gain_voltage: ${voltage_cal}
      gain_ct: ${current_cal_80A}

#IC2 AddOn 1
  - platform: atm90e32
    cs_pin: 16
    line_frequency: 60Hz
    gain_pga: 1X
    update_interval: ${update_time}
    # frequency:
    #   name: ${disp_name} Port 10-12 Frequency
    chip_temperature:
      name: ${disp_name} Port 10-12 Chip Temp
    #Port 10
    # WATER HEATER B
    phase_a:
      current:
        name: ${disp_name} CT10 Amps
        id: ct10Amps
        accuracy_decimals: 3
      power:
        name: ${disp_name} CT10 Watts
        id: ct10Watts
        accuracy_decimals: 2
      reactive_power:
        name: ${disp_name} CT10 Reactive Power
        id: ct10ReactivePower
      power_factor:
        name: ${disp_name} CT10 Power Factor
        id: ct10PowerFactor
      gain_voltage: ${voltage_cal}
      gain_ct: ${current_cal_80A}
    # Port 11
    # HVAC UNIT 1 B
    phase_b:
      current:
        name: ${disp_name} CT11 Amps
        id: ct11Amps
        accuracy_decimals: 3
      power:
        name: ${disp_name} CT11 Watts
        id: ct11Watts
        accuracy_decimals: 2
      reactive_power:
        name: ${disp_name} CT11 Reactive Power
        id: ct11ReactivePower
      power_factor:
        name: ${disp_name} CT11 Power Factor
        id: ct11PowerFactor
      gain_voltage: ${voltage_cal}
      gain_ct: ${current_cal_80A}
    # Port 12
    # HVAC UNIT 2 B
    phase_c:
      current:
        name: ${disp_name} CT12 Amps
        id: ct12Amps
        accuracy_decimals: 3
      power:
        name: ${disp_name} CT12 Watts
        id: ct12Watts
      reactive_power:
       name: ${disp_name} CT12 Reactive Power
       id: ct12ReactivePower
      power_factor:
        name: ${disp_name} CT12 Power Factor
        id: ct12PowerFactor
      gain_voltage: ${voltage_cal}
      gain_ct: ${current_cal_80A}
```

CircuitSetup, 2023-02-03:
Sorry I didn't see your issue earlier.

For the add-on board, severing the jumpers will not pass the voltage to the right side of the board (CT4-6). So, if you want to calculate wattage, you'll either need to hook up VA2 on the add-on to the other transformer, or bridge the jumpers again to get voltage from the first transformer hooked up to the jack on the main board.

is343, 2023-02-03:
@CircuitSetup thank you for the reply.

Okay, just to confirm, if I rebridge the jumpers, then IC2 will be using the same voltage from IC1, correct?

So, if I want to keep IC2 using the second voltage, I should also hook the addon board up to the second AC source, just like I did with with the main board.

CircuitSetup, 2023-02-03:
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

Yes, that is correct.

is343, 2023-02-04:
I was able to jump the voltage from the main board to the addon board, and it's now working just fine. Thanks for clearing this up!

Closed 2023-02-04.

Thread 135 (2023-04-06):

6Ch crash on brownout

yn1v, 2023-04-06:
I have consistently having crashes when a brownout occurs. Sometimes the voltage drops to the point where some devices shutdown like TVs or fans with ir remote controls. LED lamps shutdown and then come back. On these occacions the 6 channel board crashes and stops responding. I need to unplug the wall transformer to reboot the board. As the wall transformer provides the input to the voltage sensor makes impractical put a voltage regulator. I was thinking about a high-low voltage cut. The board has emonesp sending data to a emoncms local server. I also have a local server running homeassistant. It may be possible to setup a relay to reset the power when the emonesp stops sending data. Any suggestion?

CircuitSetup, 2023-06-05:
Sorry I did not get back to you sooner.

I would highly recommend using ESPHome if you already have Home Assistant running. It's more integrated and will probably restart properly if there is a brownout.

Closed 2025-01-27.

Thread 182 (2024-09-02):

Never ending calibration for 6channel power meter

gonzoyumo, 2024-09-02:
Hello, 

I finally started the setup of my power metter and I might do something wrong but I can't get it to report accurrate current when testing different loads.

I'm doing the calibration following https://github.com/CircuitSetup/Split-Single-Phase-Energy-Meter#calibration and watched the videos but anytime I'm calibrating my CTs correctly with a given load like a heat gun at low settings (7.6A) when I change that load to something bigger like the heat gun at high setting (10.8A) or the kettle (11.4A) then the measurements are off with what the kill a watt reports (voltage and current).

My setup is as follow:
- A power cord with 2 outlets, one is for the  kill A watt and the rest of the setup, the other for the AC adapter to the powe-metter.
- From the kill a watt, I have a custom made power cord with split conductors (romex 14awg) connected to an outlet on which I plug the heat gun and the kettle
- I'm only testing with 3 CTs for now, two 80A/26.6mA - YHDC SCT-010 (CT1 and CT2) and one 120A/40mA - YHDC SCT-016 (CT3) which are all on the load (black wire).
- The AC adapter I'm using is the Jameco 112336 (9v 1500ma). 

After calibrating for the Kettle:
- Kill-A-Watt: 111V, 11.4A
- Power metter:
  - Volts: 110.87V (gain_voltage: 7609)
  - CT1: 11.370A (gain_ct: 41886)
  - CT2: 11.372A (gain_ct: 42066)
  - CT3: 11.373A (gain_ct: 41711)

Then, switching to the heat gun low setting:

- Kill-A-Watt: 116.2V, 7.66A
- Power metter:
  - Volts: 114.84v (gain_voltage: 7609)
  - CT1: 5.471A
  - CT2: 5.836A
  - CT3: 5.510A 

That's a 2A difference! And of course, if I recalibrate for the heat gun low setting, when I test with high setting or the kettle, then the measurements are off again :/ 

I've tested on IC2 (CT 4, CT5, and CT6) and also by removing the 2 add on boards I have, just in case, but I'm facing the same behavior.

Am I missing something here? Thank you for you assistance.

NB: I tried to open a ticket on https://circuitsetup.us/ but got an error " Block Reason: | A potentially unsafe operation has been detected in your request to this site"

CircuitSetup, 2024-09-09:
I'm sorry the meter is giving you trouble with calibration. Can you post your config file if using ESPHome?

Also, what are you seeing for the power output in both scenarios?

CircuitSetup, 2024-09-10:
Thanks for supplying that data!

I asked about the power output, because I suspected the kill-a-watt wasn't taking power factor into account. I'm guessing the difference you're seeing in the amperage is because of the power factor. Although, for a resistive load, the PF should be at 1 or really close to 1.

Are you in an apartment building or on a power system that is not split single phase?

CircuitSetup, 2024-09-10:
Okay, then your voltage and current should be in phase with each other. To be sure, can you try adding the power_factor parameter to your config? You may also want to take a look at reactive_power
See here for details on adding those parameters: https://esphome.io/components/sensor/atm90e32.html

gonzoyumo, 2024-09-10:
@CircuitSetup I think you've nailed it! I did not even know there was a PF indication on the Kill-A-Watt 🤦

So the fun fact is that when usign the heat gun in `high` mode, PF is 1, but when using in `low` mode, PF drops to `0.68` on the Kill-A-Watt...

The power metter output was indicating a PF of `0.88`. See below:

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

I also tested with a toaster/grill which as a PF of 1 on the kill-a-watt and the power metter output was aligned with the kill-A-Watt on all measurements 👍. I wish I had tested that before :/

Now I have to further understand what this all mean when tracking energy usage of my house 😄

Thanks a lot for your help 🙇

Closed 2024-09-10.

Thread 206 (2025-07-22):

Unable to properly flash ESP32-S3-WROOM-1

alexbreezy92, 2025-07-22:
I've tried the web installer at this link using both CircuitSetup 6 Channel Energy Meter Main on 2025.8.0-dev and 2025.7.2 firmware. I've tried the USB and the COM port for programming. I've held the device is reset while clicking install and then doing the boot button while holding reset then releasing reset then waiting a moment to hit bootloader then releasing the boot button. Your installer calls it an unsupported device at that point. I've flashed the firmware successfully with both the python esp flasher that is capable of driving reset and boot through software. I've also flashed successfully with https://web.esphome.io/. Both python and esphome will not allow me to configure wifi. The logs are spamming this print out...

[06:10:46]invalid header: 0xffffffff
[06:10:46]invalid header: 0xffffffff
[06:10:46]Build:Mar 27 2021
[06:10:46]rst:0x7 (TG0WDT_SYS_RST),boot:0x8 (SPI_FAST_FLASH_BOOT)
[06:10:46]Saved PC:0x40048836
[06:10:46]invalid header: 0xffffffff
[06:10:46]invalid header: 0xffffffff
[06:10:46]invalid header: 0xffffffff

My guess here is that this is all related to either SPI mode or SPI flash size. I should also mention I've tried 3 of these ESP32s. Could you provide some adjustments I could make to resolve this? I'm an electrical engineer on embedded computing systems so you don't have to necessarily hold my hand on this one.

Board: https://www.amazon.com/DORHEA-Development-Bluetooth-ESP32-S3-DevKit-ESP32-S3-WROOM/dp/B0CKXJLP4B

alexbreezy92, 2025-07-24:
Ordered the above esp32 and was able to flash it. closing this issue out. thanks for your help.

Closed 2025-07-24.

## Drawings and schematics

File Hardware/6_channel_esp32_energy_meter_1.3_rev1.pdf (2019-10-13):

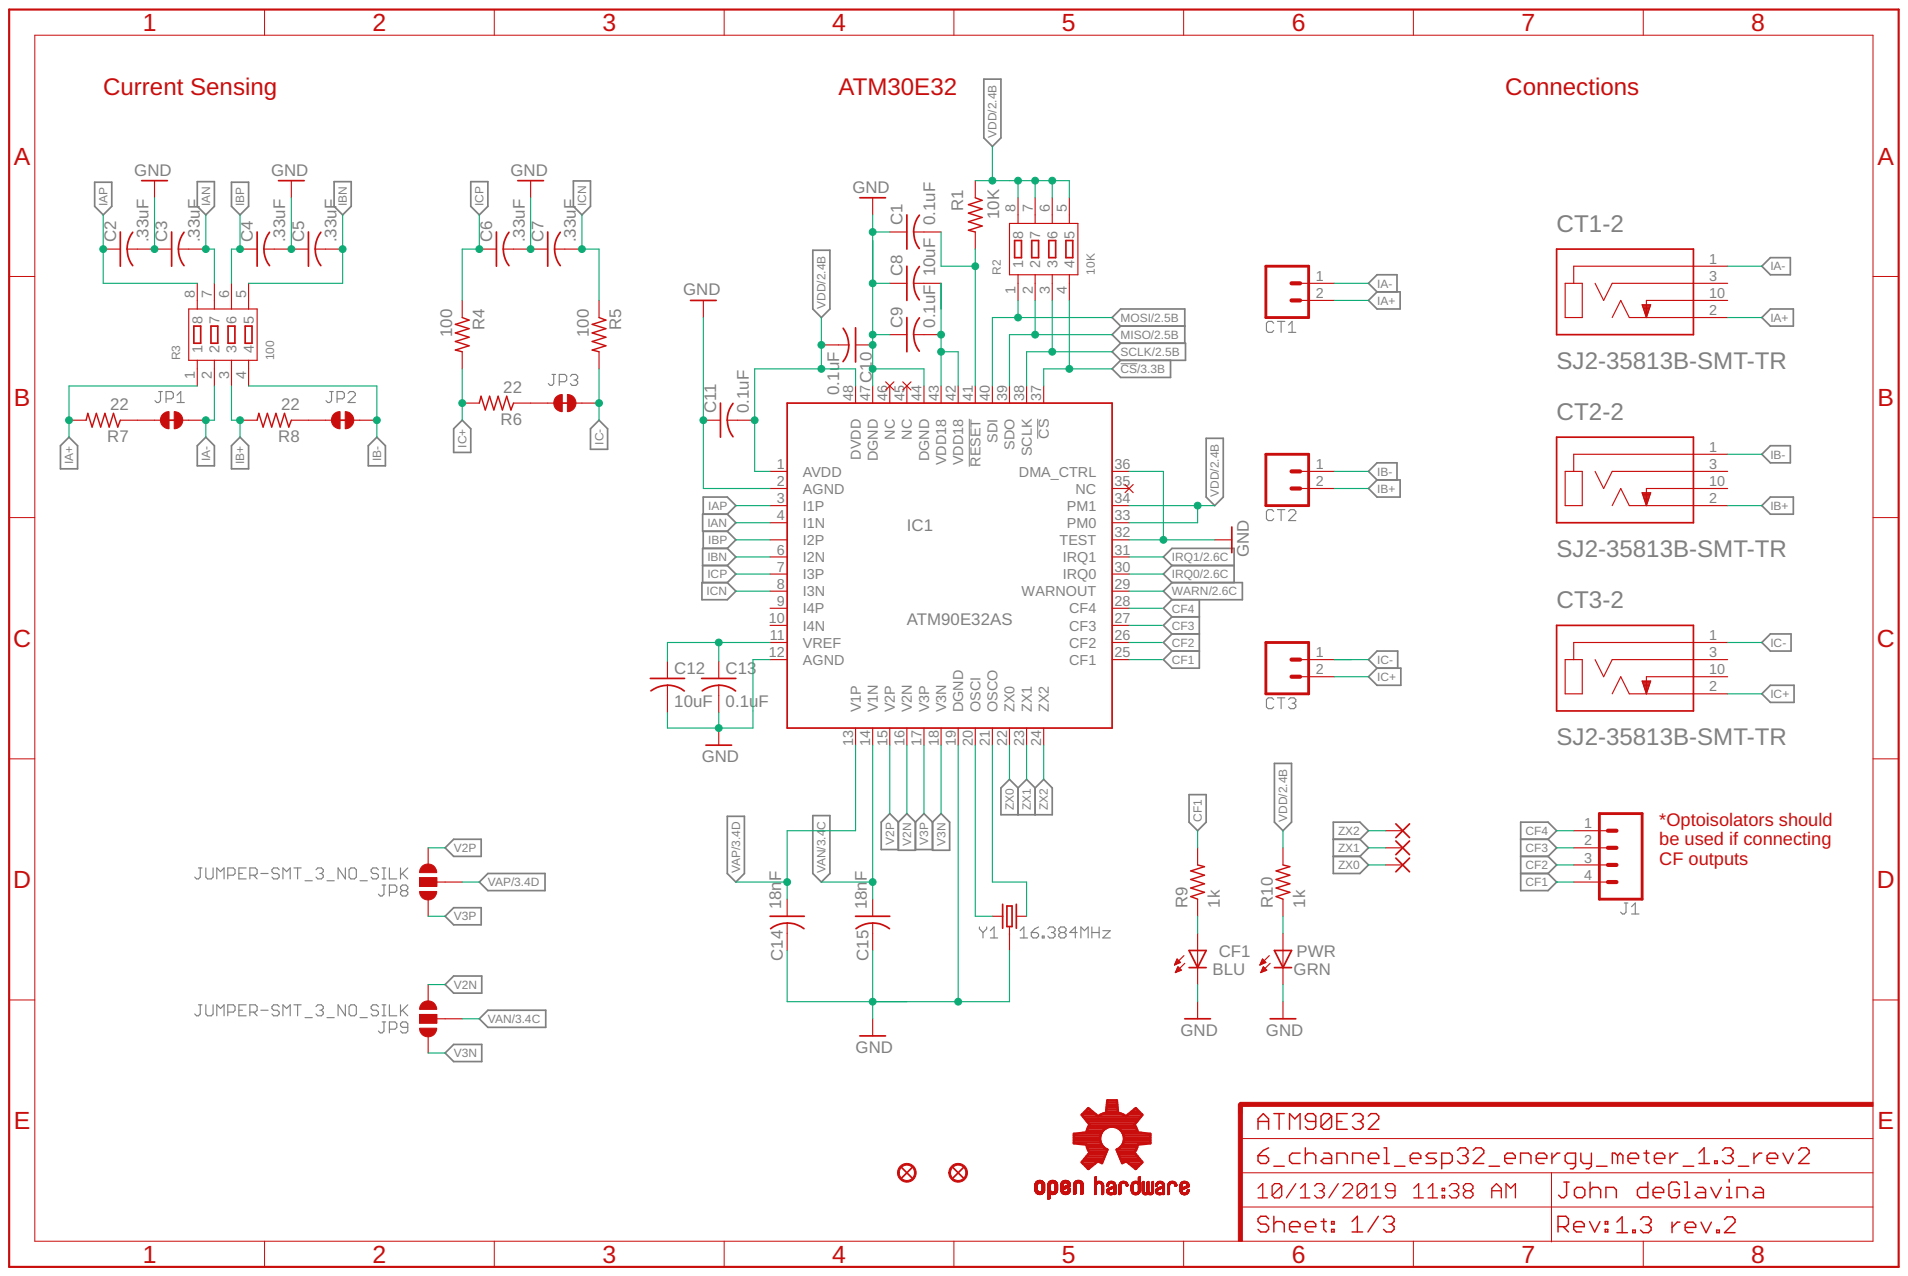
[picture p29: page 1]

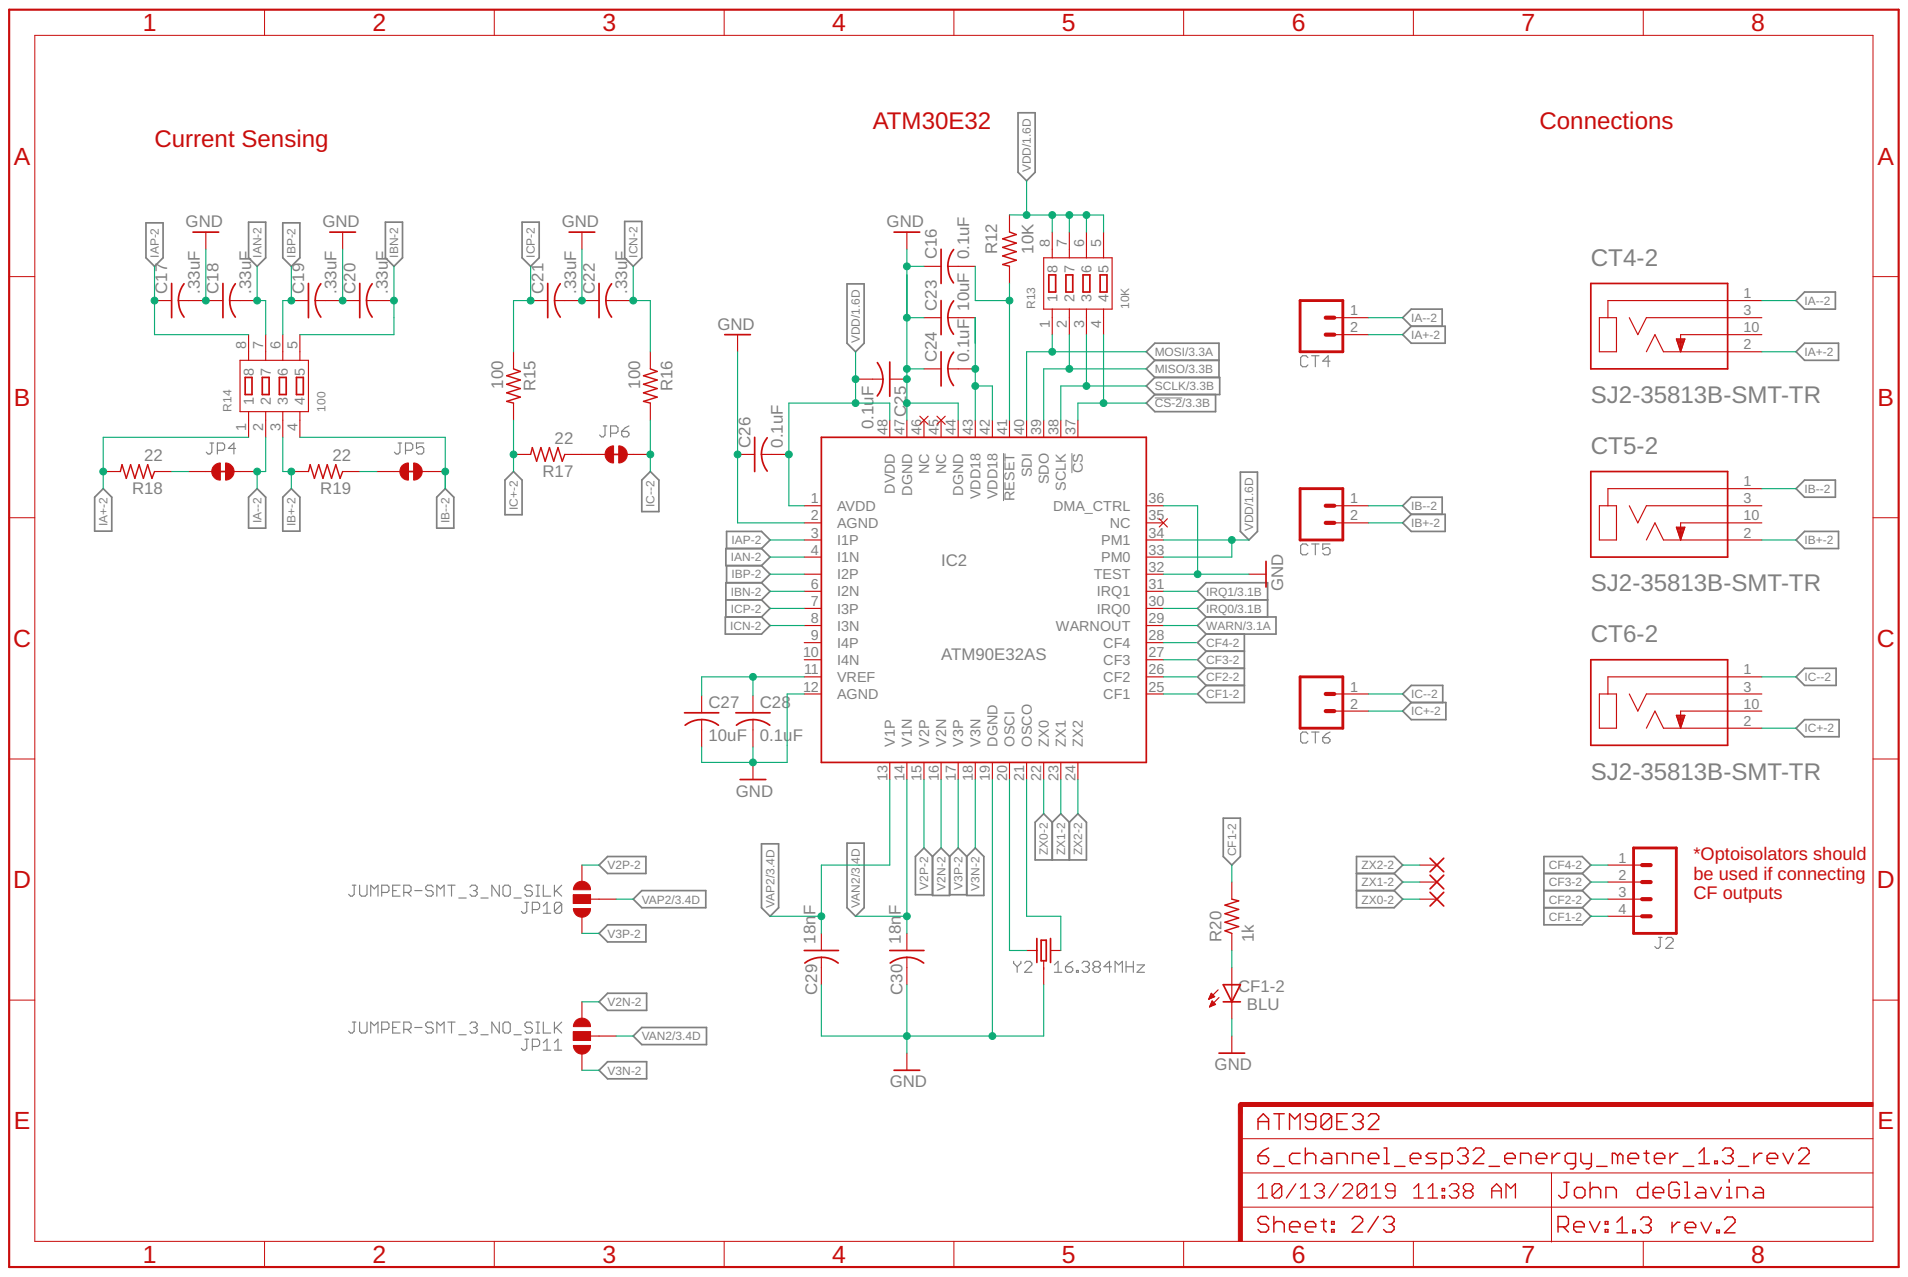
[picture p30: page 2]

*Optoisolators should
be used if connecting
CF outputs

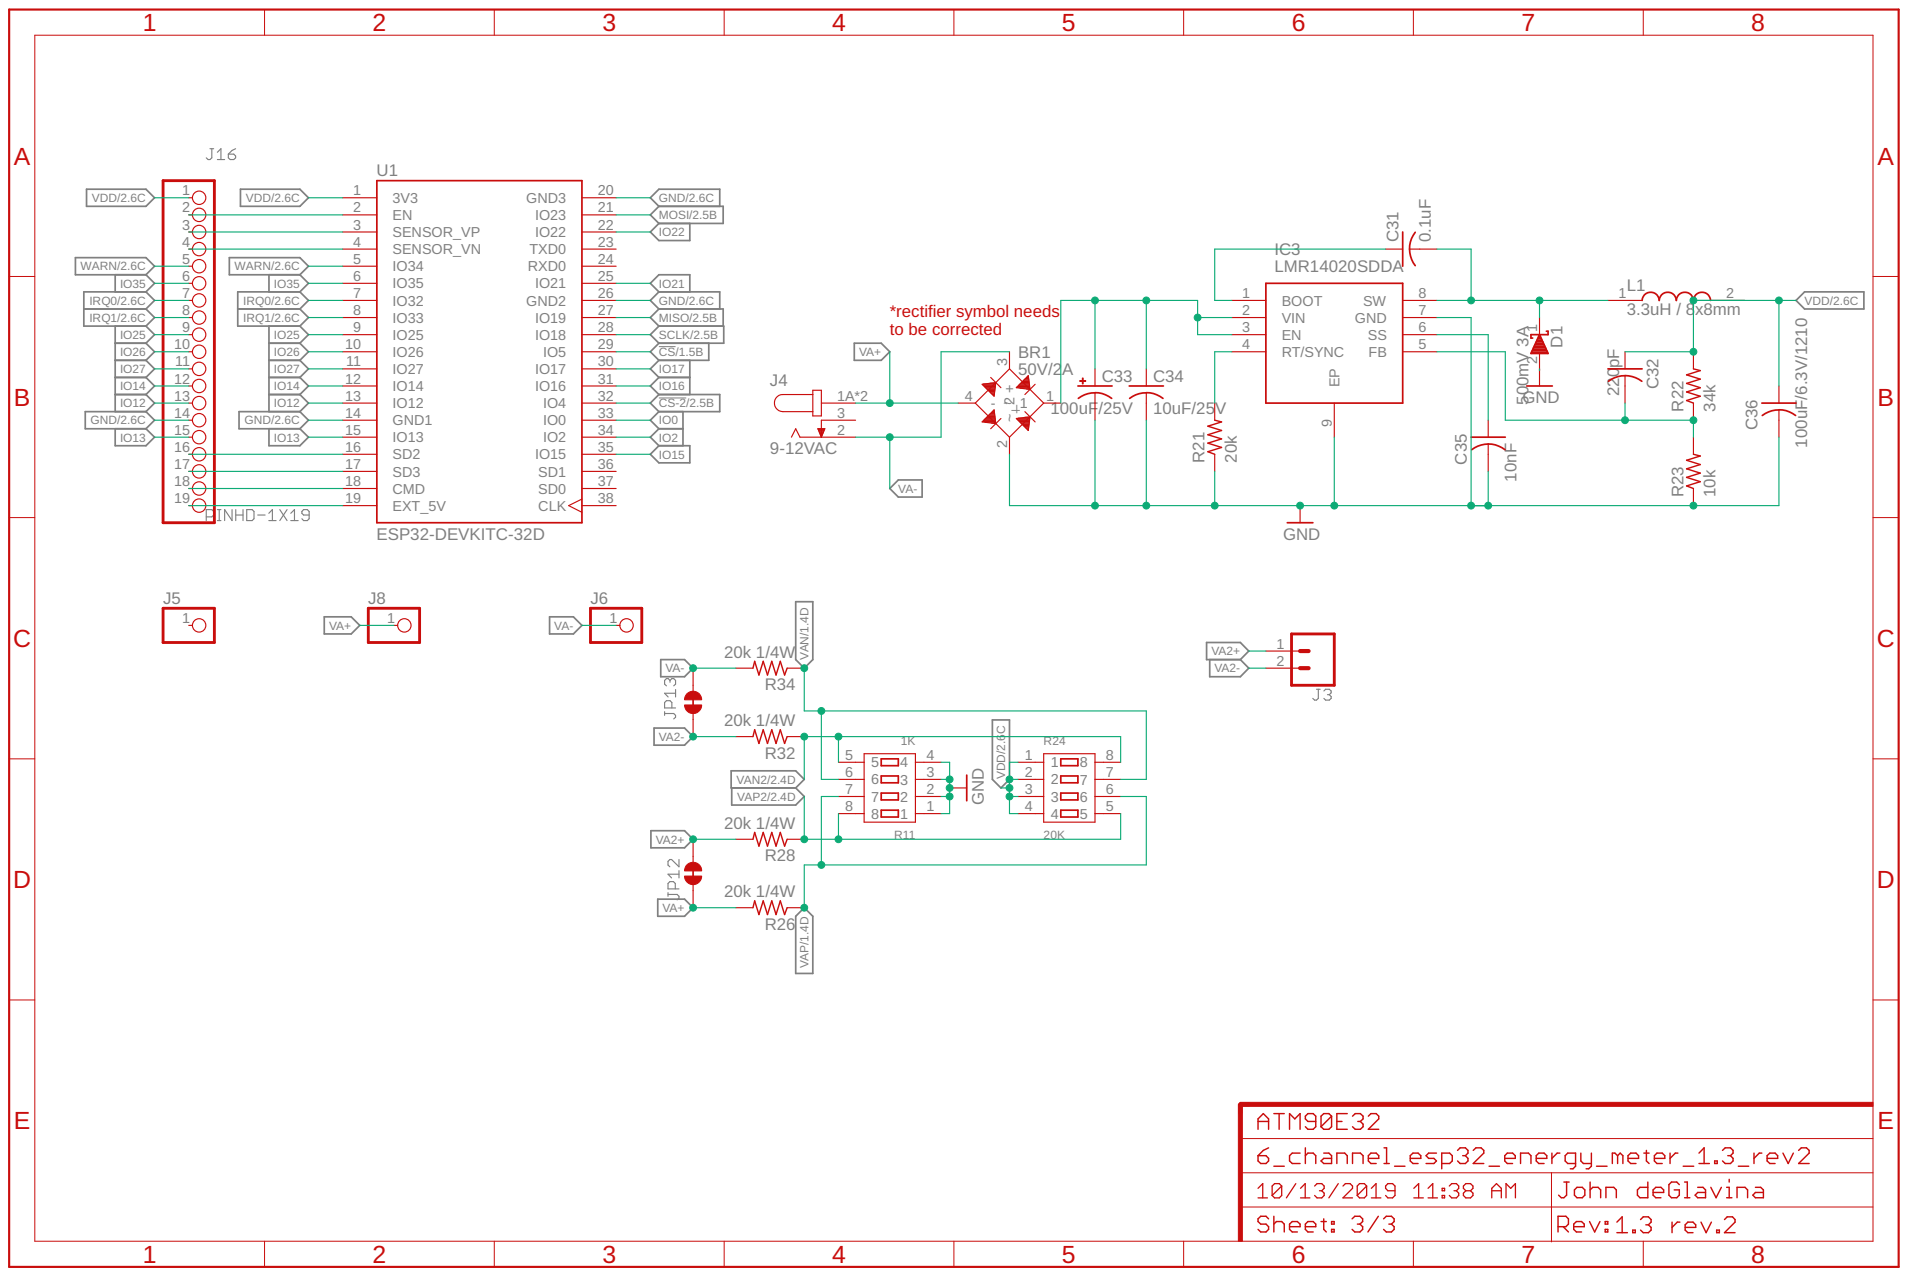
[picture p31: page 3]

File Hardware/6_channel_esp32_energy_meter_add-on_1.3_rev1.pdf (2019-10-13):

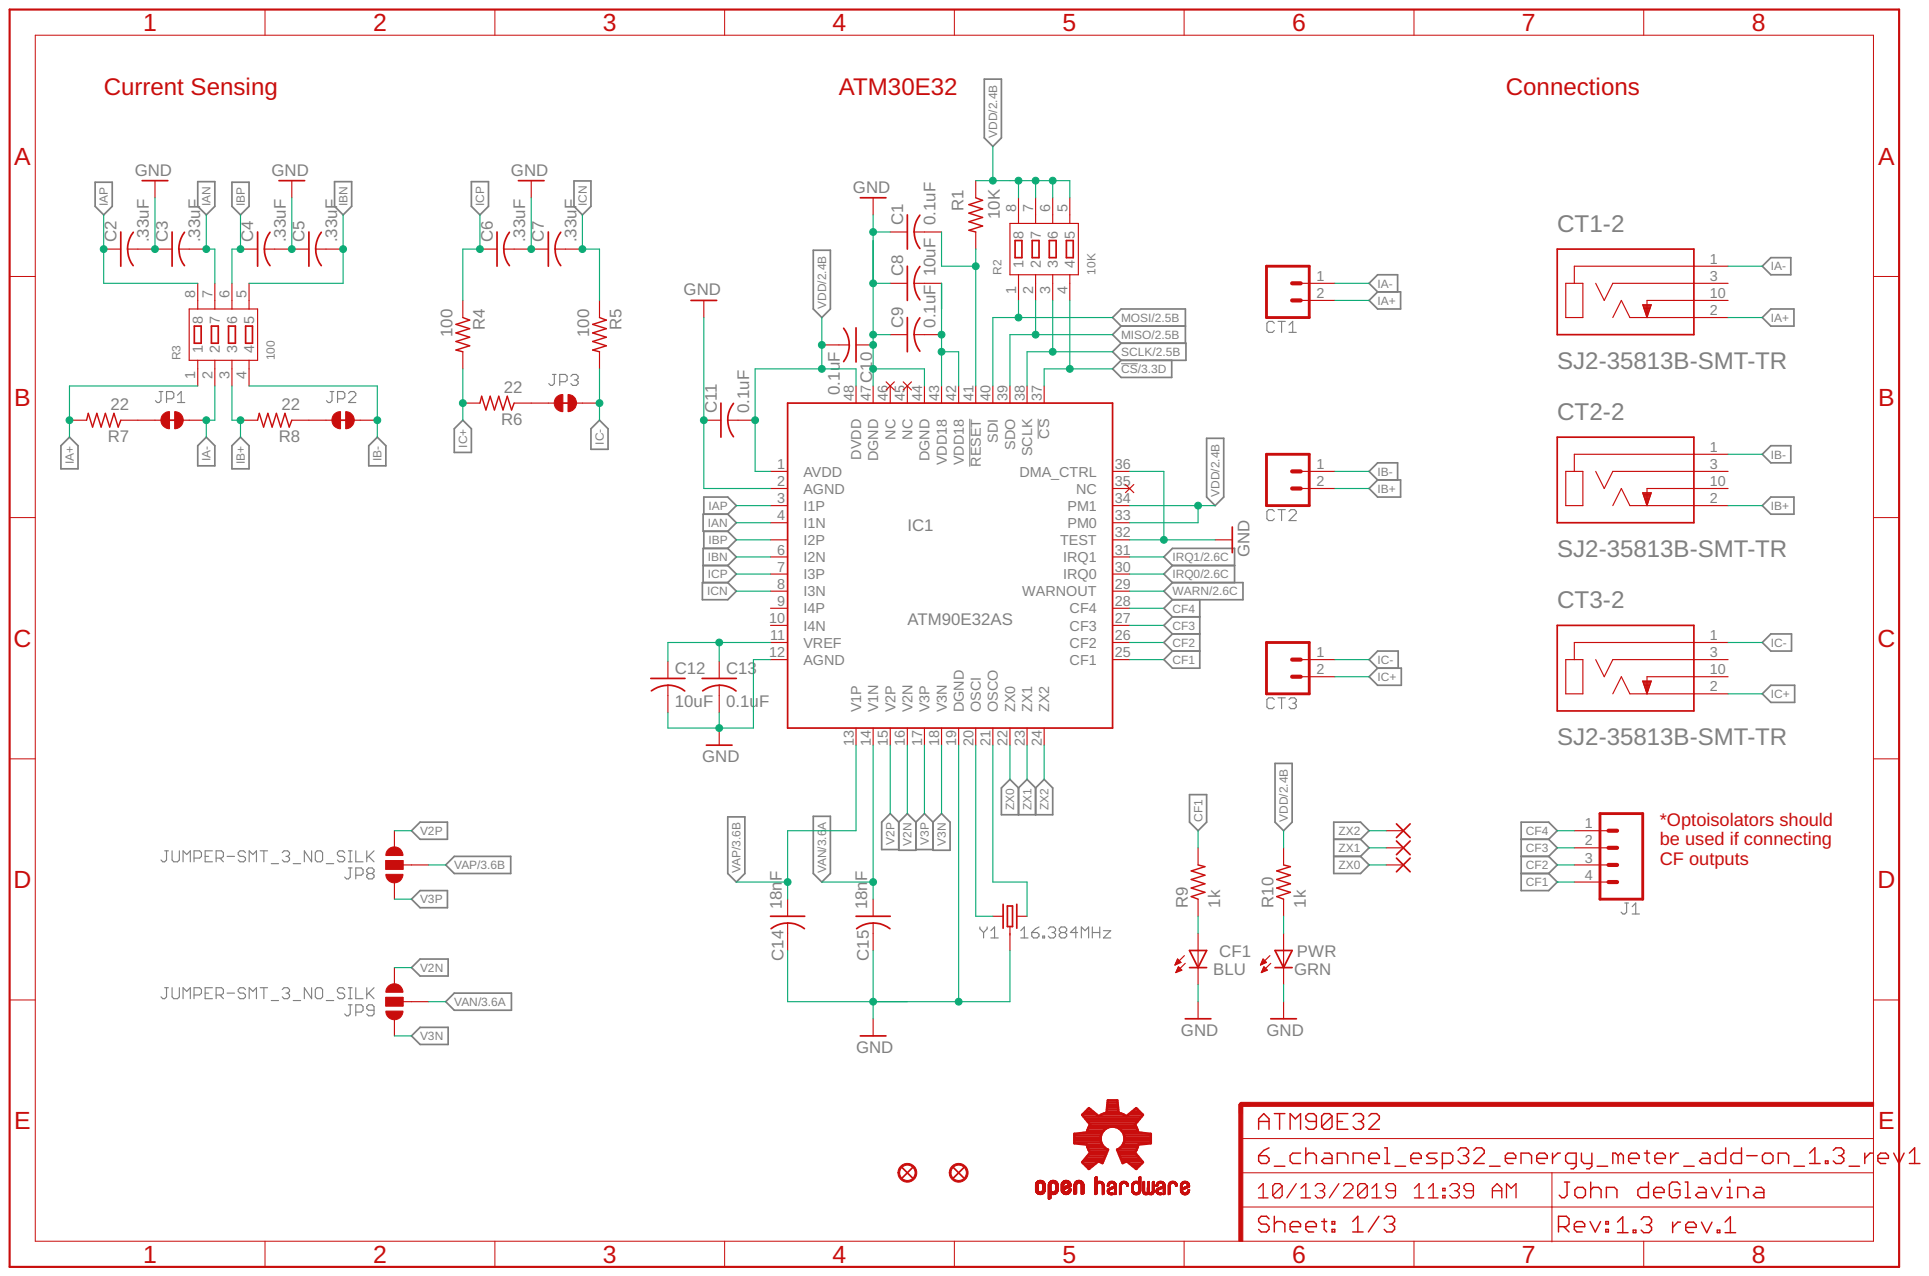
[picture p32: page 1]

*Optoisolators should
be used if connecting
CF outputs

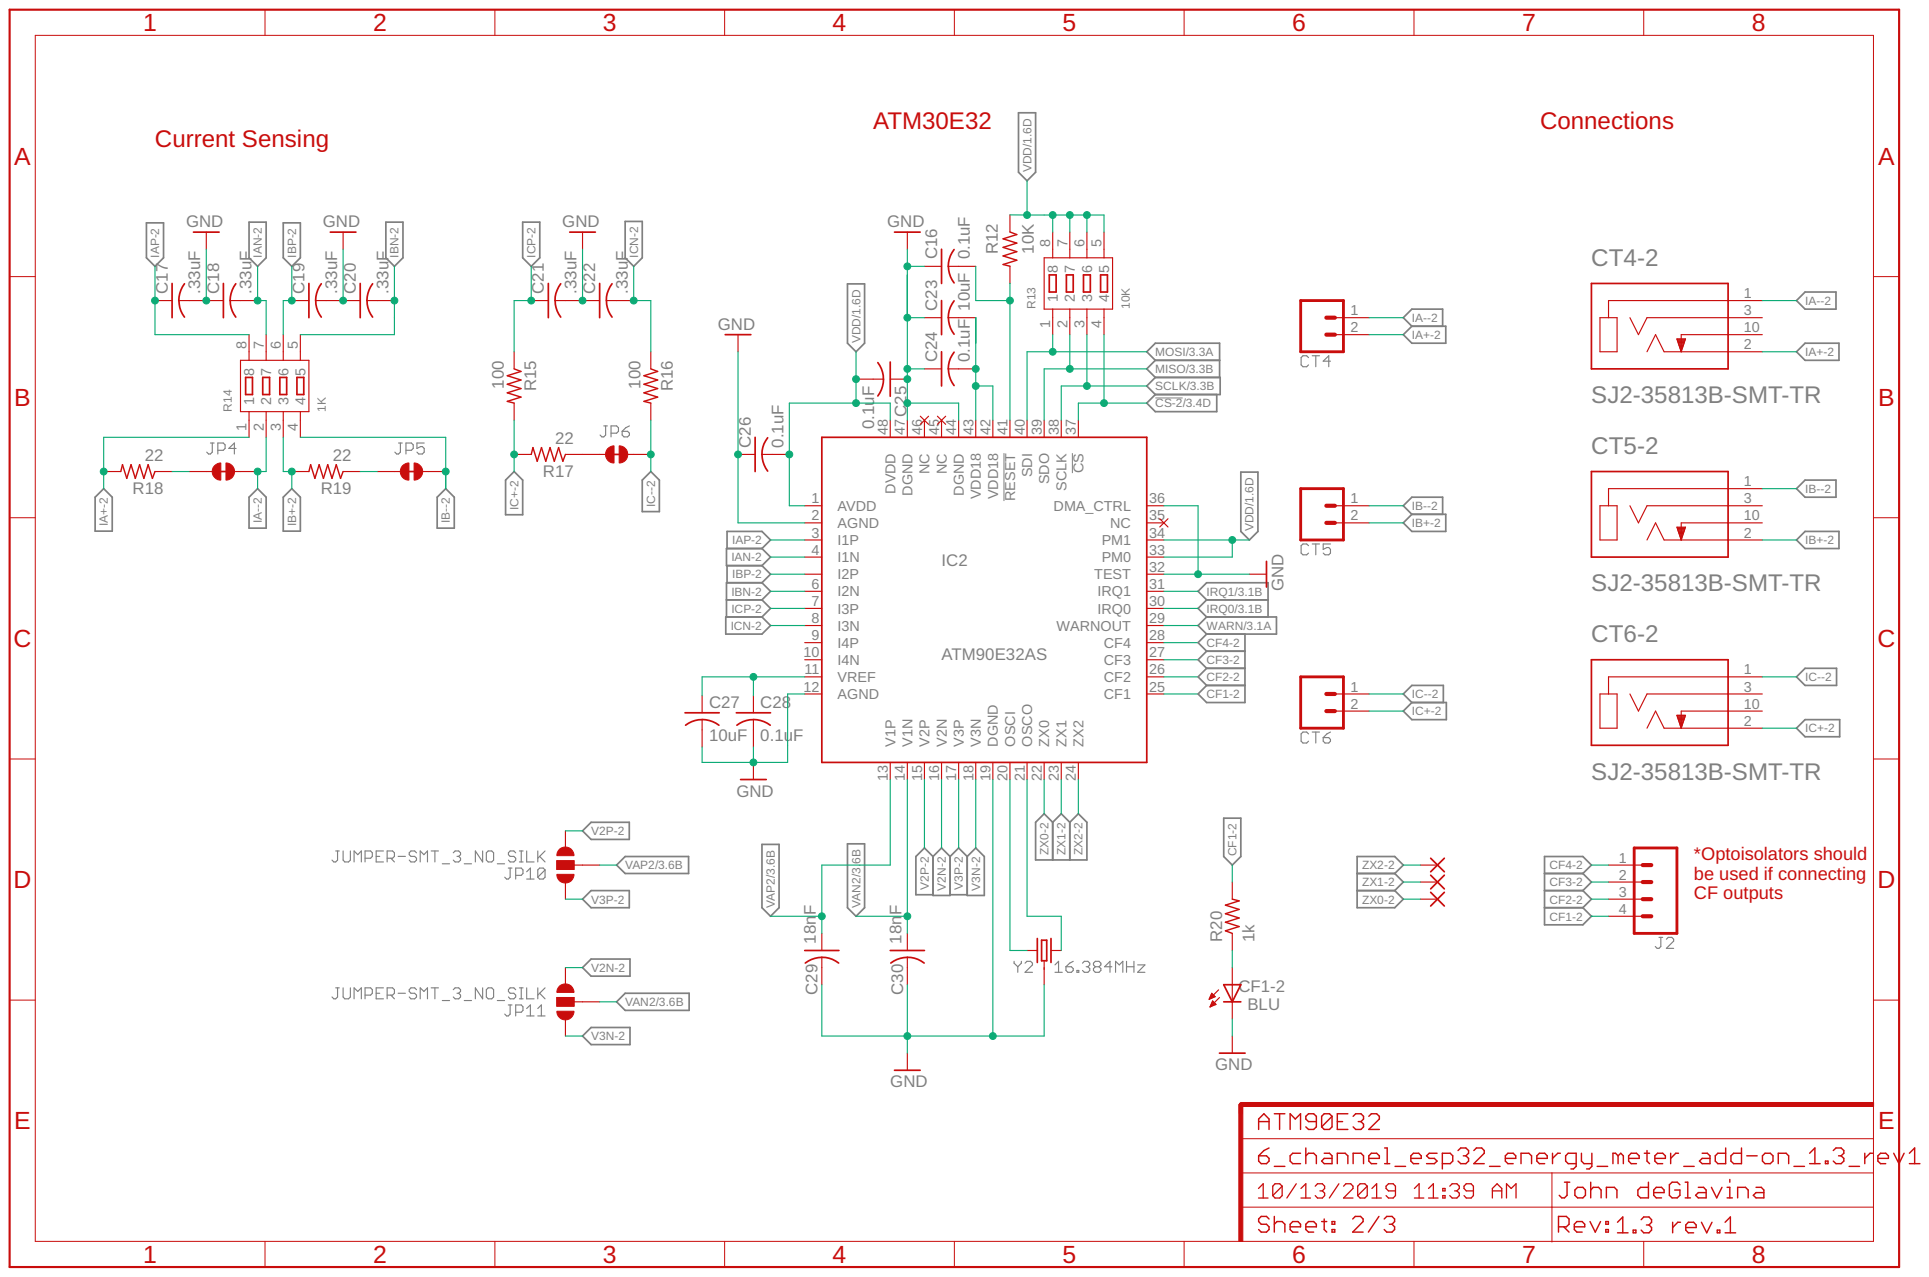
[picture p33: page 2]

*Optoisolators should
be used if connecting
CF outputs

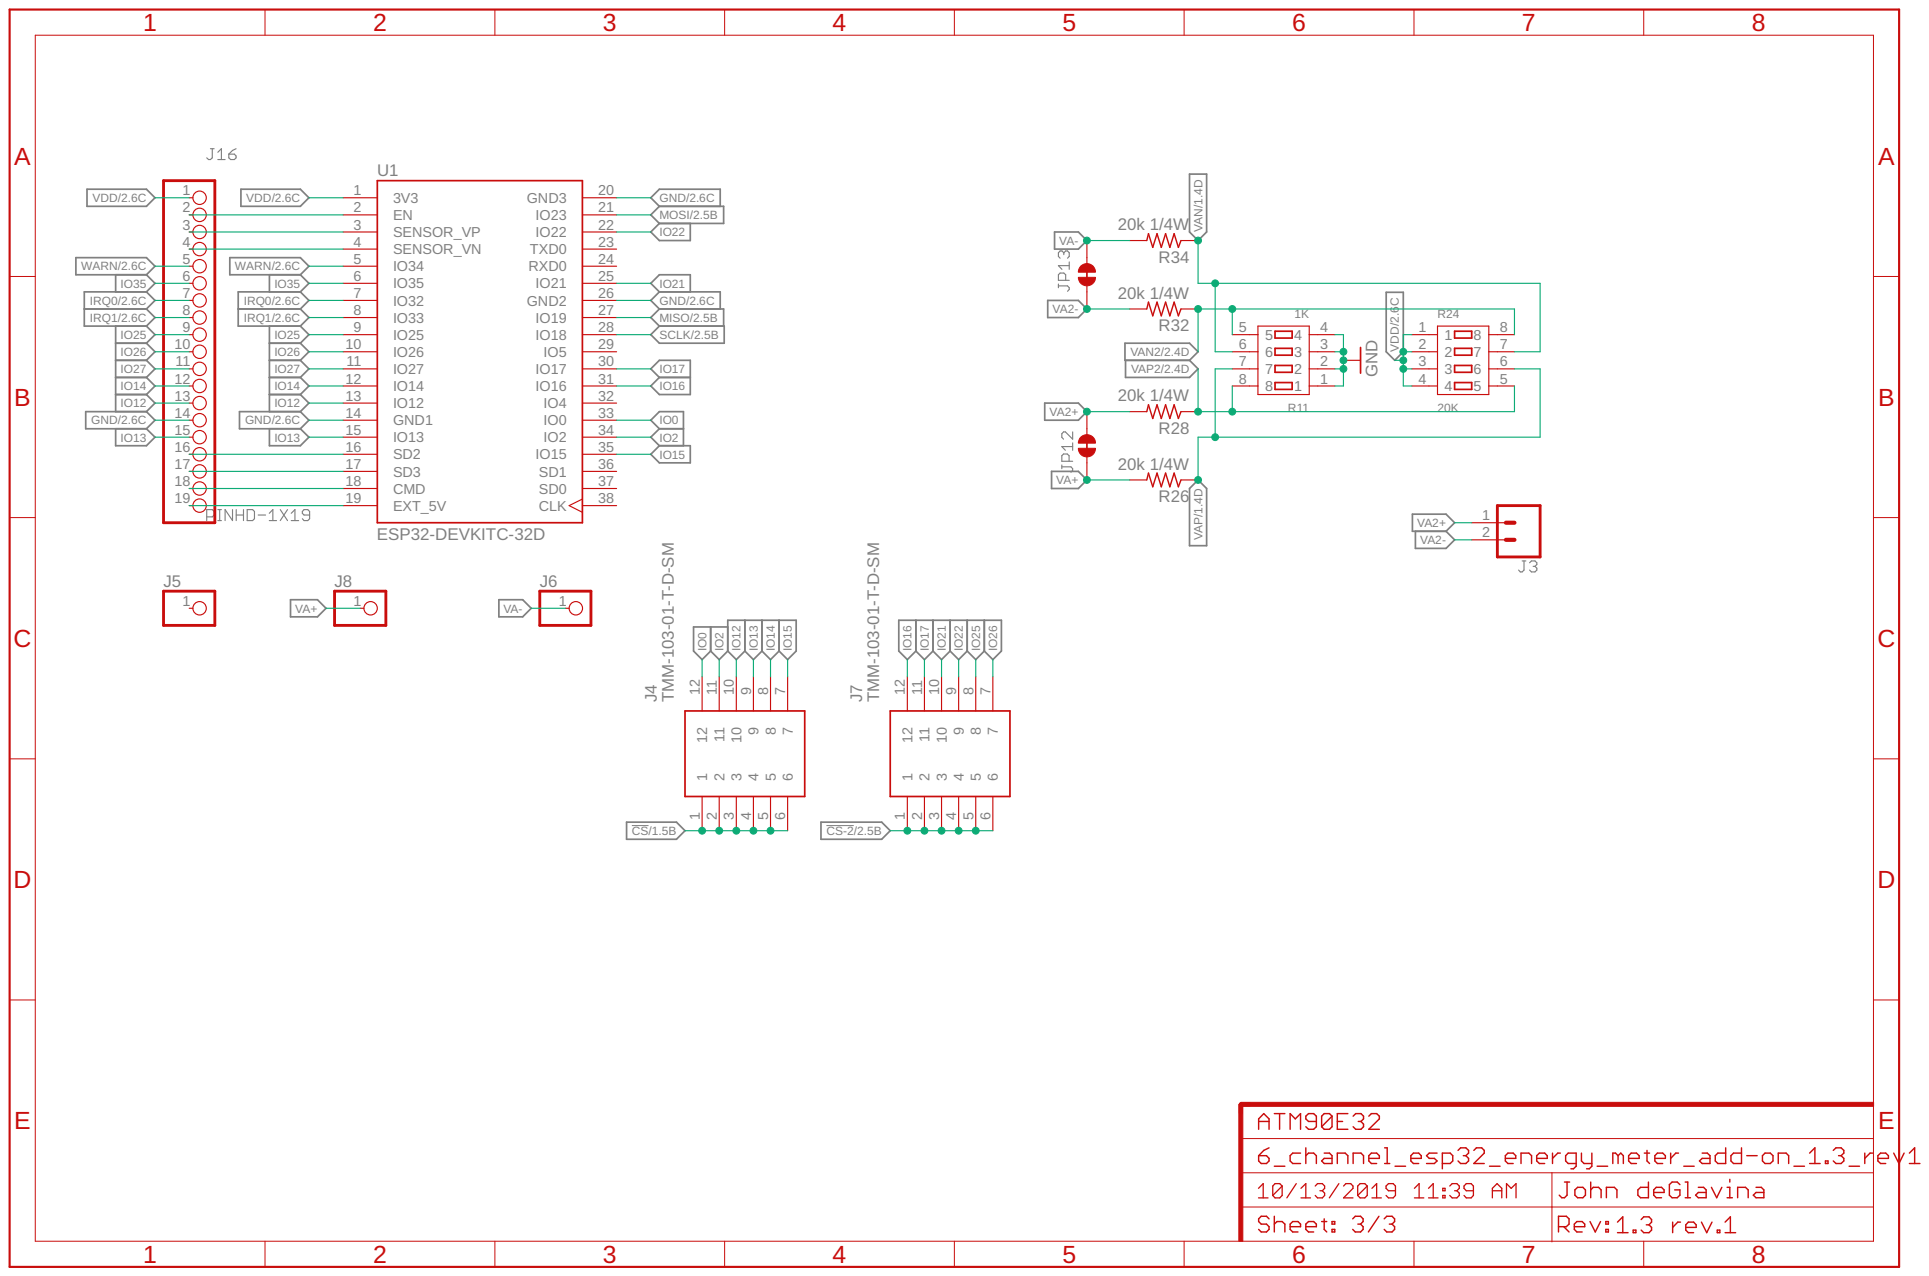
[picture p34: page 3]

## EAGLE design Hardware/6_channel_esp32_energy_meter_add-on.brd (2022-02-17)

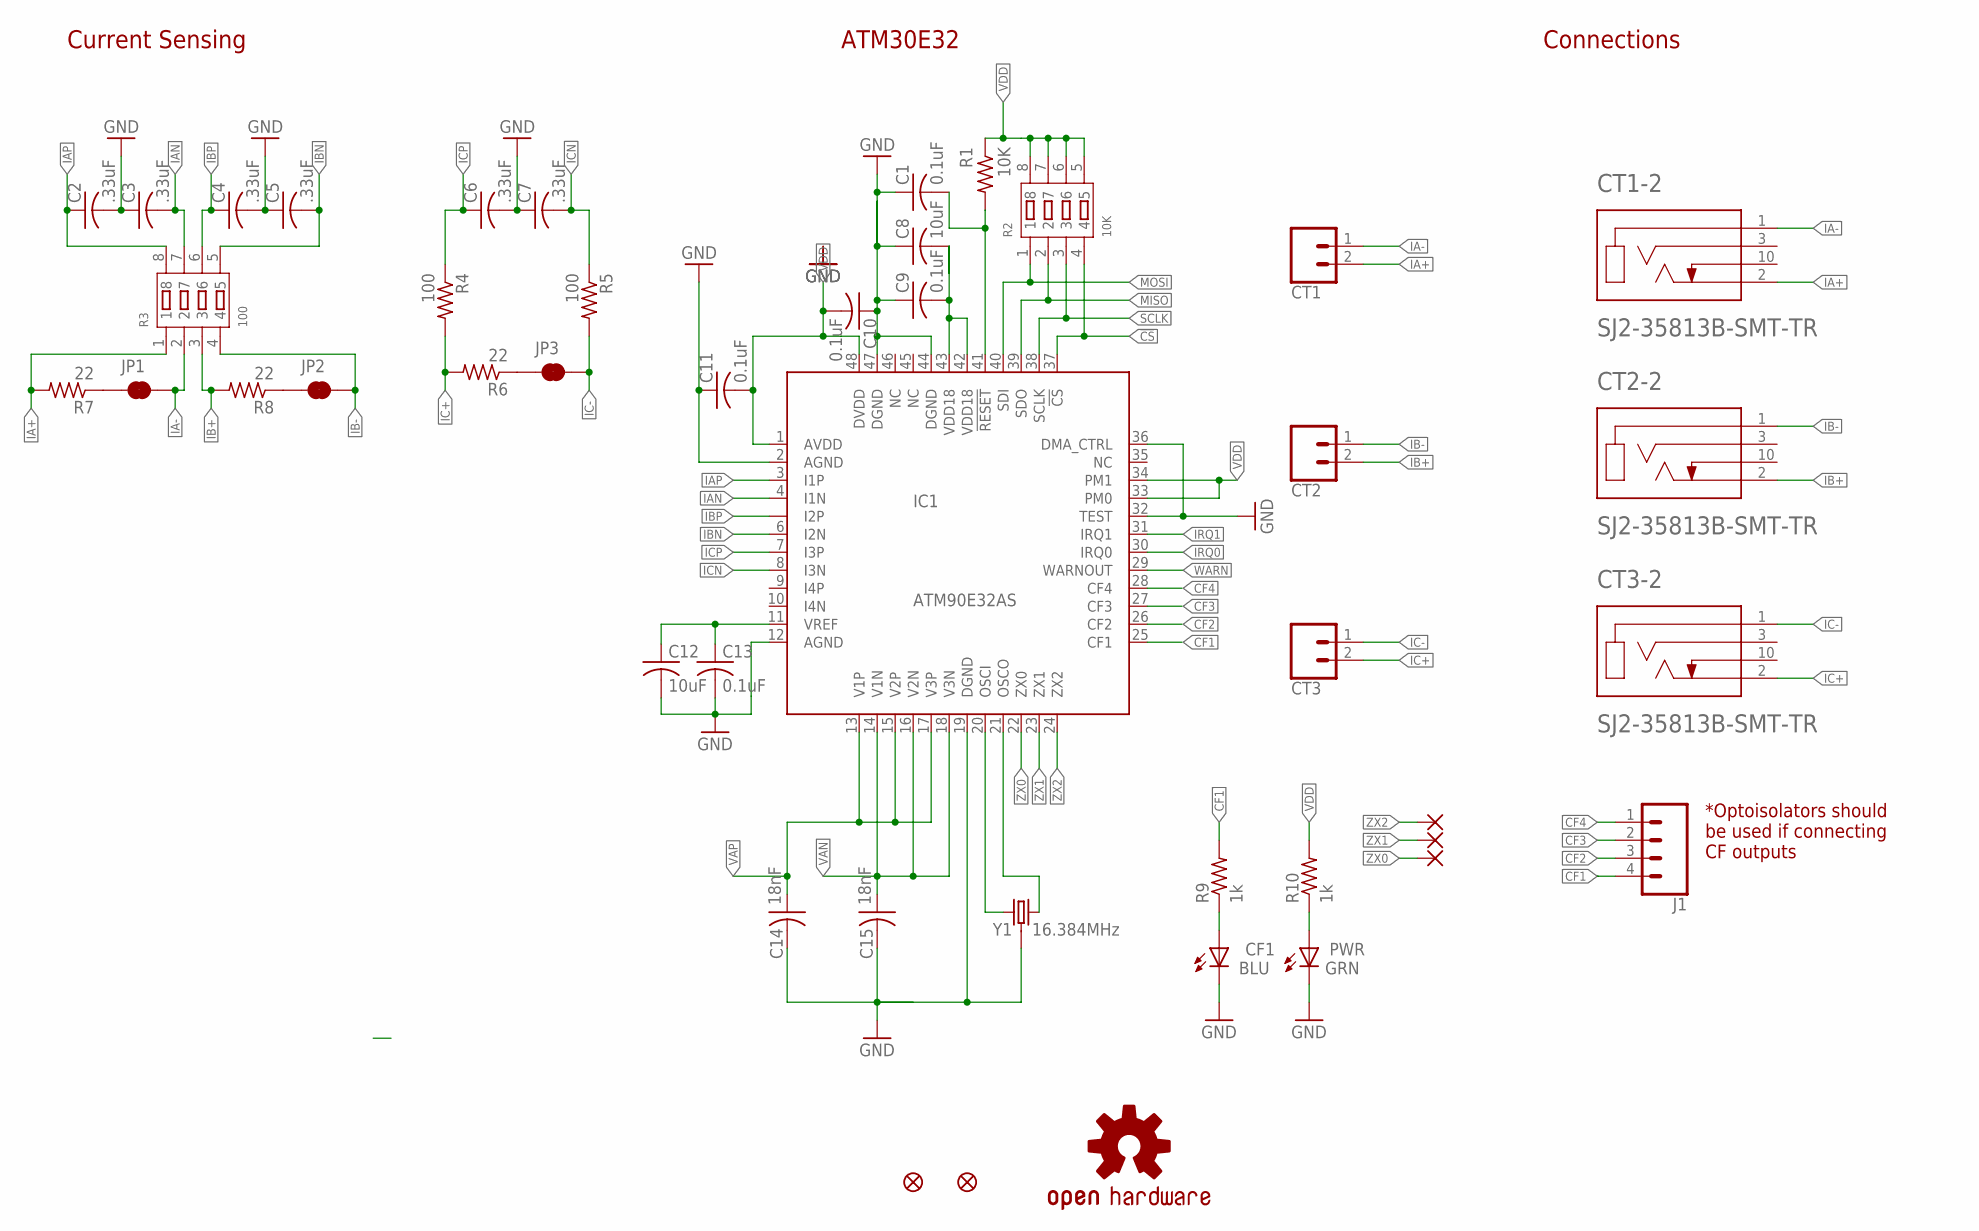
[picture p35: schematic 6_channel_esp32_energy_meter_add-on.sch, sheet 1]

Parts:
C1, C9, C10, C11, C13: 0.1uF; C0603
C2, C3, C4, C5, C6, C7: .33uF; C0603
C8, C12: 10uF; C0603
C14, C15: 18nF; C0603
CF1: BLU; CHIPLED_0603
CT1, CT2, CT3: CONN_023.5MM; SCREWTERMINAL-3.5MM-2
CT1-2, CT2-2, CT3-2: SJ2-35813B-SMT-TR; CUI_SJ2-35813B-SMT-TR
FD1, FD2: FIDUCIALUFIDUCIAL; FIDUCIAL-MICRO
IC1: ATM90E32AS; QFP50P900X900X120-48
J1: CONN_04; 1X04
JP1, JP2, JP3: JUMPER-SMT_2_NC_TRACE_SILK; SMT-JUMPER_2_NC_TRACE_SILK
LOGO1: OSHW-LOGOS; OSHW-LOGO-S
PWR: GRN; CHIPLED_0603
R1: 10K; R0603
R2: 10K; RA1206-8
R3: 100; RA1206-8
R4, R5: 100; R0603
R6, R7, R8: 22; R0603
R9, R10: 1k; R0603
Y1: 16.384MHz; CRYSTAL-SMD-3.2X2.5MM
ZX0, ZX1, ZX2: WIREPADSMD1,27-254; SMD1,27-2,54

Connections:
!CS: IC1.37 (!CS), R2.4; also elsewhere on the board
!RESET: C1.2, IC1.41 (!RESET), R1.2
CF1: IC1.25 (CF1), J1.4, R9.2
CF2: IC1.26 (CF2), J1.3
CF3: IC1.27 (CF3), J1.2
CF4: IC1.28 (CF4), J1.1
GND: C1.1, C2.2, C3.1, C4.2, C5.1, C6.2, C7.1, C8.1, C9.1, C10.1, C11.1, C12.2, C13.2, C14.2, C15.2, CF1.C, IC1.2 (AGND), IC1.12 (AGND), IC1.19 (DGND), IC1.32 (TEST), IC1.36 (DMA_CTRL), IC1.44 (DGND), IC1.47 (DGND), PWR.C, Y1.2 (3), Y1.4 (3); also elsewhere on the board
IA+: CT1.2, CT1-2.2 (TIP), R3.1, R7.2; also elsewhere on the board
IA-: CT1.1, CT1-2.1 (SLEEVE), JP1.2, R3.2; also elsewhere on the board
IAN: C3.2, IC1.4 (I1N), R3.7
IAP: C2.1, IC1.3 (I1P), R3.8
IB+: CT2.2, CT2-2.2 (TIP), R3.3, R8.2; also elsewhere on the board
IB-: CT2.1, CT2-2.1 (SLEEVE), JP2.2, R3.4; also elsewhere on the board
IBN: C5.2, IC1.6 (I2N), R3.5
IBP: C4.1, IC1.5 (I2P), R3.6
IC+: CT3.2, CT3-2.2 (TIP), R4.2, R6.2; also elsewhere on the board
IC-: CT3.1, CT3-2.1 (SLEEVE), JP3.2, R5.2; also elsewhere on the board
ICN: C7.2, IC1.8 (I3N), R5.1
ICP: C6.1, IC1.7 (I3P), R4.1
IRQ0: IC1.30 (IRQ0); also elsewhere on the board
IRQ1: IC1.31 (IRQ1); also elsewhere on the board
MISO: IC1.39 (SDO), R2.2; also elsewhere on the board
MOSI: IC1.40 (SDI), R2.1; also elsewhere on the board
unnamed: JP1.1, R7.1
unnamed: JP2.1, R8.1
unnamed: CF1.A, R9.1
unnamed: JP3.1, R6.1
unnamed: PWR.A, R10.1
OSCI: IC1.20 (OSCI), Y1.1
OSCO: IC1.21 (OSCO), Y1.3 (2)
SCLK: IC1.38 (SCLK), R2.3; also elsewhere on the board
VAN: C15.1, IC1.14 (V1N), IC1.16 (V2N), IC1.18 (V3N); also elsewhere on the board
VAP: C14.1, IC1.13 (V1P), IC1.15 (V2P), IC1.17 (V3P); also elsewhere on the board
VDD: C10.2, C11.2, IC1.1 (AVDD), IC1.33 (PM0), IC1.34 (PM1), IC1.48 (DVDD), R1.1, R2.5, R2.6, R2.7, R2.8, R10.2; also elsewhere on the board
VDD18: C8.2, C9.2, IC1.42 (VDD18), IC1.43 (VDD18)
VREF: C12.1, C13.1, IC1.11 (VREF)
WARN: IC1.29 (WARNOUT); also elsewhere on the board
ZX0: IC1.22 (ZX0), ZX0.1
ZX1: IC1.23 (ZX1), ZX1.1
ZX2: IC1.24 (ZX2), ZX2.1

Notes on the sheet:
ATM30E32
Connections
*Optoisolators should be used if connecting CF outputs
Current Sensing

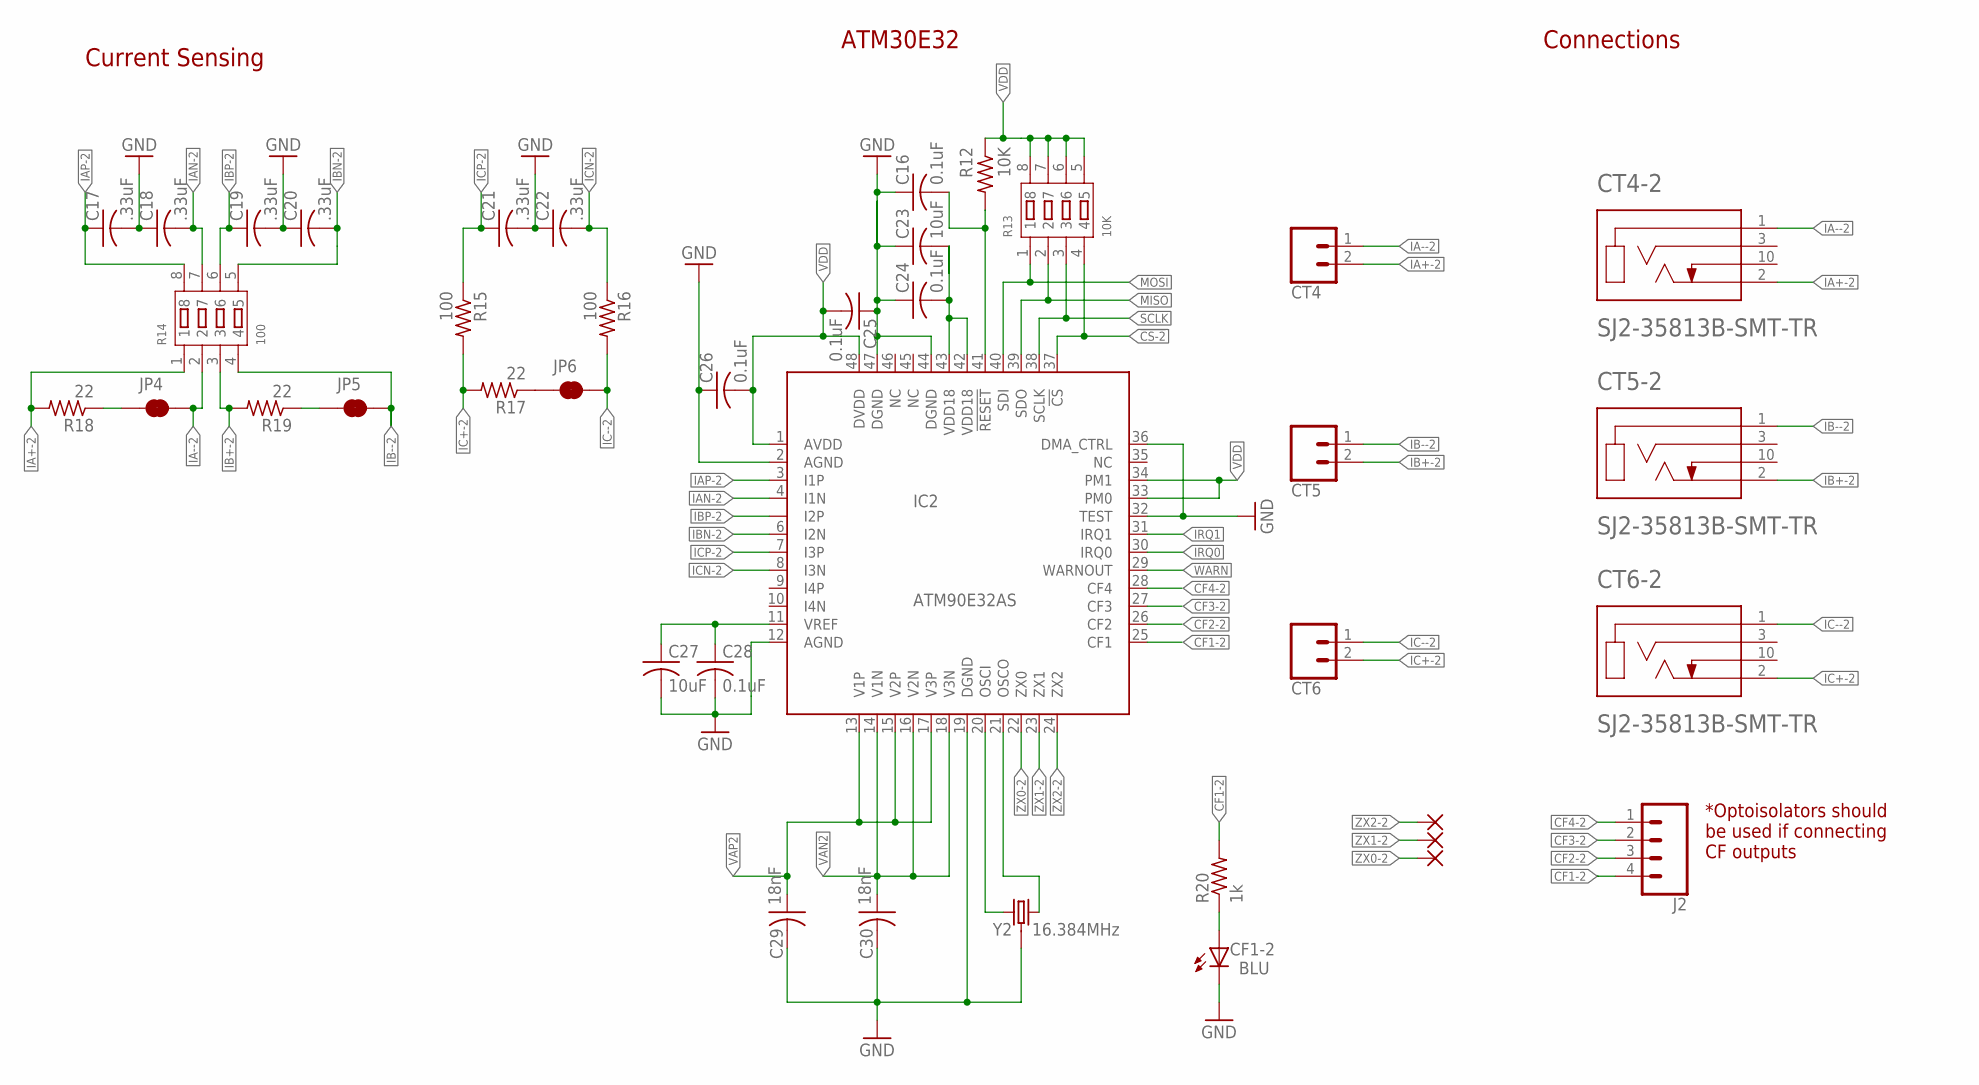
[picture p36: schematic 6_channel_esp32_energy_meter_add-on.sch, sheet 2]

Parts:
C16, C24, C25, C26, C28: 0.1uF; C0603
C17, C18, C19, C20, C21, C22: .33uF; C0603
C23, C27: 10uF; C0603
C29, C30: 18nF; C0603
CF1-2: BLU; CHIPLED_0603
CT4, CT5, CT6: CONN_023.5MM; SCREWTERMINAL-3.5MM-2
CT4-2, CT5-2, CT6-2: SJ2-35813B-SMT-TR; CUI_SJ2-35813B-SMT-TR
IC2: ATM90E32AS; QFP50P900X900X120-48
J2: CONN_04; 1X04
JP4, JP5, JP6: JUMPER-SMT_2_NC_TRACE_SILK; SMT-JUMPER_2_NC_TRACE_SILK
R12: 10K; R0603
R13: 10K; RA1206-8
R14: 100; RA1206-8
R15, R16: 100; R0603
R17, R18, R19: 22; R0603
R20: 1k; R0603
Y2: 16.384MHz; CRYSTAL-SMD-3.2X2.5MM
ZX0-2, ZX1-2, ZX2-2: WIREPADSMD1,27-254; SMD1,27-2,54

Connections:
!CS-2: IC2.37 (!CS), R13.4; also elsewhere on the board
!RESET2: C16.2, IC2.41 (!RESET), R12.2
CF1-2: IC2.25 (CF1), J2.4, R20.2
CF2-2: IC2.26 (CF2), J2.3
CF3-2: IC2.27 (CF3), J2.2
CF4-2: IC2.28 (CF4), J2.1
GND: C16.1, C17.2, C18.1, C19.2, C20.1, C21.2, C22.1, C23.1, C24.1, C25.1, C26.1, C27.2, C28.2, C29.2, C30.2, CF1-2.C, IC2.2 (AGND), IC2.12 (AGND), IC2.19 (DGND), IC2.32 (TEST), IC2.36 (DMA_CTRL), IC2.44 (DGND), IC2.47 (DGND), Y2.2 (3), Y2.4 (3); also elsewhere on the board
IA+-2: CT4.2, CT4-2.2 (TIP), R14.1, R18.2; also elsewhere on the board
IA--2: CT4.1, CT4-2.1 (SLEEVE), JP4.2, R14.2; also elsewhere on the board
IAN-2: C18.2, IC2.4 (I1N), R14.7
IAP-2: C17.1, IC2.3 (I1P), R14.8
IB+-2: CT5.2, CT5-2.2 (TIP), R14.3, R19.2; also elsewhere on the board
IB--2: CT5.1, CT5-2.1 (SLEEVE), JP5.2, R14.4; also elsewhere on the board
IBN-2: C20.2, IC2.6 (I2N), R14.5
IBP-2: C19.1, IC2.5 (I2P), R14.6
IC+-2: CT6.2, CT6-2.2 (TIP), R15.2, R17.2; also elsewhere on the board
IC--2: CT6.1, CT6-2.1 (SLEEVE), JP6.2, R16.2; also elsewhere on the board
ICN-2: C22.2, IC2.8 (I3N), R16.1
ICP-2: C21.1, IC2.7 (I3P), R15.1
IRQ0: IC2.30 (IRQ0); also elsewhere on the board
IRQ1: IC2.31 (IRQ1); also elsewhere on the board
MISO: IC2.39 (SDO), R13.2; also elsewhere on the board
MOSI: IC2.40 (SDI), R13.1; also elsewhere on the board
unnamed: JP4.1, R18.1
unnamed: JP5.1, R19.1
unnamed: JP6.1, R17.1
unnamed: CF1-2.A, R20.1
OSCI2: IC2.20 (OSCI), Y2.1
OSCO2: IC2.21 (OSCO), Y2.3 (2)
SCLK: IC2.38 (SCLK), R13.3; also elsewhere on the board
VAN2: C30.1, IC2.14 (V1N), IC2.16 (V2N), IC2.18 (V3N); also elsewhere on the board
VAP2: C29.1, IC2.13 (V1P), IC2.15 (V2P), IC2.17 (V3P); also elsewhere on the board
VDD: C25.2, C26.2, IC2.1 (AVDD), IC2.33 (PM0), IC2.34 (PM1), IC2.48 (DVDD), R12.1, R13.5, R13.6, R13.7, R13.8; also elsewhere on the board
VDD2: C23.2, C24.2, IC2.42 (VDD18), IC2.43 (VDD18)
VREF2: C27.1, C28.1, IC2.11 (VREF)
WARN: IC2.29 (WARNOUT); also elsewhere on the board
ZX0-2: IC2.22 (ZX0), ZX0-2.1
ZX1-2: IC2.23 (ZX1), ZX1-2.1
ZX2-2: IC2.24 (ZX2), ZX2-2.1

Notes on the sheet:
ATM30E32
Connections
*Optoisolators should be used if connecting CF outputs
Current Sensing

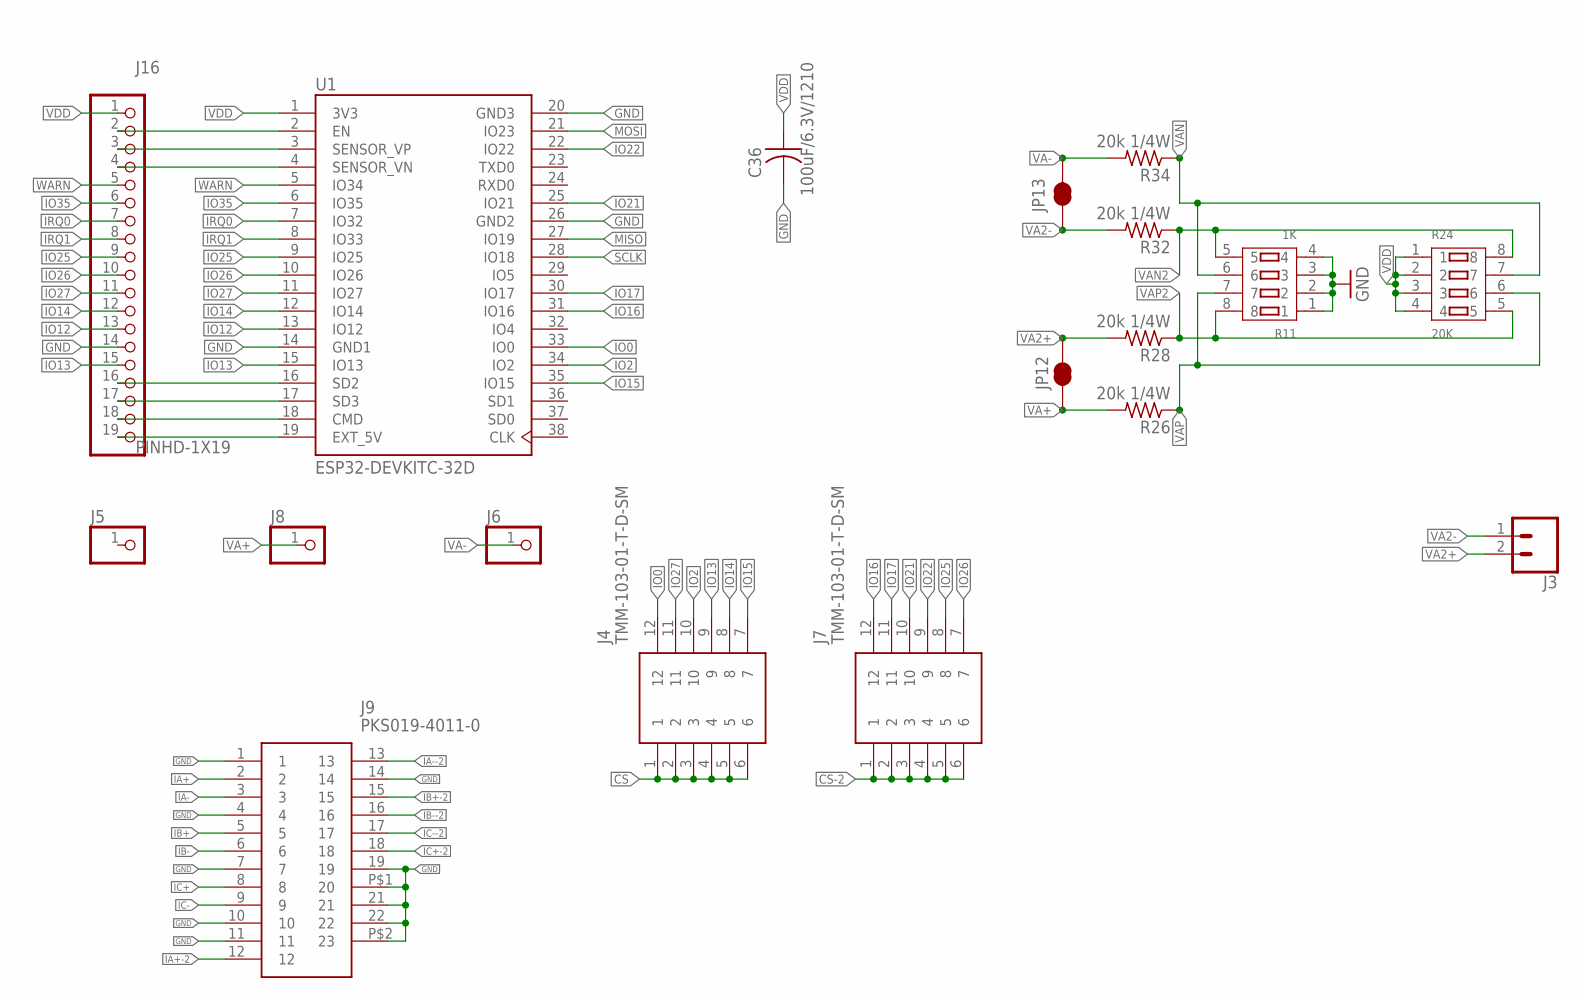
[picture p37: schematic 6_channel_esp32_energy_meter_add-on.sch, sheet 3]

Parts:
C36: 100uF/6.3V/1210; C1210
J3: CONN_023.5MM; SCREWTERMINAL-3.5MM-2
J4, J7: TMM-103-01-T-D-SM; SOP200P706X597-12N
J5, J6, J8: PINHD1X1-SM1X01_SM; 1X01-SM
J9: PKS019-4011-0; PKS01940110
J16: PINHD-1X19; 1X19
JP12, JP13: JUMPER-SMT_2_NC_TRACE_SILK; SMT-JUMPER_2_NC_TRACE_SILK
R11: 1K; RA1206-8
R24: 20K; RA1206-8
R26, R28, R32, R34: 20k 1/4W; R0603
U1: ESP32-DEVKITC-32D; MODULE_ESP32-DEVKITC-32D

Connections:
!CS: J4.1, J4.2, J4.3, J4.4, J4.5, J4.6; also elsewhere on the board
!CS-2: J7.1, J7.2, J7.3, J7.4, J7.5, J7.6; also elsewhere on the board
GND: C36.2, J9.1, J9.4, J9.7, J9.10, J9.11, J9.14, J9.19, J9.21, J9.22, J9.P$1 (20), J9.P$2 (23), J16.14, R11.1, R11.2, R11.3, R11.4, U1.14 (GND1), U1.20 (GND3), U1.26 (GND2); also elsewhere on the board
IA+: J9.2; also elsewhere on the board
IA+-2: J9.12; also elsewhere on the board
IA-: J9.3; also elsewhere on the board
IA--2: J9.13; also elsewhere on the board
IB+: J9.5; also elsewhere on the board
IB+-2: J9.15; also elsewhere on the board
IB-: J9.6; also elsewhere on the board
IB--2: J9.16; also elsewhere on the board
IC+: J9.8; also elsewhere on the board
IC+-2: J9.18; also elsewhere on the board
IC-: J9.9; also elsewhere on the board
IC--2: J9.17; also elsewhere on the board
IO0: J4.12, U1.33 (IO0)
IO2: J4.10, U1.34 (IO2)
IO12: J16.13, U1.13 (IO12)
IO13: J4.9, J16.15, U1.15 (IO13)
IO14: J4.8, J16.12, U1.12 (IO14)
IO15: J4.7, U1.35 (IO15)
IO16: J7.12, U1.31 (IO16)
IO17: J7.11, U1.30 (IO17)
IO21: J7.10, U1.25 (IO21)
IO22: J7.9, U1.22 (IO22)
IO25: J7.8, J16.9, U1.9 (IO25)
IO26: J7.7, J16.10, U1.10 (IO26)
IO27: J4.11, J16.11, U1.11 (IO27)
IO35: J16.6, U1.6 (IO35)
IRQ0: J16.7, U1.7 (IO32); also elsewhere on the board
IRQ1: J16.8, U1.8 (IO33); also elsewhere on the board
MISO: U1.27 (IO19); also elsewhere on the board
MOSI: U1.21 (IO23); also elsewhere on the board
unnamed: J16.2, U1.2 (EN)
unnamed: J16.3, U1.3 (SENSOR_VP)
unnamed: J16.4, U1.4 (SENSOR_VN)
unnamed: J16.16, U1.16 (SD2)
unnamed: J16.17, U1.17 (SD3)
unnamed: J16.18, U1.18 (CMD)
unnamed: J16.19, U1.19 (EXT_5V)
SCLK: U1.28 (IO18); also elsewhere on the board
VA2+: J3.2, JP12.1, R28.2
VA2-: J3.1, JP13.1, R32.2
VA+: J8.1, JP12.2, R26.2
VA-: J6.1, JP13.2, R34.2
VAN: R11.6, R24.7, R34.1; also elsewhere on the board
VAN2: R11.5, R24.8, R32.1; also elsewhere on the board
VAP: R11.7, R24.6, R26.1; also elsewhere on the board
VAP2: R11.8, R24.5, R28.1; also elsewhere on the board
VDD: C36.1, J16.1, R24.1, R24.2, R24.3, R24.4, U1.1 (3V3); also elsewhere on the board
WARN: J16.5, U1.5 (IO34); also elsewhere on the board

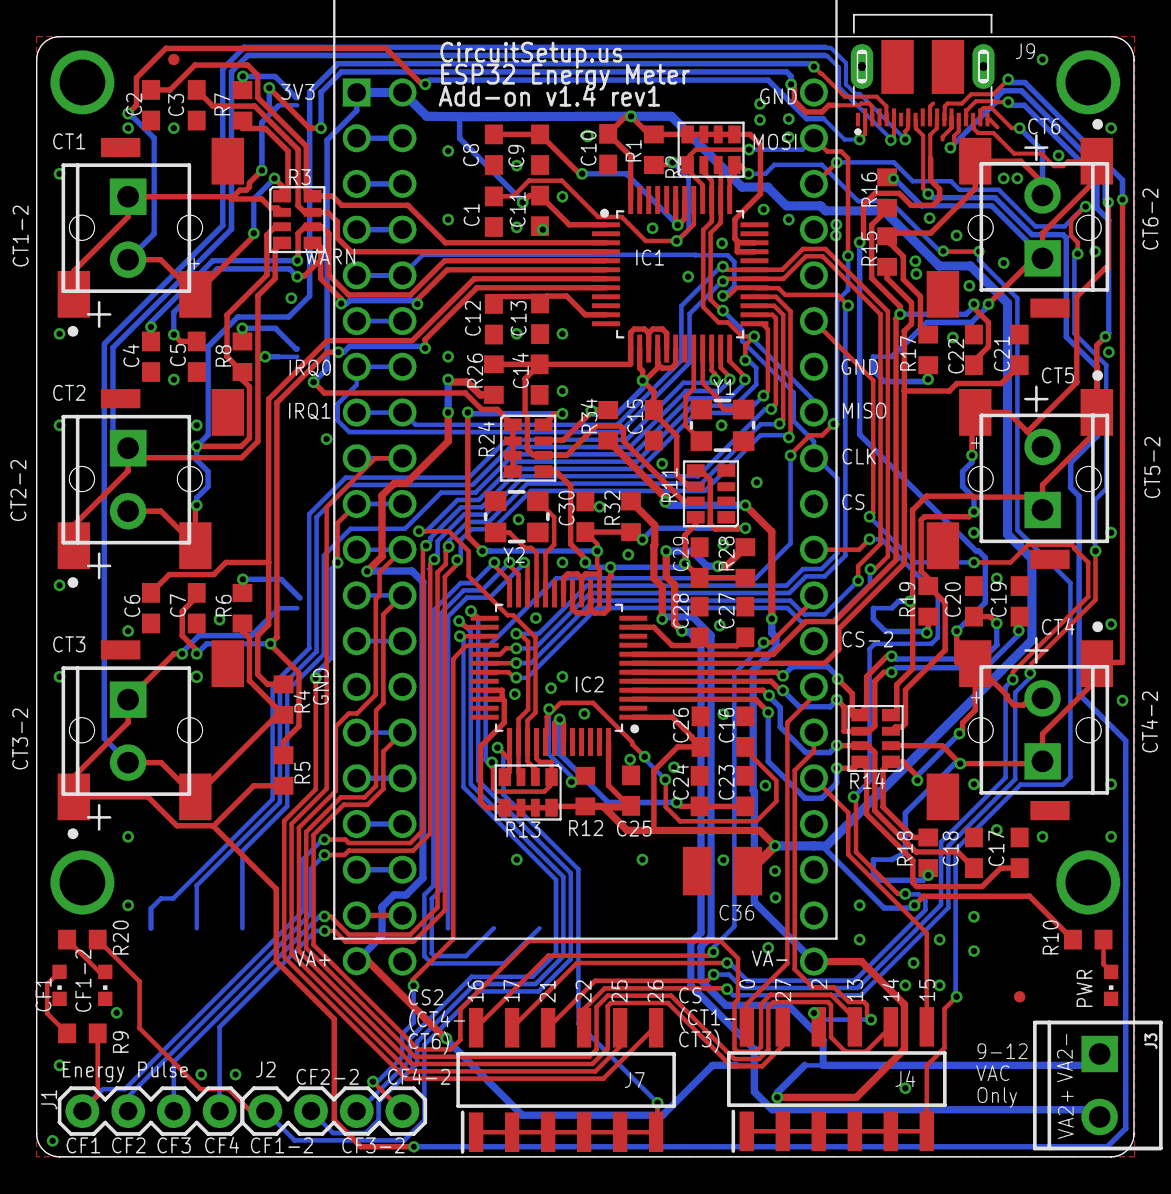
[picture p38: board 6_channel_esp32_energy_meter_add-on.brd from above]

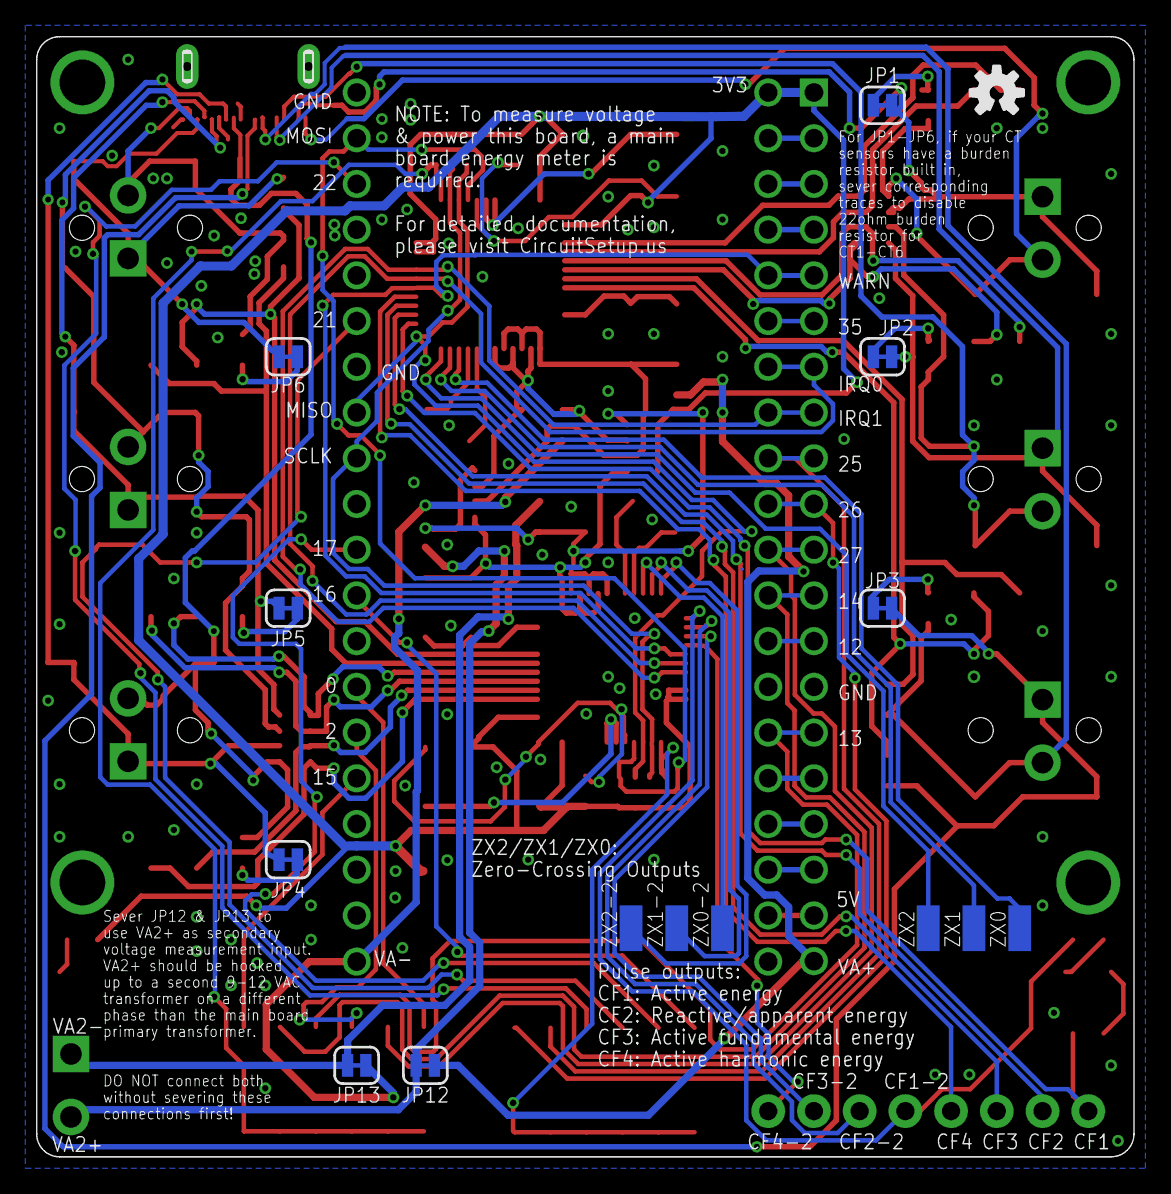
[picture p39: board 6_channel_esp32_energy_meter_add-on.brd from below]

Board: 2 copper layers, 61.0 x 62.2 mm, 103 parts (15 on the bottom side), 96 nets.

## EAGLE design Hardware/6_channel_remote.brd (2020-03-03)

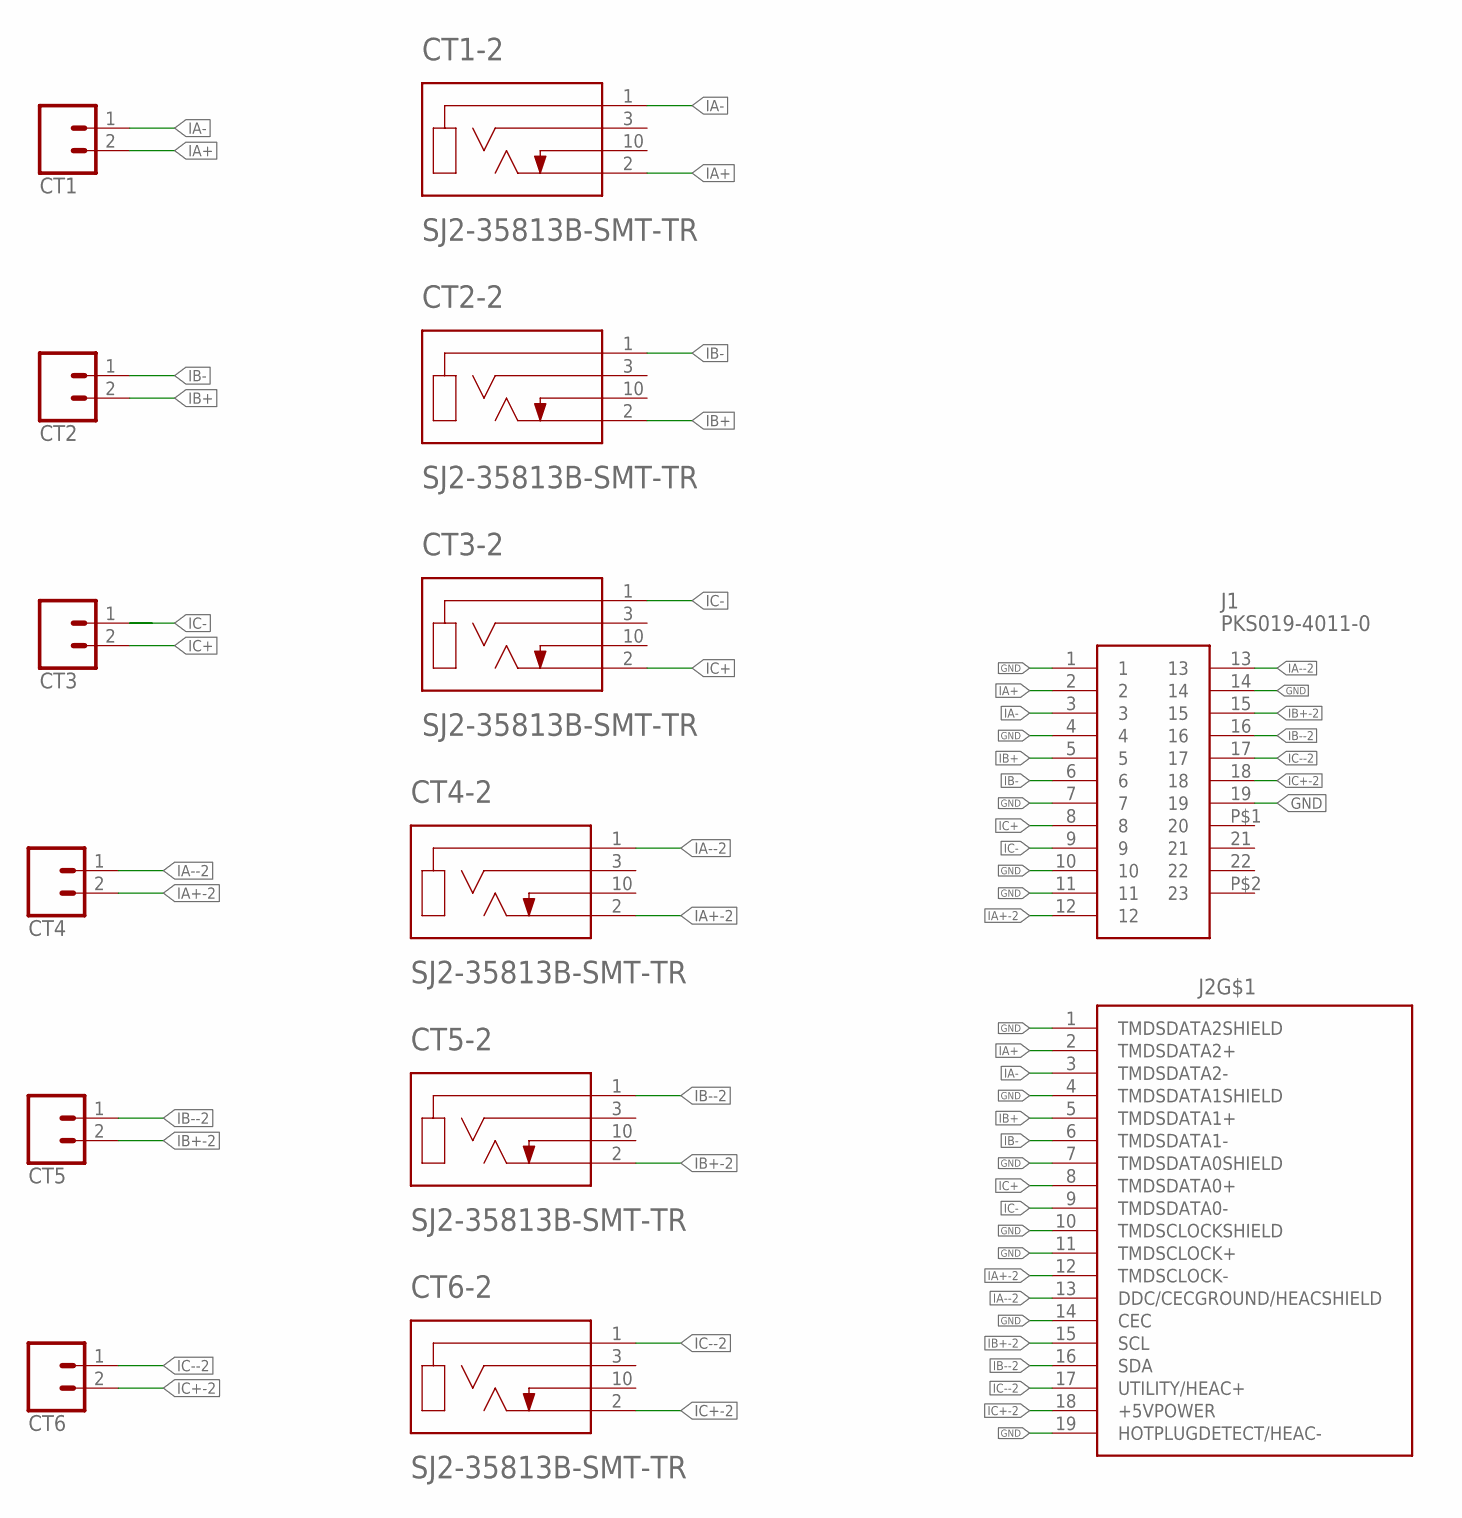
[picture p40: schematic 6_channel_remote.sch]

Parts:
CT1, CT2, CT3, CT4, CT5, CT6: CONN_023.5MM; SCREWTERMINAL-3.5MM-2
CT1-2, CT2-2, CT3-2, CT4-2, CT5-2, CT6-2: SJ2-35813B-SMT-TR; CUI_SJ2-35813B-SMT-TR
J1: PKS019-4011-0; PKS01940110
J2: 685119136923

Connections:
GND: J1.1, J1.4, J1.7, J1.10, J1.11, J1.14, J1.19, J2.1 (TMDSDATA2SHIELD), J2.4 (TMDSDATA1SHIELD), J2.7 (TMDSDATA0SHIELD), J2.10 (TMDSCLOCKSHIELD), J2.11 (TMDSCLOCK+), J2.14 (CEC), J2.19 (HOTPLUGDETECT/HEAC-)
IA+: CT1.2, CT1-2.2 (TIP), J1.2, J2.2 (TMDSDATA2+)
IA+-2: CT4.2, CT4-2.2 (TIP), J1.12, J2.12 (TMDSCLOCK-)
IA-: CT1.1, CT1-2.1 (SLEEVE), J1.3, J2.3 (TMDSDATA2-)
IA--2: CT4.1, CT4-2.1 (SLEEVE), J1.13, J2.13 (DDC/CECGROUND/HEACSHIELD)
IB+: CT2.2, CT2-2.2 (TIP), J1.5, J2.5 (TMDSDATA1+)
IB+-2: CT5.2, CT5-2.2 (TIP), J1.15, J2.15 (SCL)
IB-: CT2.1, CT2-2.1 (SLEEVE), J1.6, J2.6 (TMDSDATA1-)
IB--2: CT5.1, CT5-2.1 (SLEEVE), J1.16, J2.16 (SDA)
IC+: CT3.2, CT3-2.2 (TIP), J1.8, J2.8 (TMDSDATA0+)
IC+-2: CT6.2, CT6-2.2 (TIP), J1.18, J2.18 (+5VPOWER)
IC-: CT3.1, CT3-2.1 (SLEEVE), J1.9, J2.9 (TMDSDATA0-)
IC--2: CT6.1, CT6-2.1 (SLEEVE), J1.17, J2.17 (UTILITY/HEAC+)

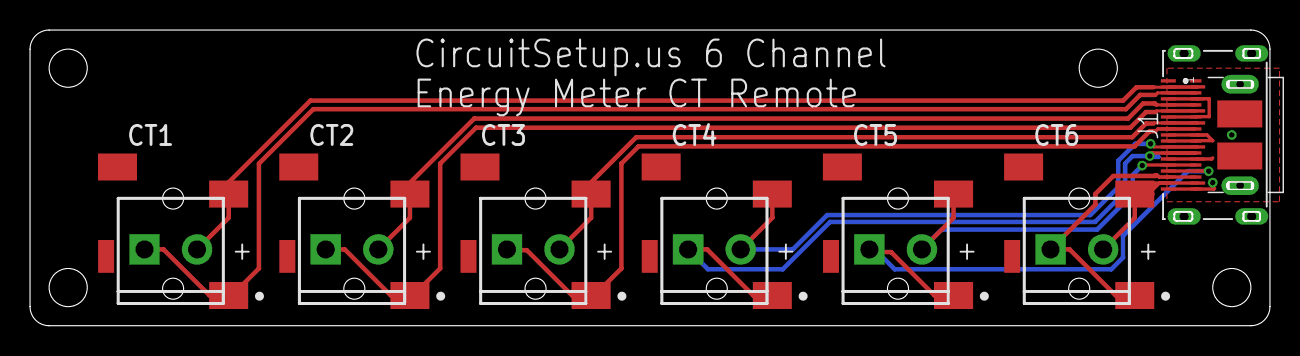
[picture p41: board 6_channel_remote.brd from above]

Board: 2 copper layers, 82.5 x 19.7 mm, 14 parts (0 on the bottom side), 13 nets.

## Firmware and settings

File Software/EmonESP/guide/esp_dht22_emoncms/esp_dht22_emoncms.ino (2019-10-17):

//simple sketch reading from DHT22 and posting up to emoncms.org using the ESP8266 wifi module.
// This file is part of OpenEnergyMonitor project.



#include <ESP8266WiFi.h>
#include "DHT.h"
#define DHTPIN 12    


#define DHTTYPE DHT22   // DHT 22  (AM2302), AM2321


DHT dht(DHTPIN, DHTTYPE);


const char* ssid     = "xxxxxxxxxxxxx"; //WIFI NAME
const char* password = "xxxxxxxxxxxxx"; //WIFI PASSWORD

const char* host = "emoncms.org";


void setup() {
  Serial.begin(9600);//Baud rate
  delay(10);

  

  Serial.println();
  Serial.println();
  Serial.print("Connecting to ");
  Serial.println(ssid);
  
  WiFi.begin(ssid, password);
  
  while (WiFi.status() != WL_CONNECTED) {
    delay(500);
    Serial.print(".");
  }

  Serial.println("");
  Serial.println("WiFi connected");  
  Serial.println("IP address: ");
  Serial.println(WiFi.localIP());

  
  dht.begin();
}

int value = 0;

void loop() {
  delay(2000);
  ++value;
//  DHT22_ERROR_t errorCode;


  
  Serial.print("Requesting data...");
//  errorCode = DHT.readData();
//  switch(errorCode)
  {
   

  float h = dht.readHumidity();
  // Read temperature as Celsius (the default)
  float t = dht.readTemperature();
  
  float f = dht.readTemperature(true);

  // Check if any reads failed and exit early (to try again).
  if (isnan(h) || isnan(t) || isnan(f)) {
    Serial.println("Failed to read from DHT sensor!");
    return;
  }
  Serial.print("connecting to ");
  Serial.println(host);
  
  // Use WiFiClient class to create TCP connections
  WiFiClient client;
  const int httpPort = 80;
  if (!client.connect(host, httpPort)) {
    Serial.println("connection failed");
    return;
  }
  
  // Compute heat index in Fahrenheit (the default)
  float hif = dht.computeHeatIndex(f, h);
  // Compute heat index in Celsius (isFahreheit = false)
  float hic = dht.computeHeatIndex(t, h, false);
  Serial.print("\n");
  Serial.print("Humidity: ");
  Serial.print(h);
  Serial.print(" %\n");
  Serial.print("Temperature: ");
  Serial.print(t);
  Serial.print(" *C\n ");

  // We now create a URI for the request
  String url = "/input/post.json?csv="+String(h)+","+String(t)+"&apikey=XXXXXXXXXXXXXXXXXXXXX"; //Enter api key here

  Serial.print("Requesting URL: ");
  Serial.println(url);
  
  // This will send the request to the server
  client.print(String("GET ") + url + " HTTP/1.1\r\n" +
               "Host: " + host + "\r\n" + 
               "Connection: close\r\n\r\n");
  unsigned long timeout = millis();
  while (client.available() == 0) {
    if (millis() - timeout > 5000) {
      Serial.println(">>> Client Timeout !");
      client.stop();
      return;
    }
  }
  
  // Read all the lines of the reply from server and print them to Serial
  while(client.available()){
    String line = client.readStringUntil('\r');
    Serial.print(line);
  }
  
  Serial.println();
  Serial.println("closing connection");
  }
}

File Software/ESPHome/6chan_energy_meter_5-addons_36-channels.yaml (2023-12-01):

# 5 add-on boards - 36 current channels
# ESPHome has a limit on the amount of sensors that it can handle before running out of memory. 
# Because of this, only the power sensor for each current channel is output

substitutions:
# Change the disp_name to something you want  
  disp_name: Energy_Meter
# Interval of how often the power is updated
  update_time: 10s
# Current Transformers:
#  20A/25mA SCT-006: 11143
#  30A/1V SCT-013-030: 8650
#  50A/1V SCT-013-050: 15420
#  50A/16.6mA SCT-010: 41334
#  80A/26.6mA SCT-010: 41660
#  100A/50ma SCT-013-000: 27518
#  120A/40mA: SCT-016: 41787
#  200A/100mA SCT-024: 27518
#  200A/50mA SCT-024: 55036
  current_cal: '11143'
# Jameco 9VAC Transformer: 
#  For meter versions: 
#  >= v1.3: 7305
#  <= v1.2: 42620
  voltage_cal: '7305'
  
esphome:
  name: energy_meter
  platform: ESP32
  board: nodemcu-32s

wifi:
  ssid: !secret wifi_ssid
  password: !secret wifi_pass

# Enable logging
logger:

# Enable Home Assistant API
api:

ota:

spi:
  clk_pin: 18
  miso_pin: 19
  mosi_pin: 23
sensor:
#IC1 Main
  - platform: atm90e32
    cs_pin: 5
    phase_a:
      voltage:
        name: ${disp_name} Volts A Main
        id: ic1Volts
        accuracy_decimals: 1
      current:
        name: ${disp_name} CT1 Amps
        id: ct1Amps
      power:
        name: ${disp_name} CT1 Watts 
        id: ct1Watts
      gain_voltage: ${voltage_cal}
      gain_ct: ${current_cal}
    phase_b:
      current:
        name: ${disp_name} CT2 Amps 
        id: ct2Amps
      power:
        name: ${disp_name} CT2 Watts 
        id: ct2Watts
      gain_voltage: ${voltage_cal}
      gain_ct: ${current_cal}
    phase_c:
      current:
        name: ${disp_name} CT3 Amps
        id: ct3Amps
      power:
        name: ${disp_name} CT3 Watts
        id: ct3Watts
      gain_voltage: ${voltage_cal}
      gain_ct: ${current_cal}
    frequency:
      name: ${disp_name} Freq A Main
    line_frequency: 60Hz
    gain_pga: 1X
    update_interval: ${update_time}
#IC2 Main
  - platform: atm90e32
    cs_pin: 4
    phase_a:
      current:
        name: ${disp_name} CT4 Amps 
        id: ct4Amps
      power:
        name: ${disp_name} CT4 Watts 
        id: ct4Watts
      gain_voltage: ${voltage_cal}
      gain_ct: ${current_cal}
    phase_b:
      current:
        name: ${disp_name} CT5 Amps 
        id: ct5Amps
      power:
        name: ${disp_name} CT5 Watts 
        id: ct5Watts
      gain_voltage: ${voltage_cal}
      gain_ct: ${current_cal}
    phase_c:
      current:
        name: ${disp_name} CT6 Amps 
        id: ct6Amps
      power:
        name: ${disp_name} CT6 Watts 
        id: ct6Watts
      gain_voltage: ${voltage_cal}
      gain_ct: ${current_cal}
    line_frequency: 60Hz
    gain_pga: 1X
    update_interval: ${update_time}
#IC1 AddOn 1
  - platform: atm90e32
    cs_pin: 0
    phase_a:
      power:
        name: ${disp_name} CT7 Watts
        id: ct7Watts
      gain_voltage: ${voltage_cal}
      gain_ct: ${current_cal}
    phase_b:
      power:
        name: ${disp_name} CT8 Watts
        id: ct8Watts
      gain_voltage: ${voltage_cal}
      gain_ct: ${current_cal}
    phase_c:
      power:
        name: ${disp_name} CT9 Watts
        id: ct9Watts
      gain_voltage: ${voltage_cal}
      gain_ct: ${current_cal}
    line_frequency: 60Hz
    gain_pga: 1X
    update_interval: ${update_time}
#IC2 AddOn 1
  - platform: atm90e32
    cs_pin: 16
    phase_a:
      power:
        name: ${disp_name} CT10 Watts
        id: ct10Watts
      gain_voltage: ${voltage_cal}
      gain_ct: ${current_cal}
    phase_b:
      power:
        name: ${disp_name} CT11 Watts
        id: ct11Watts
      gain_voltage: ${voltage_cal}
      gain_ct: ${current_cal}
    phase_c:
      power:
        name: ${disp_name} CT12 Watts
        id: ct12Watts
      gain_voltage: ${voltage_cal}
      gain_ct: ${current_cal}
    line_frequency: 60Hz
    gain_pga: 1X
    update_interval: ${update_time}
#IC1 AddOn 2
  - platform: atm90e32
    cs_pin: 27
    phase_a:
      power:
        name: ${disp_name} CT13 Watts
        id: ct13Watts
      gain_voltage: ${voltage_cal}
      gain_ct: ${current_cal}
    phase_b:
      power:
        name: ${disp_name} CT14 Watts
        id: ct14Watts
      gain_voltage: ${voltage_cal}
      gain_ct: ${current_cal}
    phase_c:
      power:
        name: ${disp_name} CT15 Watts
        id: ct15Watts
      gain_voltage: ${voltage_cal}
      gain_ct: ${current_cal}
    line_frequency: 60Hz
    gain_pga: 1X
    update_interval: ${update_time}
#IC2 AddOn 2
  - platform: atm90e32
    cs_pin: 17
    phase_a:
      power:
        name: ${disp_name} CT16 Watts
        id: ct16Watts
      gain_voltage: ${voltage_cal}
      gain_ct: ${current_cal}
    phase_b:
      power:
        name: ${disp_name} CT17 Watts
        id: ct17Watts
      gain_voltage: ${voltage_cal}
      gain_ct: ${current_cal}
    phase_c:
      power:
        name: ${disp_name} CT18 Watts
        id: ct18Watts
      gain_voltage: ${voltage_cal}
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

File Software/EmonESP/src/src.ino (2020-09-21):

/*
   -------------------------------------------------------------------
   EmonESP Serial to Emoncms gateway
   -------------------------------------------------------------------
   Adaptation of Chris Howells OpenEVSE ESP Wifi
   by Trystan Lea, Glyn Hudson, OpenEnergyMonitor

   Modified to use with the CircuitSetup.us Split Phase Energy Meter by jdeglavina

   All adaptation GNU General Public License as below.

   -------------------------------------------------------------------

   This file is part of OpenEnergyMonitor.org project.
   EmonESP is free software; you can redistribute it and/or modify
   it under the terms of the GNU General Public License as published by
   the Free Software Foundation; either version 3, or (at your option)
   any later version.
   EmonESP is distributed in the hope that it will be useful,
   but WITHOUT ANY WARRANTY; without even the implied warranty of
   MERCHANTABILITY or FITNESS FOR A PARTICULAR PURPOSE.  See the
   GNU General Public License for more details.
   You should have received a copy of the GNU General Public License
   along with EmonESP; see the file COPYING.  If not, write to the
   Free Software Foundation, Inc., 59 Temple Place - Suite 330,
   Boston, MA 02111-1307, USA.
*/

// See energy meter specific configuration in energy_meter.h
#define ENABLE_ENERGY_METER

// If USE_SERIAL_INPUT is defined, EmonESP will check the serial port for
// input. Only enable this if there is input expected on the serial port;
// otherwise it seems to read garbage data.
//#define USE_SERIAL_INPUT

#include <esp_task_wdt.h>
#include "emonesp.h"
#include "config.h"
#include "esp_wifi.h"
#include "web_server.h"
#include "ota.h"
#include "input.h"
#include "emoncms.h"
#include "mqtt.h"

#ifdef ENABLE_ENERGY_METER
#include "energy_meter.h"
#endif

static char input[MAX_DATA_LEN];

// -------------------------------------------------------------------
// SETUP
// -------------------------------------------------------------------
void setup() {
#ifdef ENABLE_WDT
  enableLoopWDT();
#endif

  Serial.begin(115200);
#ifdef DEBUG_SERIAL1
  Serial1.begin(115200);
#endif
  delay(200);

  // Read saved settings from the config
  config_load_settings();
  delay(200);

  // Initialise the WiFi
  wifi_setup();
  delay(200);

  // Bring up the web server
  web_server_setup();
  delay(200);

#ifdef ENABLE_WDT
  DBUGS.println("Watchdog timer is enabled.");
  feedLoopWDT();
#endif

#ifdef ENABLE_WEB_OTA
  // Start the OTA update systems
  ota_setup();
#endif

#ifdef ENABLE_ENERGY_METER
  energy_meter_setup();
#endif

  DBUGLN("Server started");

} // end setup

// -------------------------------------------------------------------
// LOOP
// -------------------------------------------------------------------
void loop()
{
#ifdef ENABLE_WDT
  feedLoopWDT();
#endif
  web_server_loop();
  wifi_loop();

#ifdef ENABLE_WEB_OTA
  ota_loop();
#endif

#ifdef ENABLE_ENERGY_METER
  energy_meter_loop();
#endif

  boolean gotInput = input_get(input);
  if (gotInput) {
    DBUGS.println(".");
  }

  if (wifi_client_connected()) {
    if (emoncms_apikey != 0 && gotInput) {
      //DBUGS.println(input);
      if (emoncms_server != 0) {
        emoncms_publish(input);
      }
    }
    if (mqtt_server != 0) {
      mqtt_loop();
      if (gotInput) {
        mqtt_publish(input);
      }
    }
  }

} // end loop

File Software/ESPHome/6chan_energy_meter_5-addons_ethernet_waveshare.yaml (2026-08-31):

# CircuitSetup 6 Channel Energy Meter Main Board + 5 Add-on Boards config
# Uses the Waveshare ESP32-S3-ETH and the CircuitSetup 6 Channel Energy Meter Ethernet WS Adapter 
# See all options at https://esphome.io/components/sensor/atm90e32.html

substitutions:
  csemh_config_contract: "2"
# Change the disp_name to something you want
  disp_name: energy-meter
  friendly_name: CircuitSetup Energy Meter 36x
# Interval of how often the power data is updated
  update_time: 10s
# Frequency of your electrical grid - 60Hz in North America, 50Hz otherwise
  electric_freq: "60Hz"

## The below names and IDs can be changed to whatever you want. IDs should not have spaces
## Main board
  main_meter_name1: Meter 1-3
  main_meter_name2: Meter 4-6
  main_meter_id1: meter_main1
  main_meter_id2: meter_main2
  ct1_name: CT1
  ct2_name: CT2
  ct3_name: CT3
  ct4_name: CT4
  ct5_name: CT5
  ct6_name: CT6
## Addon1
  addon1_name1: Addon1 7-9
  addon1_name2: Addon1 10-12
  addon1_id1: addon1_1
  addon1_id2: addon1_2
  ct7_name: CT7
  ct8_name: CT8
  ct9_name: CT9
  ct10_name: CT10
  ct11_name: CT11
  ct12_name: CT12
## Addon2
  addon2_name1: Addon2 13-15
  addon2_name2: Addon2 16-18
  addon2_id1: addon2_1
  addon2_id2: addon2_2
  ct13_name: CT13
  ct14_name: CT14
  ct15_name: CT15
  ct16_name: CT16
  ct17_name: CT17
  ct18_name: CT18
## Addon3
  addon3_name1: Addon3 19-21
  addon3_name2: Addon3 22-24
  addon3_id1: addon3_1
  addon3_id2: addon3_2
  ct19_name: CT19
  ct20_name: CT20
  ct21_name: CT21
  ct22_name: CT22
  ct23_name: CT23
  ct24_name: CT24
## Addon4
  addon4_name1: Addon4 25-27
  addon4_name2: Addon4 28-30
  addon4_id1: addon4_1
  addon4_id2: addon4_2
  ct25_name: CT25
  ct26_name: CT26
  ct27_name: CT27
  ct28_name: CT28
  ct29_name: CT29
  ct30_name: CT30
## Addon5
  addon5_name1: Addon5 31-33
  addon5_name2: Addon5 34-36
  addon5_id1: addon5_1
  addon5_id2: addon5_2
  ct31_name: CT31
  ct32_name: CT32
  ct33_name: CT33
  ct34_name: CT34
  ct35_name: CT35
  ct36_name: CT36

## Semi-Automatic Calibration ##
# See https://esphome.io/components/sensor/atm90e32.html#calibration
# WHEN CALIBRATION IS ENABLED, calculated values for offset and gain stored in memory take priority over config values
# To save calculated calibration values, copy them from the logs to your config
# then use the clear buttons to clear the calibration values from memory
# Values are stored in the variables for gain below and offsets in their corresponding files
# under /calibration/6chan_xxxx_offset_calibrations.yaml
  offset_calibration: "true"
  gain_calibration: "true"

## Gain Calibration Values ##
# Change current_cal_ctX value to the corresponding CT's that you're using
# For more precise calibration, see documentation for Semi-Auto calibration
# Current Transformers:
#  20A/25mA SCT-006: 11143
#  30A/1V SCT-013-030: 8650
#  50A/1V SCT-013-050: 15420
#  50A/16.6mA SCT-010: 41334
#  80A/26.6mA SCT-010: 41660
#  100A/50ma SCT-013-000: 27518
#  120A/40mA: SCT-016: 41787
#  200A/100mA SCT-024: 27518
#  200A/50mA SCT-024: 55036

## Main Board
  current_cal_ct1: '27518'
  current_cal_ct2: '27518'
  current_cal_ct3: '27518'
  current_cal_ct4: '27518'
  current_cal_ct5: '27518'
  current_cal_ct6: '27518'
## Addon1
  current_cal_ct7: '27518'
  current_cal_ct8: '27518'
  current_cal_ct9: '27518'
  current_cal_ct10: '27518'
  current_cal_ct11: '27518'
  current_cal_ct12: '27518'
## Addon2
  current_cal_ct13: '27518'
  current_cal_ct14: '27518'
  current_cal_ct15: '27518'
  current_cal_ct16: '27518'
  current_cal_ct17: '27518'
  current_cal_ct18: '27518'
## Addon3
  current_cal_ct19: '27518'
  current_cal_ct20: '27518'
  current_cal_ct21: '27518'
  current_cal_ct22: '27518'
  current_cal_ct23: '27518'
  current_cal_ct24: '27518'
## Addon4
  current_cal_ct25: '27518'
  current_cal_ct26: '27518'
  current_cal_ct27: '27518'
  current_cal_ct28: '27518'
  current_cal_ct29: '27518'
  current_cal_ct30: '27518'
## Addon4
  current_cal_ct31: '27518'
  current_cal_ct32: '27518'
  current_cal_ct33: '27518'
  current_cal_ct34: '27518'
  current_cal_ct35: '27518'
  current_cal_ct36: '27518'
# This only needs to be changed if you're using something other than the  
# Jameco 9VAC Transformer: 
  voltage_cal1: '7305'
  voltage_cal2: '7305'

esphome:
  name: ${disp_name}
  friendly_name: "${friendly_name}"
  name_add_mac_suffix: true
  min_version: '2025.5.0'
  project:
    name: circuitsetup.6c-energy-meter-5-addons-ethernet-waveshare
    version: "1.8"
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

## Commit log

2019-10-13 Eagle board files and schematics
    Changes for v1.3 from v1.2:
    Changes for voltage reading consistency:
    - Added resistor divider for N voltage channel
    - Changed voltage divider for voltage measurements from 100k (early builds) 20k (R26,R28))/10k (R27,R29) to 20k/1k, making the max input from a 12VAC transformer ~650mV
    - Added 20k voltage pull up resistors so voltage inputs on P and N are above 120mV (according to ATM90E32 data sheet)
    - Removed 10uf C37 (which caused interference in the voltage inputs)
    - Changed the name of secondary voltage pins from VC+/AGND to VA2+/VA2-
    - Removed a redundent footprint for CT connectors
    Changes from v1.3 to rev2 (main board), and rev1(add-on board):
    - Added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
    [6_channel_esp32_energy_meter_1.3_rev2.brd, 6_channel_esp32_energy_meter_1.3_rev2.sch, 6_channel_esp32_energy_meter_add-on_1.3_rev1.brd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]
2019-11-10 "rev2" should have been "rev1"
    [6_channel_esp32_energy_meter_1.3_rev1.brd, 6_channel_esp32_energy_meter_1.3_rev1.sch]
2019-11-10 New 2 piece cases
    [6channel_energy_meter_2piece_case_1-addon_small_half.stl, 6channel_energy_meter_2piece_case_2-addon_small_half.stl, 6channel_energy_meter_2piece_case_3-addon_s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]
2020-01-03 fixed extra spaces on phase b power
    [6chan_energy_meter-add-on_jp9-jp11.yaml]
2020-02-24 Update and rename 6chan_energy_meter-add-on_jp9-jp11.yaml to 6chan_energy_meter-add-on_jp8-jp11.yaml
    - added ct calibrations
    - removed unnecessary frequency and voltage sensors from add-on
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2020-03-03 rename files
    [6_channel_esp32_energy_meter.brd, 6_channel_esp32_energy_meter.sch, 6_channel_esp32_energy_meter_add-on.brd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]
2020-03-03 v1.3 rev2
    – Added voltage divider on ground for voltage channel 2
    [6_channel_esp32_energy_meter.brd, 6_channel_esp32_energy_meter.sch, 6_channel_esp32_energy_meter_add-on.brd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]
2020-03-03 v1.4
    - Added optional micro-hdmi connection to connect the current transformer remote board. This allows for all 6 current transformer connections to connect to a remote pcb, which then connects to the ma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
    - Added current transformer remote pcb
    - Removed JP8-JP11 and connected all voltage channels together for each ATM90E32
    [6_channel_esp32_energy_meter.brd, 6_channel_esp32_energy_meter.sch, 6_channel_esp32_energy_meter_add-on.brd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]
2020-03-03 v1.1 remote
    - changed micro-hdmi connector to through-hole
    - added mini-hdmi connector option
    [6_channel_remote.brd, 6_channel_remote.sch]
2020-03-03 v1.4 rev1
    - Changed micro-hdmi connector to through-hole
    - Changed spacing on VA2+/VA2- (voltage 2 connection) to 3.5mm to allow for standard screw connectors
    [6_channel_esp32_energy_meter.brd, 6_channel_esp32_energy_meter.sch]
2020-04-05 Support individual sensor calibrations for every input Adds configurable current and power multiplification factors Auto detects add-on boards Optimize EEPROM storage to accommodate new features
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2020-04-06 Disable WiFi LED as it conflicts with CS for add-on board 2
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2020-04-21 Update watchdog timer Timer is fixed at 5 seconds in IDF, this means that HTTP timeout would previously trigger watchdog
2020-05-06 Fix curly bracket in mqtt_publish
2020-09-21 add JSON formatting option for MQTT output and adds ability to give a friendly name to each sensor
2020-09-22 set debug options correctly
    [debug.h]
2020-09-22 renamed src_6chan.ino to src.ino to prevent error in Arduino IDE
    [src.ino]
2021-03-16 Update README.md
    Added an alternate way to hook up to a 3-phase system. Better if one needs a roughly-equal number of current sensors per phase.
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2021-08-16 Correct compile errors
    ESPHome was complaining about a few things with the power: block in one section and some other random names
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2022-02-04 Update 6chan_energy_meter-add-on_jp8-jp11.yaml
    added device classes and state class for total daily energy
2022-02-17 Updated Eagle files to v1.4 rev1
    [6_channel_esp32_energy_meter.brd, 6_channel_esp32_energy_meter.sch, 6_channel_esp32_energy_meter_add-on.brd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]
2022-10-12 screw connector version of 6 add-on board case
    [6channel_energy_meter_2piece_case_6-addon_small_half_screw-connector.stl]
2022-10-25 screw connector case
    [6channel_energy_meter_2piece_case_main_large_half_screw-connector.stl, 6channel_energy_meter_2piece_case_main_small_half_screw-connector.stl]
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2023-10-16 Update README.md
    Correct 3-phase CT clamp phase description as also mentioned here:
    https://github.com/CircuitSetup/Expandable-6-Channel-ESP32-Energy-Meter/issues/138
2024-05-27 Fixes power class for watts in example
2024-08-16 add ethernet case
    [6channel_energy_meter_2piece_case_cover_ethernet.stl, 6channel_energy_meter_2piece_case_main_ethernet_large_half.stl, 6channel_energy_meter_2piece_case_main_et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]
2024-08-21 add ethernet adapter cases
    [6channel_energy_meter_2piece_case_1-addon_ethernet_large_half.stl, 6channel_energy_meter_2piece_case_1-addon_ethernet_small_half.stl, 6channel_energy_meter_2pi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]
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2025-02-05 Ethernet adapter gerber files
    [copper_bottom.gbr, copper_top.gbr, gerber_job.gbrjob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]
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2025-06-23 change back to esp-idf
    upcoming ESPHome update to allow more than 6 SPI devices on esp-idf
    changing between arduino and esp-idf requires a serial connection to your ESP32
    no changes required if your build is working
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2025-07-01 3 phase case
    [6channel_energy_meter_2piece_case_5-addon_small_half_3-phase_voltage.stl, 6channel_energy_meter_2piece_case_6-addon_small_half_3-phase_voltage.stl]
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2025-07-01 create additional addon files and add more comments to files
    [6chan_addon2_calibration.yaml, 6chan_addon2_offset_calibrations.yaml, 6chan_addon3_calibration.yaml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]
2025-07-03 Update 6chan_common.yaml
    added uptime sensor & changed restart from switch to button
2025-07-03 Update 6chan_common_ethernet.yaml
    added debug and uptime sensors, changed restart from switch to button
2025-07-03 Update 6chan_common.yaml
    added ids to debug and uptime sensors, removed device info, Heap max block, CPU frequency, added entity_category where necessary
2025-07-03 Update 6chan_common_ethernet.yaml
    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
2025-07-11 Update 6chan_addon3.yaml
    fix ct19
    [6chan_addon3.yaml]
2025-07-16 Move ESPHome configs to examples directory
    [6chan_main_calibration_beta.yaml]
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2025-07-28 Fix addon numbering and total amps calculation
    Corrected the numbering of Addon5 and Addon6 in the calibration section and updated the total amps calculation to include totalAmpsAddOn5. This ensures all add-ons are properly accounted for in the total current measurement.
    [6chan_energy_meter_6-addons_ethernet.yaml]
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2026-02-12 Add 6-channel energy meter Waveshare Ethernet cases
    [6channel_energy_meter_2piece_case_1-addon_ethernet_ws_large_half.stl, 6channel_energy_meter_2piece_case_1-addon_ethernet_ws_small_half.stl, 6channel_energy_met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]
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2026-08-22 feat: expose gain calibration for all meter boards
    [6chan_addon1_calibration.yaml, 6chan_addon2_calibration.yaml, 6chan_addon3_calibration.yaml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]
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2026-08-22 fix: place calibration reference bounds per phase
    [6chan_addon1_calibration.yaml, 6chan_addon2_calibration.yaml, 6chan_addon3_calibration.yaml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]
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2026-08-25 Publish the Energy Meter Helper configuration contract (#234)
    * feat(esphome): publish helper configuration contract
    * fix(esphome): tighten configuration contract documentation
    * test: enforce energy meter helper contract
    * test: tighten helper contract validation
    * test: harden helper contract mutations
    * test: expand helper contract mutation coverage
    * test: cover helper contract scope mutations
    * test: harden helper contract validation
    * test: close helper contract review gaps
    [6chan_energy_meter_1-addon_ethernet_waveshare.yaml, 6chan_energy_meter_2-addons_ethernet_waveshare.yaml]

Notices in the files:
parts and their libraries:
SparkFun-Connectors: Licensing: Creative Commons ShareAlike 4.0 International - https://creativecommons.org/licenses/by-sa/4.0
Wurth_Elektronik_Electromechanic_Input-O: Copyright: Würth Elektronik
